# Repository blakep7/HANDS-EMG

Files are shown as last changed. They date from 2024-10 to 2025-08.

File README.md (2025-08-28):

# HANDS-EMG

**HANDS-EMG** is a real-time embedded system designed to read a user's EMG signals and classify their hand movements.

## Project Description
A battery-powered surface electromyography (sEMG) sensor system designed to classify hand movements based on the wearer's muscle activity.
The device utilizes four channels of wet electrodes placed on the user's forearm to capture sEMG signals.
These signals are processed through our procured analog front-end module operating at 2000Hz.
The digitized signals are transmitted to our microcontroller via SPI, where a machine learning algorithm classifies the hand movements based on a pre-trained model.
The system will output the movement classifications via USB, which can be visualized on a PC simulator.
Designed for efficiency, the device operates at a voltage of 3.7V provided by a rechargeable lithium polymer battery for portability.
The current ML model only classifies 3 hand movements: Wrist Flexion, Wrist Extension, and Fist Clench.

## Videos
[Project Overview (Entire Design Process)](https://www.youtube.com/watch?v=24S8prk70tI)

[Demo Video](https://www.youtube.com/watch?v=GeJwxeHSsiM)

## Team

- Blake Pearson
- Noah Marosok
- Kelly Hubbard
- Jayden Sumbillo
- Kirk Young

## About
Developed at **San Diego State University**.

**College of Engineering** -- **Department of Electrical and Computer Engineering (ECE)**

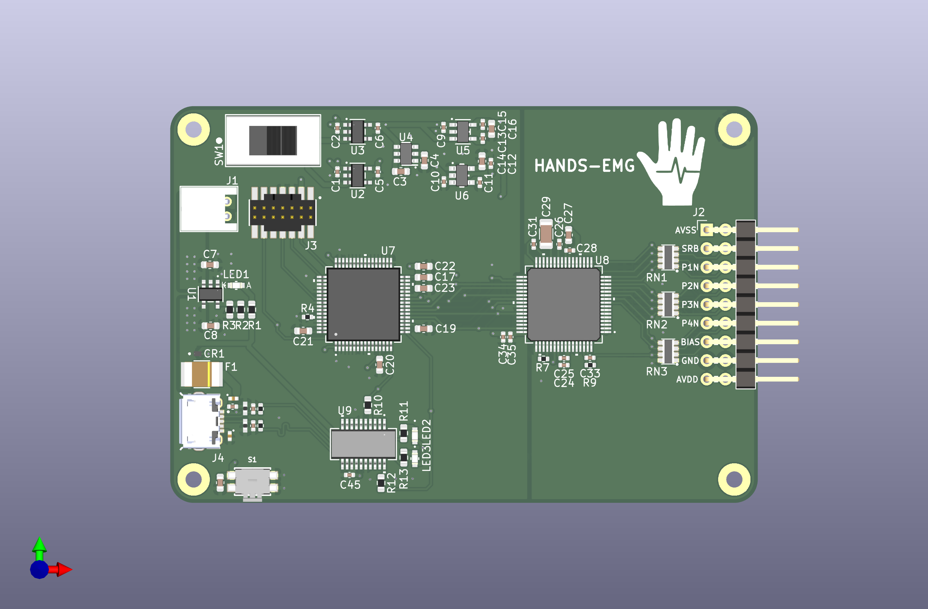
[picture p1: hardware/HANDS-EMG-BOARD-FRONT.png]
Final Board Top 3D Model


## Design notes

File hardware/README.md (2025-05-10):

# PCB Projects
Welcome to the PCB repository! This folder contains four PCB phases:

- **Phase 1**
- **Phase 2**
- **Phase 3**

Each project is fully designed in KiCad and includes schematics, PCB layouts, and 3D models.

## Phase Descriptions

### Phase 1

**Description:**  
Contains 3 PCBs, each designed with a specific purpose.

**Key Components:**
- PMIC Board: Provide power to the following two PCBs
- ADS1299 Board: Our AFE board that handles processing and digitizing EMG signals
- STM32 Board: Our uC board that handles classification and compute

**Warnings**
- Do not use this phase, it taught us alot about PCB design but is riddled with issues
- PMIC Board is less than 50% functional.
    - 3.3V line is actually 3.6V which is absolute maximum of STM32
    - -2.5V line is unstable, due to only using a charge pump without a LDO after
- ADS1299 Board is not functional
    - Unknown issue in PCB design that kills the IC.

### Phase 2

**Description:**  
The team's attempt at a fully integrated PCB design.

**Warnings**
- Do not use this phase
- Board's USB to UART is not functional, no communication possible
- SWD footprint is mirrored

### Phase 3 (Final Phase)

**Description:**
The team's final design. Focused on simplicity, cost, and small dimensions. Fully tested and working

**Key Components**
- STM32L0: Our main compute, has the ML model and classifies the signals
- ADS1299: Our AFE, handles amplifying and digitizing our EMG signals
- FT231X: USB->UART IC for simple communication between STM32 and PC

---

## 3D Model Previews

**Final PCB 3D View:**  
Final Board Top 3D Model
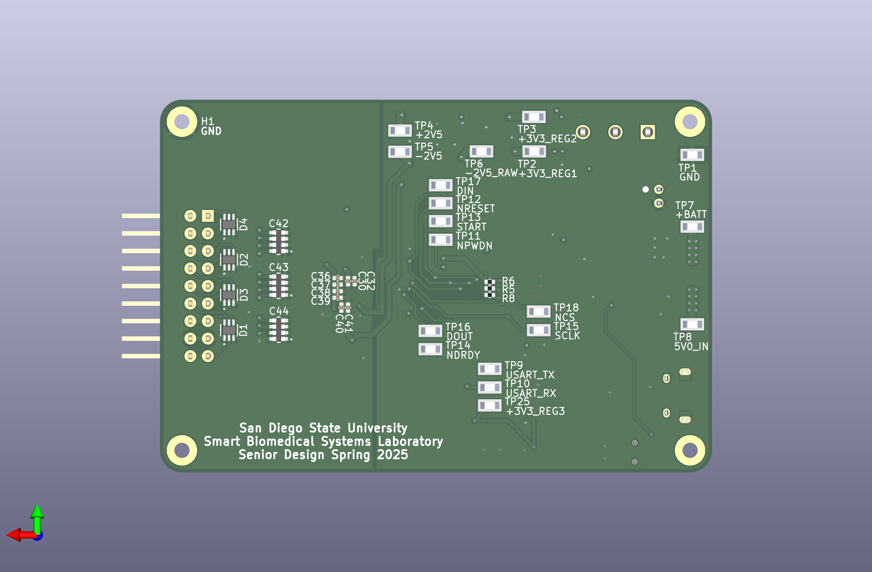
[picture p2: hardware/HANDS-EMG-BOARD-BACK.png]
Final Board Bottom 3D Model


---

## How to Open the Projects

1. Install [KiCad](https://kicad.org/) (v9).
2. Open KiCad and navigate to the respective folder (`phase3`).
3. Open the `.kicad_pro` project file inside each folder.

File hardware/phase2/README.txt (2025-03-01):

How to add components to our hands-emg-lib

1. Download the following from Ultra Librarian (https://app.ultralibrarian.com/)
	- Symbol (.kicad_sym)
	- Footprint (.kicad_mod) (Ignore the -L or -M footprints, use the normal one)
	- 3D Model (.stp or .step)
	* My typical download process
		* 3D CAD Model: Check STEP
		* KiCAD: Check KiCAD v6+
		* Symbol Pin Ordering: Designers preference, read the (i) to understand what this is.
		  Download both and compare to see which one would make a cleaner schematic.
		* Footprint Units: Metric (mm)
	
1b. If you cannot find the component on Ultra Librarian, check Component Search Engine (https://componentsearchengine.com/)
	- Don't mix and match symbols and footprints from different websites
	- If you cant find the components 3d model on ultralibrarian, its fine to download the 3d model from component search engine and attach to footprint from ultralibrarian.
	
1c. After downloading all the files it will be a zip do the following
	- Extract the zip to some folder on your PC.
	- Rename all the files to be the same name (typically part number)
	  Heres an example before and after with the ADS1299 from Ultra Librarian
			Before: 2025-03-01_06-35-12.kicad_sym
					PAG0064A.stp
					PAG64_TEX.kicad_mod
					
			After:  ADS1299-4PAGR.kicad_sym
					ADS1299-4PAGR.stp
					ADS1299-4PAGR.kicad_mod
	
2. Copy the 3d model file from the download into the hands-emg-lib.3dshapes.

3. Import the footprint
	- Open the KiCad Footprint Editor
	- Filter hands-emg-lib
	- Right click hands-emg-lib
	- Import Footprint
	- Select the footprint file from the download
	- Open the footprints properties menu
		- Check the "Value" and confirm its the proper manufacturer's part number (if you had to rename footprint file then it's likely incorrect)
		- Add a description of what it is (typically not part number, the description helps to search the part)
		- Go to the 3D model tab
		- Click the little folder icon to add 3d model
		- Select the 3d model file in the hands-emg-lib.3dshapes folder
		- Rotate/Offset model to fit the footprint (scaling is needed in very few cases)
	- Click OK to close the footprint properties menu
	- File -> Save
	- Dont change the name, filter for hands-emg-lib, click hands-emg-lib, click OK.
	
4. Import the symbol
	- Open the KiCad Symbol Editor
	- Filter hands-emg-lib
	- Right click hands-emg-lib
	- Import Symbol
	- Select the symbol file from the download
	- Open the symbol properties menu
		- Click on footprint
		- Click on the little books icon to open the "footprint chooser"
		- Filter for hands-emg-lib
		- Select the footprint imported in step 3 under hands-emg-lib (for this component)
		- Click OK
		- Add datasheet link under "Datasheet" field
		- Add description
		- Create new field
			- Click '+' symbol
			- Name this field procurement
			- Make sure to un-check the show column for this field
			- Provide purchase link for this component
				- Try to keep it all from DigiKey
				- No obsolete parts, no limited stock, must be immediately aviable, no lead time
		- Click OK to close symbol properties menu
	- File -> Save
	
5. Commit these changes to git and push so we all have easy access to the components.

6. Use your imported component. (Seach for hands-emg-lib in symbol/footprint selection menu when placing)

7. You can delete the downloaded files from your downloads folder, importing them has copied them all to our project.

Note! This library is 'project' scoped, there is no need to edit any of your kicad settings to use it. It will not be aviable in other projects.

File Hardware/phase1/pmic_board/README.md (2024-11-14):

# HANDS-EMG

## Hand Activity Neural Detection using SEMG

## Project Description
A battery-powered surface electromyography (sEMG) sensor system designed to classify hand movements based on the wearer's muscle activity.
The device utilizes four channels of wet electrodes placed on the user's forearm to capture sEMG signals.
These signals are processed through our procured analog front-end module operating at a minimum of 2000 samples per second.
The digitized signals are transmitted to our microcontroller via SPI, where a machine learning algorithm classifies the hand movements based on a pre-trained model.
Our responsibilities include configuring the analog front-end module, programming a low-power microcontroller, integrating the system on a custom PCB, and training the machine learning model for accurate classification.
The system will output the movement classifications via USB, which can be visualized on a PC simulator.
Designed for efficiency, the device operates at a voltage of 3.7V provided by a rechargeable lithium polymer battery for portability.

## Contributors

- Kelly Hubbard
- Noah Marosok
- Blake Pearson
- Jayden Sumbillo
- Kirk Young

## License 📜

This project is licensed under the [Apache License 2.0](LICENSE).

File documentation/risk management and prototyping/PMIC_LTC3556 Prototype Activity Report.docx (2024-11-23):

Prototype Activity:

PCB Design

This report outlines the prototyping activities conducted to address two significant risks identified during the risk management meeting: PCB Design Complexity (Risk 5) and System Integration (Risk 6). The primary focus was on completing 20% of the PCB design process, including schematic creation, component placement, and routing in KiCad. The team conducted extensive Design Rule Checks (DRC) to identify and resolve errors early in the design phase, ensuring the designs are ready for fabrication and debugging. While physical testing is not yet possible, this phase lays a strong foundation for addressing these risks in future iterations.

System Description

The HANDS-EMG system relies on multiple subsystems to achieve functionality:

1. Power Management: The LTC3556EUFD_PBF provides efficient battery charging and a stable 3.3V output, powering all critical components.
2. Signal Processing: The ADS1299 captures and processes surface electromyography (sEMG) signals, which are then transmitted via SPI to the control module.
3. Control Module: The STM32L496ZGT6 microcontroller processes incoming data and facilitates communication between the signal processing and the machine learning classifier.

Given the complexity of integrating these subsystems, the team adopted a modular approach. Three separate PCBs were designed for power management, signal processing, and control modules. These modular designs allow for isolated testing and debugging before integration into a single unified PCB.

### Initial Identification of Risks

The risk management meeting identified the following significant risks for the project, with this activity addressing Risks 5 and 6:

Table X: Risk Summary

No. | Risk | Probability | Impact | Mitigation
5 | PCB Design Complexity | 3 | 4 | Designed modular PCBs for debugging before integration.
6 | System Integration | 3 | 5 | Tested modules individually with debugging tools before integration.

1. PCB Design Complexity (Risk 5): Routing, signal integrity, and managing space for components like the LTC3556EUFD_PBF, ADS1299, and STM32L496ZGT6 make PCB design challenging. Errors in design could delay the project or result in fabrication failures.
2. System Integration (Risk 6): The subsystems must communicate effectively through SPI and power lines. Inconsistencies or misalignments in protocols, signals, or power delivery could jeopardize the system’s functionality

Prototype Activity

This activity focused on the initial PCB design phase, addressing 20% of the overall design effort and emphasizing schematic creation, layout design, and error identification through DRC. Key steps included:

1. Schematic Design:

Created schematics for power management, signal processing, and control modules in KiCad, using recommended components from the manufacturer datasheets.

Included decoupling capacitors, inductors, and connectors to ensure proper functionality and ease of debugging.

PCB Layout Design:

Power Management PCB: Designed for the LTC3556EUFD_PBF, focusing on stable 3.3V output and efficient battery charging with minimal ripple.

1. Design Rule Checks (DRC):

Conducted DRC in KiCad to identify and resolve routing errors, ensuring proper trace clearances, via placements, and component footprints.

Resolved all detected issues, such as overlapping traces and incorrect pad connections, to ensure compliance with manufacturing standards.

2. Debugging Preparation:

Added test points and connectors to each PCB to facilitate real-time monitoring and troubleshooting during future testing.

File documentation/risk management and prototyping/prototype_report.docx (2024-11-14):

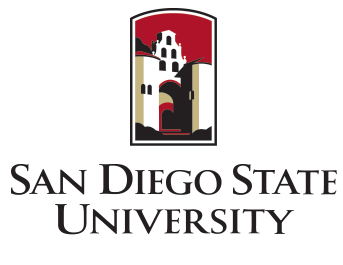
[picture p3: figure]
sdsu_logo - M @ College

College of Engineering, Department of Electrical and Computer Engineering

EE/COMPE 491W Senior Design

Prototype Report

Team HANDS-EMG

ECE Team 9 – Hand Activity Neural Detection using sEMG

EE Members:

Kelly Hubbard, Jayden Sumbillo, Kirk Young

CE Members:

Noah Marosok, Blake Pearson

Sponsor:

SDSU Department of Electrical and Computer Engineering

SDSU Smart Biomedical Systems Lab

Kelly Hubbard Electrical Engineering | Jayden Sumbillo Electrical Engineering | | Kirk Young Electrical Engineering

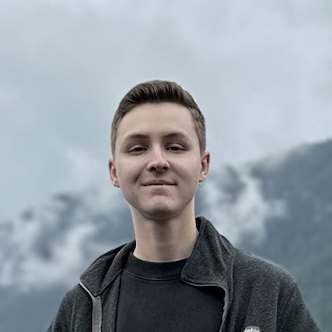
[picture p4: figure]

Noah Marosok Computer Engineering | | Blake Pearson Computer Engineering

No table of figures entries found.

# Executive Summary

Our ECE team is developing a battery-powered surface electromyography (sEMG) sensor system designed to classify hand movements based on the wearer’s muscle activity. The device utilizes four channels of wet electrodes placed on the user’s forearm to capture sEMG signals. These signals are processed through our procured analog front-end module operating at a minimum of 2000 samples per second. The digitized signals are transmitted to our microcontroller via SPI, where a machine learning algorithm classifies the hand movements based on a pre-trained model. Our responsibilities include configuring the analog front-end module, programming a low-power microcontroller, integrating the system on a custom PCB, and training the machine learning model for accurate classification. The system will output the movement classifications via USB, which can be visualized on a PC simulator. Designed for efficiency, the device operates at a voltage of 3.7V provided by a rechargeable lithium polymer battery for portability.

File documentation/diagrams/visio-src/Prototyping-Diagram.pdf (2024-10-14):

## Phase 1:

### Isolated Subsystem Prototyping

## Phase 2:

### Subsystem Integration Pairing

## Phase 3:

### Total Subsystem Integration

## Phase 4:

### Subsystem Integration on PCB

## Phase 5:

### Total System Integration on PCB

-ADS Eval kit is
configured to find
proper biasing of
amplifier to match
training data
-STM32 FSM
subroutines are
designed and
tested
-Power delivery
tested on
breadboard with DC
bench supply with
voltage swing
-Machine learning
architecture is
created and tested
with existing
dataset
-SPI comms.
Established verified
by logic analyzer

-ADS and STM32 SPI
comm. Established

-ADS and STM32
powered with
simulated
computational load
from power
delivery circuit

-Machine learning
model (.tflite)
uploaded to STM32
aiming to classify
training data
gestures via USB 2.0

-Simulator
demonstrates
proper articulation
of poses

-Breadboard power
system supplies to
both eval kits, EMG
measurements
passed to STM,
inference passed to
simulator
-Every subsystem is
now connected as
demonstrated
within the main
block diagram

-Development of
PCB for each
individual
subsystem, with
their respective I/O,
or ESD
considerations
accounted for.
Same system setup
as phase 3
-multi-layer boards
for high pin IC
packages
-heat dissipation
assemblies for
packages past
ambient
temperature
dissipation
threshold

-Total integration of
all subsystems on
one PCB
-PCB subsystems
routed with
considerations for
additional noise
and heat
-added layers

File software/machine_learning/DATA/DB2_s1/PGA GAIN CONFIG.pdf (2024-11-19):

Using PGA GAIN 12
Solid mid area, in case of muscle tense or cramp (happens often with this) gain not at highest can be okay with those high signal spikes if they happen while still capturing everything we need

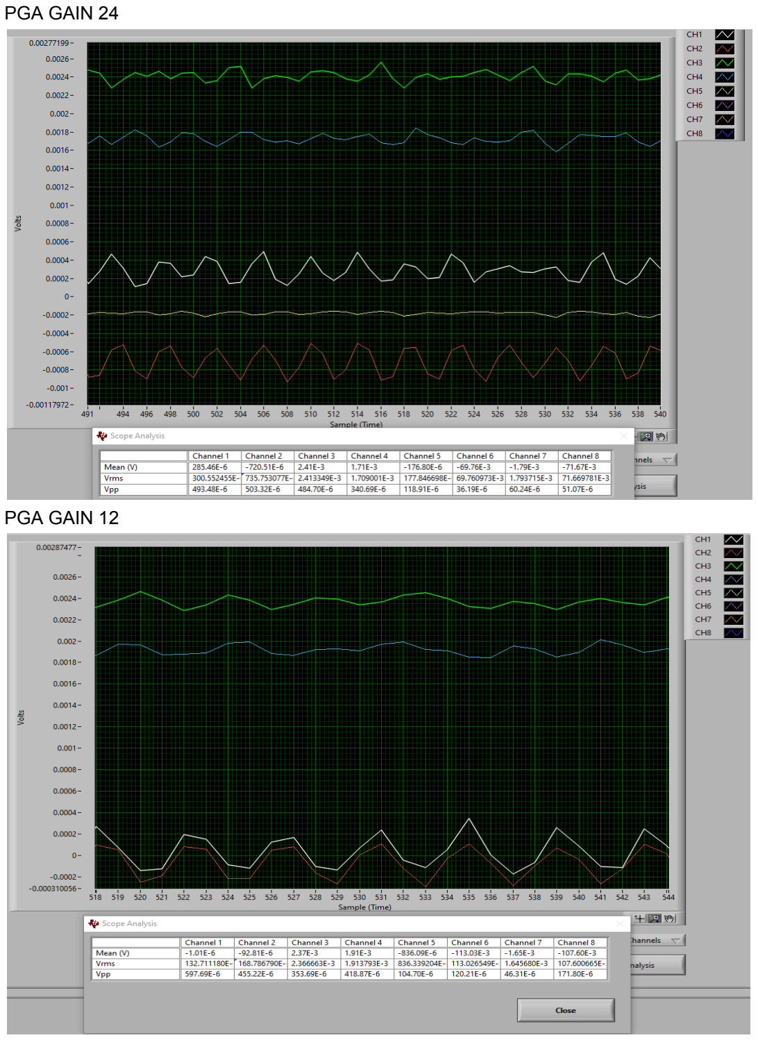
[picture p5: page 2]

PGA GAIN 24

PGA GAIN 12

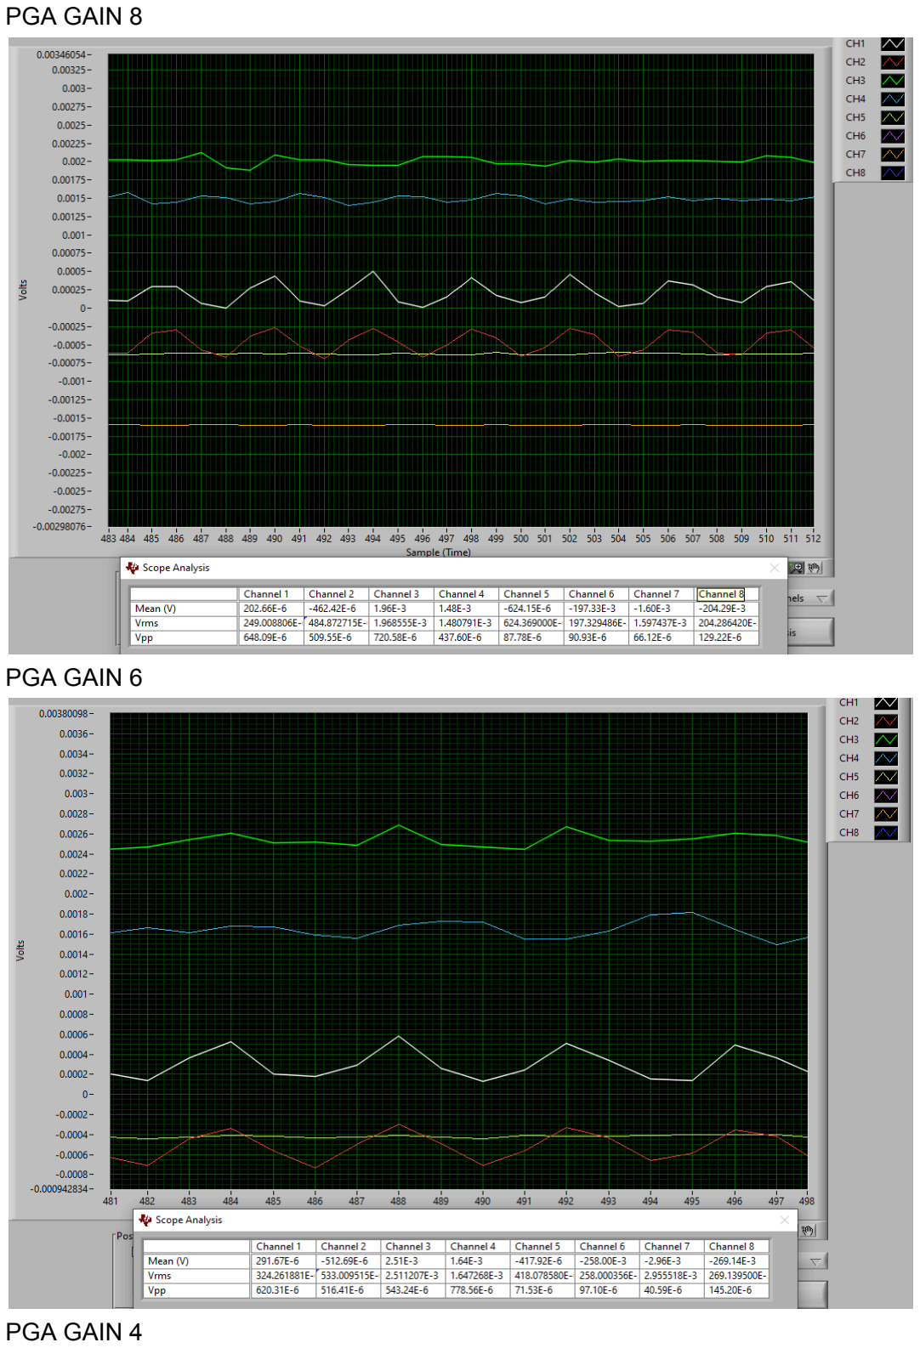
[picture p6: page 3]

PGA GAIN 8

PGA GAIN 6

PGA GAIN 4

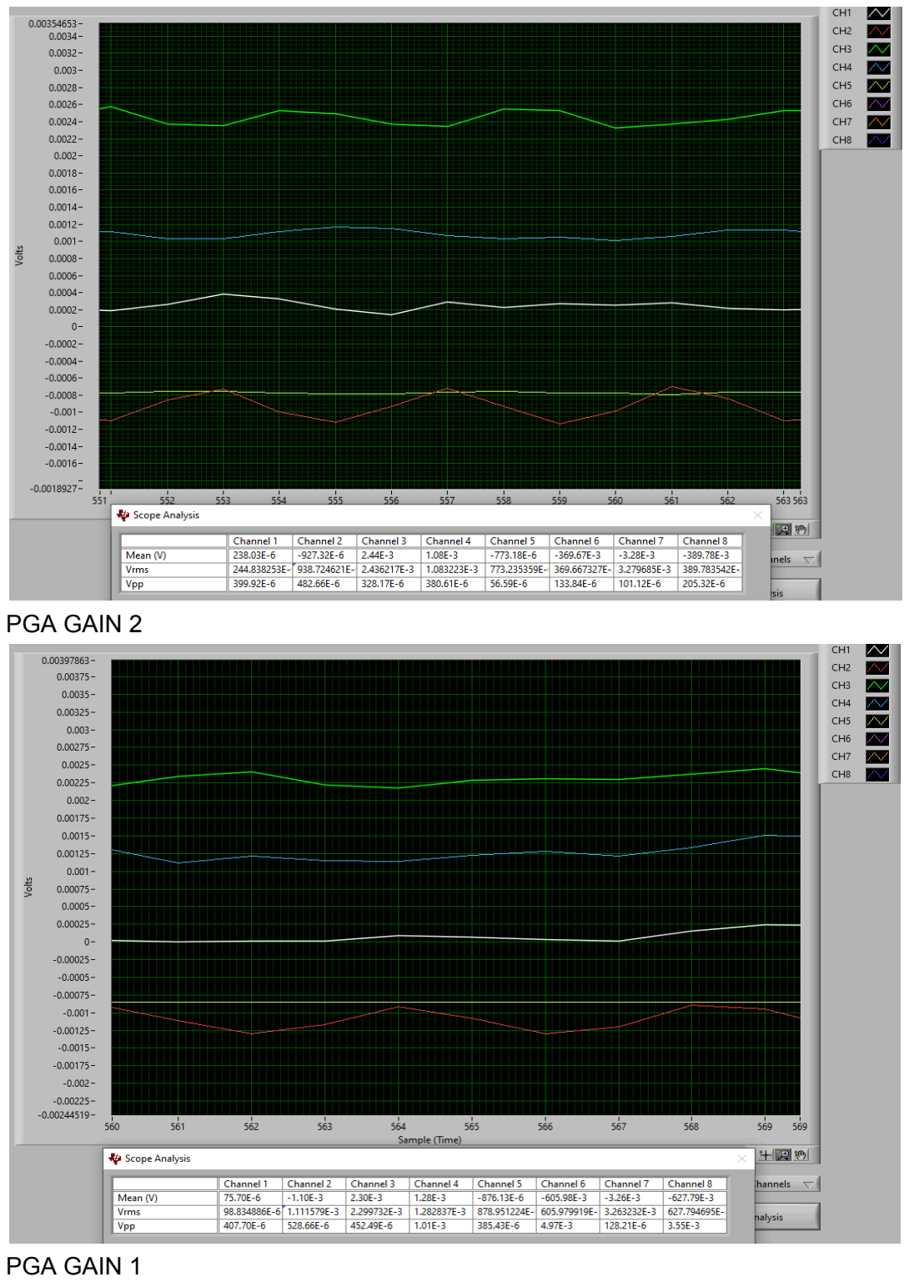
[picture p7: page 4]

PGA GAIN 2

PGA GAIN 1

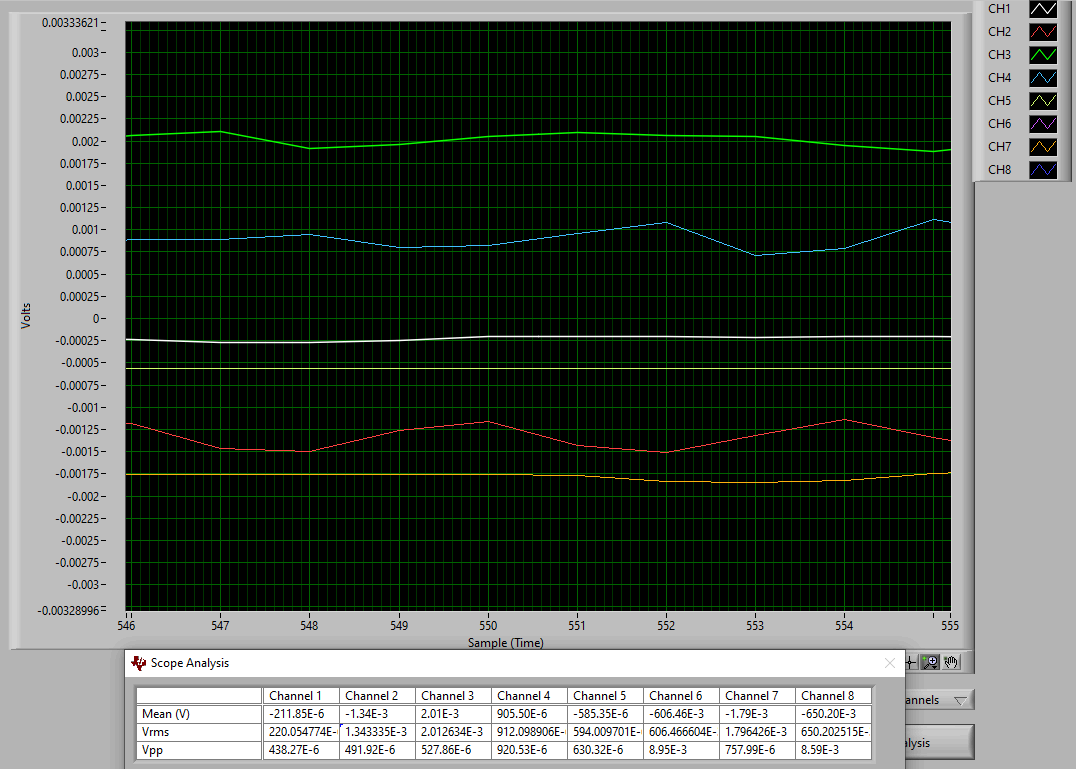
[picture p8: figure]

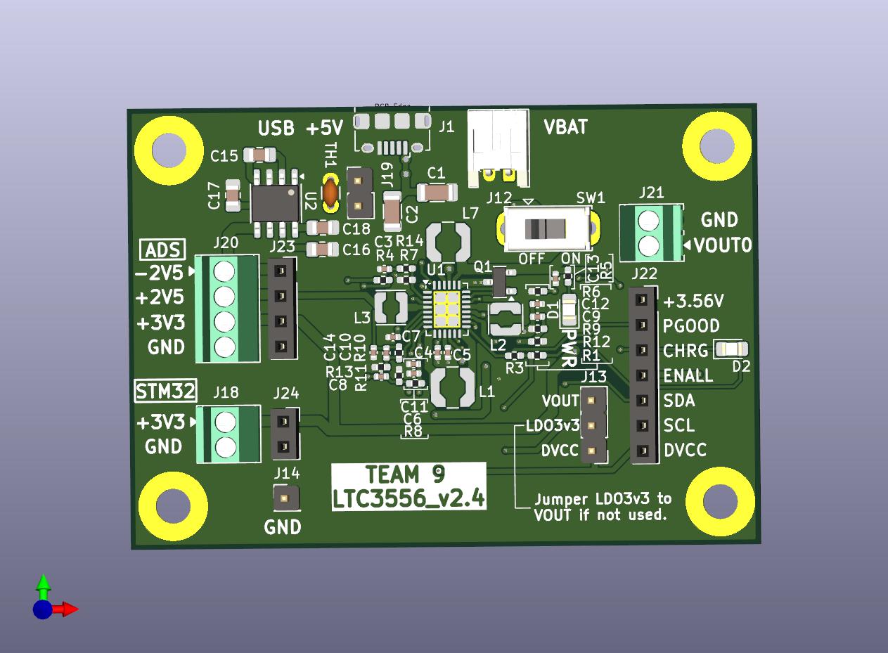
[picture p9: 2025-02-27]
hardware/phase1/pmic_board/LTC3556_v2.4.jpg

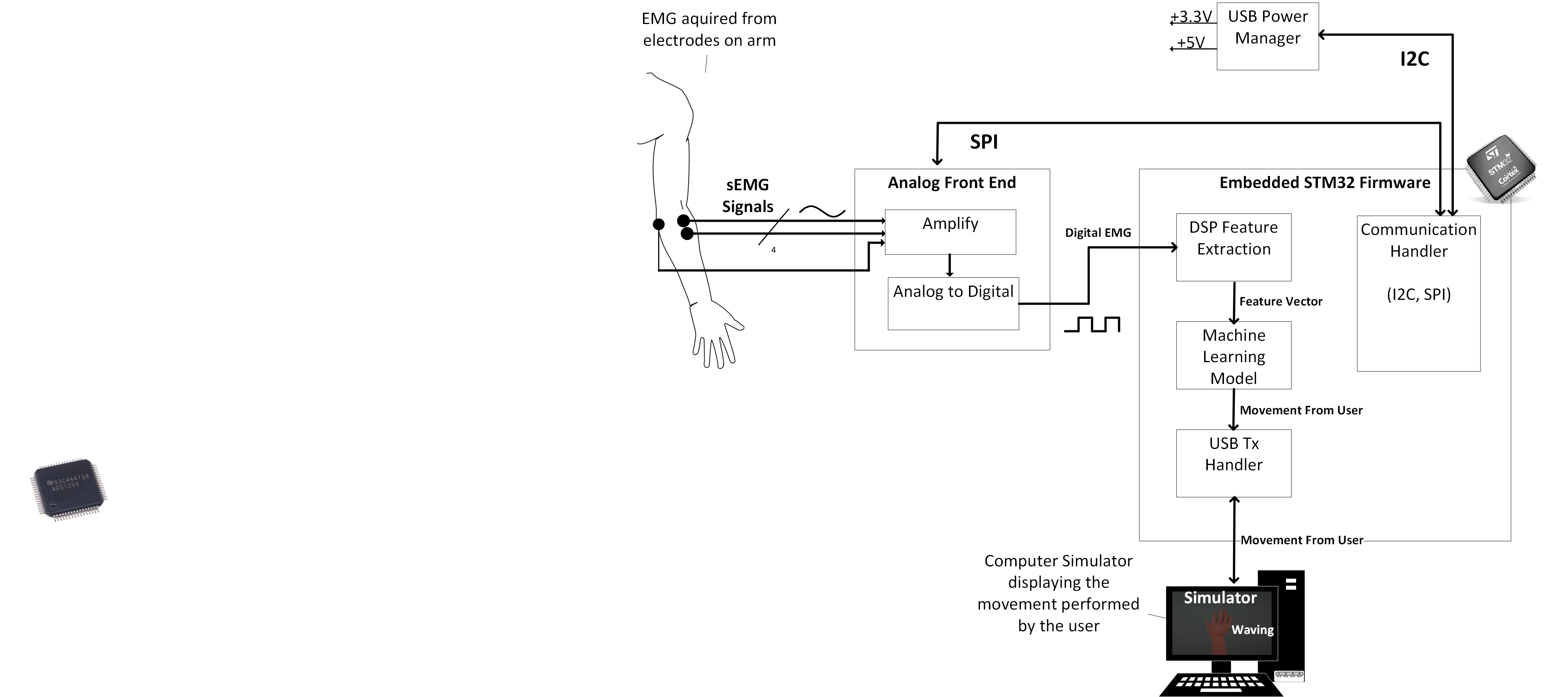
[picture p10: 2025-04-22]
documentation/system description and design/integration-rediness-report-pics/Software.png

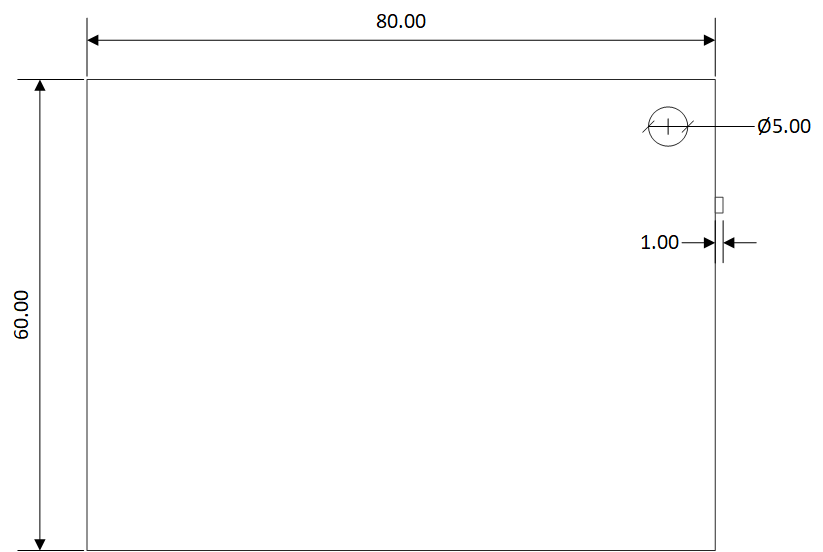
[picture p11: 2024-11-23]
documentation/diagrams/visio-src/Mechanical-Drawing-topdown.vsdx.png

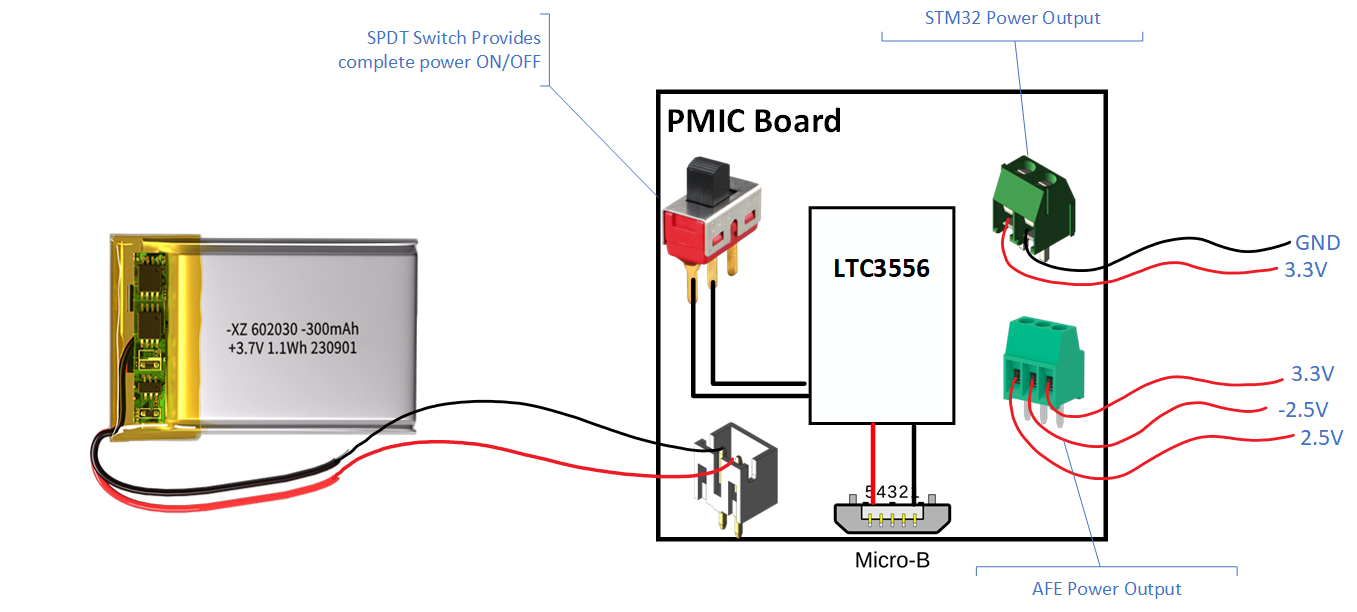
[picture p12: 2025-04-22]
documentation/system description and design/integration-rediness-report-pics/PMIC_Simple.png

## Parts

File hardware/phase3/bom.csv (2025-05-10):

Designator | Footprint | Quantity | Value | LCSC Part #
C1, C10, C12, C15, C2, C5, C6, C9 | 0402 | 8 | 2u2 |  | GRM155R61C225KE44D
C11, C48 | 0402 | 2 | 0u01 |  | CC0402KRX7R7BB103
C13, C24, C26, C30, C31, C32, C34, C36, C38, C40 | 0402 | 10 | 1u |  | CC0402KRX7R5BB105
C14, C16, C27, C3, C4 | 0603 | 5 | 10u |  | GRM188C80G106KE47D
C17, C19, C20, C21 | 0603 | 4 | 100n |  | CC0603KRX7R7BB104
C18 | 0603 | 1 | 0u1 |  | CC0603KRX7R7BB104
C22, C7, C8 | 0603 | 3 | 4u7 |  | CL10A475KP8NNNC
C23 | 0603 | 1 | 1u |  | CC0603KRX7R5BB105
C25, C28, C35, C37, C39, C41, C45 | 0402 | 7 | 0u1 |  | CC0402KRX7R7BB104
C29 | 1206 | 1 | 100u |  | CC1206MKX5R5BB107
C33 | 0402 | 1 | 1n |  | CC0402KRX7R7BB102
C42, C43, C44 | CA064C102K5RAC7800 | 3 | CA064C102K5RACTU |  | CA064C102K5RACTU
C46, C47 | 0402 | 2 | 47p |  | CC0402JRNPO9BN470
CR1 | ESDALC6V1-1M2 | 1 | ESDALC6V1-1M2 |  | ESDALC6V1-1M2
D1, D2, D3, D4 | TPD4E1B06DCKR | 4 | TPD4E1B06DCKR |  | TPD4E1B06DCKR
F1 | MF-MSMF050-2 | 1 | MF-MSMF050-2 |  | MF-MSMF050-2
FL1, FL2 | MPZ1005S300CT000 | 2 | MPZ1005S300CT000 |  | MPZ1005S300CT000
H1, H2, H3, H4 | MountingHole_2.2mm_M2_Pad | 4 | MountingHole_Pad |  | DNP
J1 | S2B-PH-K-S | 1 | S2B-PH-K-SLFSN |  | S2B-PH-K-SLFSN
J2 | PinHeader_2x09_P2.54mm_Horizontal | 1 | Conn_02x09_Odd_Even |  | PH2RA-18-UA
J3 | FTSH-107-01-L-DV-K | 1 | FTSH-107-01-L-DV-K |  | FTSH-107-01-L-DV-K
J4 | 10118194-0001LF | 1 | 10118194-0001LF |  | 10118194-0001LF
LED1, LED3 | LTST-C191KRKT | 2 | LTST-C191KRKT (RED) |  | LTST-C191KRKT (RED)
LED2 | LTST-C191KGKT | 1 | LTST-C191KGKT (GREEN) |  | LTST-C191KGKT (GREEN)
R1 | 0603 | 1 | 330R |  | RC0603JR-07330RL
R10, R11, R12, R13 | 0603 | 4 | 1K |  | RC0603FR-071KL
R14, R15 | 0402 | 2 | 22R |  | RC0402FR-0722RL
R16, R17 | CG0402MLC-05LG | 2 | CG0402MLC-05LG |  | CG0402MLC-05LG
R2 | 0603 | 1 | DNP |  | DNP
R3 | 0603 | 1 | 2K |  | RC0603FR-072KL
R4, R5, R6, R7, R8 | 0402 | 5 | 10K |  | ERJ-2RKF1002X
R9 | 0402 | 1 | 1M |  | RC0402JR-071ML
RN1, RN2, RN3 | CAY16-222J4LF | 3 | CAY16-222J4LF |  | CAY16-222J4LF
S1 | 4.36331E+11 | 1 | 4.36331E+11 |  | 4.36331E+11
SW1 | SLW-1276864-4A-D | 1 | SLW-1276864-4A-D |  | SLW-1276864-4A-D
TP1, TP10, TP11, TP12, TP13, TP14, TP15, TP16, TP17, TP18, TP2, TP25, TP3, TP4, TP5, TP6, TP7, TP8, TP9 | 5015 | 19 | 5015 |  | 5015
U1 | MCP73831T-2ACI-OT | 1 | MCP73831T-2ACI/OT |  | MCP73831T-2ACI/OT
U2, U3 | MCP1754T-3302E-OT | 2 | MCP1754T-3302E/OT |  | MCP1754T-3302E/OT
U4 | LM2664M6X-NOPB | 1 | LM2664M6X/NOPB |  | LM2664M6X/NOPB
U5 | TPS73225DBVR | 1 | TPS73225DBVR |  | TPS73225DBVR
U6 | TPS72325DBVR | 1 | TPS72325DBVR |  | TPS72325DBVR
U7 | STM32L496RGT6 | 1 | STM32L496RGT6 |  | STM32L496RGT6
U8 | ADS1299-4PAGR | 1 | ADS1299-4PAGR |  | ADS1299-4PAGR
U9 | FT231XS-R | 1 | FT231XS-R |  | FT231XS-R

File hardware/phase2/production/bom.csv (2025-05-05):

Designator | Footprint | Quantity | Value | LCSC Part #
BAT | CONN_S2B-PH-K-S_JST | 1 | S2B-PH-K-SLFSN
C1 | CAPC1608X90N | 1 | 10uF
C11, C26, C3, C34, C9 | CAPCAF50P200X125X85-8 | 5 | CKCL44X7R1H102M085AA
C12, C13, C15, C24, C28, C5 | YAG_CC0402_YAG | 6 | 0.1uF |  |  | 1x02 VERT PIN | 4
C14, C17, C18, C19, C21, C22, C27, C6, C7 | CAP_CC0402KRX7R5BB105_YAG | 9 | 1uF |  |  | 1x03 VERT PIN | 4
C16 | YAG_CC0402_YAG | 1 | 1nF |  |  | MicroB | 4
C2 | CAP_CC1206_YAG | 1 | 100uF |  |  | 1x02 VERT HDR | 4
C45, C46, C50, C51, C60, C61, C65, C66 | CAPC2012X95N | 8 | 10uF |  |  | 1x01 VERT PIN | 9
C47, C48, C49, C58, C62 | CAPC1608X90N | 5 | 1uF |  |  | 1x07 VERT HDR | 4
C57 | CAPC1608X90N | 1 | 0.1uF |  |  | TERM BLOCK 2 POS | 3
C59, C63, C64 | CAP_GRM18_MUR | 3 | 2.2uF |  |  | TERM BLOCK 4 POS | 1
C67 | CAPC1608X90N | 1 | 0.01uF |  |  | LTC3556 | 1
D2, D3, D4, D5, D6, D7 | DCK6_TEX | 6 | TPD4E1B06DCKR |  |  | 3.3uH LPS4018 | 1
DC1 | CC0402N_YAG | 1 | 0.01uF |  |  | 2.2uH LPS4018 | 1
DC2, DC3 | G-033_MUR | 2 | 47pF |  |  | SI233DS-T1 FET | 2
DD3 | SOD882_STM | 1 | D_Small |  |  | TC7660C0A INV CRG PUMP | 1
DD4 | LED_LTST-C191KRKT_LTO | 1 | RED |  |  | LED BLUE 0805 150080BS75000 | 3
DD5 | LED_LTST-C191KGKT_LTO | 1 | GREEN |  | CAPS | 10uF 1206 | 8
DF1 | FUSE_F050-2 | 1 | Fuse_Small |  |  | 0.1uF 1206 | 9
DL2 | IND_1005_TDK | 1 | L_Small |  |  | 0.1uf 0402 | 2
DR1, DR2 | RC0402N_YAG | 2 | 27 |  |  | 1uF 0402 | 11
DR3, DR4 | RC0402N_YAG | 2 | 330 |  |  | 130pF 0402 | 5
DR6, DR7 | RC0402N_YAG | 2 | 1K |  |  | 10pF 0402 | 8
J1 | AMPHENOL_68021-226HLF | 1 | Conn_02x13_Odd_Even |  |  | 10uF 0805 | 12
L1, L2, L4, L5 | INDC2012X87N | 4 | 3.3uH |  | END | 10uF 0402 | 18
PC1, PC11, PC4, PC5, PC8, PC9 | C1005X5R0J105M | 6 | 1uF |  |  | 300mA SS12D07-VG Slide Switch | 1
PC10 | C1608X5R0J225M | 1 | 2.2uF |  |  | 4.7uH LPS3015 | 1
PC12, PC21, PC23 | C1608X5R0J106M | 3 | 10uF
PC13 | GRM31CR60J107ME39L | 1 | 100uF
PC14 | LMK316BJ476ML-T | 1 | 47uF
PC15, PC20, PC22, PC24 | 04025A100KAT | 4 | 10pF
PC16, PC28, PC29 | C1005X5R1C104K | 3 | 0.1uF
PC17 | 04025A331KAT | 1 | 330pF
PC18 | 04025A330KAT | 1 | 33pF
PC19, PC6, PC7 | JMK212BJ226MG-T | 3 | 22uF
PC2 | GRM21BR61A106KE19 | 1 | 10uF
PC3 | GRM21BR61A106KE19L | 1 | 10uF
PD2 | LED-0603 | 1 | GREEN (CHRG)
PD3 | LED-0603 | 1 | RED (FAULT)
PL1 | LPS4018-332MLC | 1 | 3.3uH
PL2, PL3 | LPS4018-222MLC | 2 | 2.2uH
PL4, PL5 | IND_LPS4018-472MRC | 2 | 4.7uH
PQ1 | SI2333DS | 1 | PMOS
PR10, PR12, PR4 | CRCW04020000Z0EDC | 3 | 0
PR13, PR18, PR23, PR26 | CRCW040220R0FKED | 4 | 20
PR14 | CRCW040288K7FKED | 1 | 88.7k
PR15 | CRCW040216K9FKED | 1 | 16.9K
PR16 | CRCW04023K01FKED | 1 | 3.01K
PR17 | CRCW04022K00FKED | 1 | 2K
PR19 | CRCW040215K0FKED | 1 | 15K
PR2, PR29, PR30, PR31 | CRCW04021R00JNED | 4 | 1
PR20 | CRCW0402324KFKED | 1 | 324K
PR21 | CRCW0402121KFKED | 1 | 121K
PR22 | CRCW0402105KFKED | 1 | 105K
PR24 | CRCW0402806KFKED | 1 | 806K
PR25 | CRCW0402649KFKED | 1 | 649K
PR27 | CRCW0402232KFKED | 1 | 232K
PR28 | CRCW0402464KFKED | 1 | 464K
PR3, PR9 | CRCW0402100KFKED | 2 | 100K
PR34, PR35, PR80, PR81, PR82, PR83 | CRCW04021K00JNED | 6 | 10K
PR5, PR7 | CRCW04021K00JNED | 2 | 1K
PR6, PR8 | CRCW04022K20FKED | 2 | 2.2K
R1, R2, R3, R4, R6 | CAY16_BRN | 5 | 2.2K
R5 | RC0402N_YAG | 1 | 1M
SB1 | PTS645S_SMTR92_CNK | 1 | USER
SB2 | PTS645S_SMTR92_CNK | 1 | RESET
SC28, SC29, SC30, SC31, SC32, SC33, SC34, SC49, SC50, SC51, SC53, SC57, SC58, SC61 | CAPC1608X90 | 14 | 100nF
SC40 | YAG_CC0402_YAG | 1 | [N/A]
SC41 | YAG_CC0402_YAG | 1 | 100nF
SC42 | CAPMP3216X166 | 1 | 4.7uF
SC52, SC54 | CAPC1608X90 | 2 | 4.7uF_X54_0603
SC56, SC59 | CAPMP3216X166 | 2 | 1uF
SC60 | CAPC1608X90 | 1 | 1uF_X5R_0603
SCN14 | MOLEX_47589-1001 | 1 | USB_B_Micro
SD10 | SOT65P210X110-5N | 1 | ESDALC6V1W5
SD6 | DIODE_ESDALC6V1-1U2 | 1 | ESDALC6V1_1U2
SL3 | FB0603 | 1 | FerriteBead_Small
SLD7 | LED-0603 | 1 | Red
SLD8 | LED-0603 | 1 | Green
SR38, SR52 | RESC1607X60N | 2 | 10K
SR41, SR43 | RESC1607X60N | 2 | 330
SR42 | RESC1607X60N | 1 | 220K
SR44 | RESC1607X60N | 1 | 100
SR45 | RESC1608X55N | 1 | 620
SR48 | RESC1607X60N | 1 | 22K
SR49, SR51 | RESC1608X55 | 2 | 47K
SR54, SR55 | RESC1607X60N | 2 | 10K (DNP)
ST2 | SOT-23 | 1 | 9013
SU12 | SOT95P280X145-5N | 1 | STMPS2151STR
SU13 | SOT-23-6 | 1 | USBLC6-2SC6
SWD1 | CON14_2X7_DUK_FTSH_SAI | 1 | FTSH-107-01-L-DV-K
TP1 | KEYSTONE_5000 | 1 | RAW
TP2 | KEYSTONE_5000 | 1 | LDO3V3
TP4 | KEYSTONE_5000 | 1 | +3V3
TP5 | KEYSTONE_5001 | 1 | -5V
TP6 | KEYSTONE_5001 | 1 | +5V
TP7 | KEYSTONE_5001 | 1 | +2V5
TP8 | KEYSTONE_5001 | 1 | -2V5
U1 | QFP64P50_1200X1200X120L60X22N | 1 | ADS1299CPAG
U2 | LQFP144-20x20mm_STM | 1 | STM32L496ZGT6
U3 | QFN-38_UFE_LIT | 1 | LTC3586EUFE-3-PBF
U4 | QFN20_FT231XQ_FTD | 1 | FT231XQ-R
U6 | SOT95P280X145-5N | 1 | TPS60403DBVT
U8 | SOT95P280X145-5N | 1 | TPS72325DBVT
U9 | SOT95P280X145-5N | 1 | TPS73225DBVT
 |  | 202

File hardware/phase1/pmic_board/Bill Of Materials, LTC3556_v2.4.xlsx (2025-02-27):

Qty | Reference Designator | Description | Value | Manufacturer | Mfr Part Number | Distributor | Dist. Part Number | Cost Each (10 Pcs) | Order Qty | Line Total | Footprint | Datasheet | DNP
1 | C1 | Capacitor, 1206, 50V, X5R | 10uF | Murata Electronics | GRM319R61E106KA12D | Mouser.com | 81-GRM319R61E106KA2D (https://www.mouser.com/ProductDetail/Murata-Electronics/GRM319R61E106KA12D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) | 0.3160 |  |  | 1206 | ~
7 | C11,C12,C13,C14,C15,C16,C18 | Capacitor, 0402, 10V, X5R | 10uF | Murata Electronics | GRM155R61A106ME11D | Mouser.com | 81-GRM155R61A106ME1D (https://www.mouser.com/ProductDetail/Murata-Electronics/GRM155R61A106ME11D) | 0.0590 |  |  | 0402
1 | C2 | Capacitor, 1206, 50V, X5R | 100nF | Murata Electronics | GCM319R71H104KA37J | Mouser.com | 81-GCM319R71H104KA7J (https://www.mouser.com/ProductDetail/Murata-Electronics/GCM319R71H104KA37J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) | 0.2100 |  |  | 1206 | ~
2 | C3,C5 | Capacitor, 0402, 25V, X5R | 100nF | Murata Electronics | GRM155R61E104KA87J | Mouser.com | 81-GRM155R61E104KA7J (https://www.mouser.com/ProductDetail/Murata-Electronics/GRM155R61E104KA87J) | 0.0570 |  |  | 0402
3 | C5,C6,C7 | Capacitor, 0402, 25V, X5R | 1uF | Murata Electronics | GRM155R61E105KA12D | Mouser.com | 81-GRM155R61E105KA2D (https://www.mouser.com/ProductDetail/Murata-Electronics/GRM155R61E105KA12D) | 0.0280 |  |  | 0402 | ~
1 | C8 | Capacitor, 0402, 25V, COG (NPO) | 130pF | Murata Electronics | GRM1555C1E131JA01D | Mouser.com | 81-GRM1555C1E131JA1D (https://www.mouser.com/ProductDetail/Murata-Electronics/GRM1555C1E131JA01D?qs=MY6wChARw2zMLr3JiRnbGg%3D%3D) | 0.0580 |  |  | 0402 | ~
2 | C9,C10 | Capacitor, 0402, 25V, COG (NPO) | 10pF | Murata Electronics | GRM1555C1E100JA01D | Mouser.com | 81-GRM1555C1E100JA1D (https://www.mouser.com/ProductDetail/Murata-Electronics/GRM1555C1E100JA01D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) | 0.0260 |  |  | 0402 | ~
1 | C17 (DNI) | Capacitor, 1206, 50V, X5R | 10uF | Murata Electronics | GRM319R61E106KA12D | Mouser.com | 81-GRM319R61E106KA2D (https://www.mouser.com/ProductDetail/Murata-Electronics/GRM319R61E106KA12D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) | 0.3160 |  |  | 1206 | ~
1 | D1 | LED, Green Diffused, 0805, 20mA | Green | Kingbright | APT2012CGCK | Mouser.com | 604-APT2012CGCK (https://www.mouser.com/ProductDetail/Kingbright/APT2012CGCK?qs=VdjlWU%2FzoOEv1TxC2gMNzg%3D%3D) | 0.1770 |  |  | 0805 | ~
1 | D2 | LED, Red, Diffused, 0805, 20mA | Red | Kingbright | AP2012ID | Mouser.com | 604-AP2012ID (https://www.mouser.com/ProductDetail/Kingbright/AP2012ID?qs=LBL%2Fib7enC8wCccbrJmdIQ%3D%3D) | 0.2690 |  |  | 0805
1 | J1 | USB 2.0 Micro B | USB_B_Micro | Amphenol ICC (FCI) | 10118194-0001LF | Mouser.com | 649-10118194-0001LF (https://www.mouser.com/ProductDetail/Amphenol-FCI/10118194-0001LF?qs=Ywefl8B65e4FIdY8OWfRQA%3D%3D) | 0.4100 |  |  | USB-2.0 Micro B | ~
13 | J2,J3,J4,J5,J6,J7,J8,J9,J10,J11,J15,J16,J17 | Header, Female Socket | Conn_01x01_Pin | Pololu.com | #1111 | Pololu.com | DO NOT BUY - SENIOR DESIGN STOCK! | 0.0000 |  |  | 2.54mm Pitch Thru-Hole | ~
1 | J14 | Header, Male Pin | Conn_01x01_Pin | Pololu.com | #966 | Pololu.com | DO NOT BUY - SENIOR DESIGN STOCK! | 0.0000 |  |  | 2.54mm Pitch Thru-Hole
1 | J19 | Header, Male Pin | Conn_01x02_Pin | Pololu.com | #966 | Pololu.com | DO NOT BUY - SENIOR DESIGN STOCK! | 0.0000 |  |  | 2.54mm Pitch Thru-Hole | ~
1 | J13 | Header, Male Pin | Conn_01x03_Pin | Pololu.com | #966 | Pololu.com | DO NOT BUY - SENIOR DESIGN STOCK! | 0.0000 |  |  | 2.54mm Pitch Thru-Hole | ~
2 | J18, J21 | Terminal Block,Horizontal, 2-Pos, 2.54mm Pitch | Screw_Terminal_01x02 | Phoenix Contact | 1725656 / MPT_0,5/_2-2,54 MPT052254 | Mouser.com | 651-1725656 (https://www.mouser.com/ProductDetail/Phoenix-Contact/1725656) | 1.5500 |  |  | 2.54mm Pitch Thru-Hole | ~
1 | J20 | Terminal Block, Horizontal, 4-Pos, 2.54mm Pitch | Screw_Terminal_01x04 | Phoenix Contact | 1725672 / MPT_0,5/_4-2,54 MPT054254 | Mouser.com | 651-1725672 (https://www.mouser.com/ProductDetail/Phoenix-Contact/1725672?qs=Ul7CXFMnlWXX93F9bOV2pQ%3D%3D) | 3.1300 |  |  | 2.54mm Pitch Thru-Hole | ~
1 | J12 | Header, Male Pin | Conn_01x02_Pin | Pololu.com | #966 | Pololu.com | DO NOT BUY - SENIOR DESIGN STOCK! | 0.0000 |  |  | 2.54mm Pitch Thru-Hole | ~
1 | L1 | Inductor, Power, SMD | 2.2uH/1.5A, 70 mOhms | Coilcraft | LPS4018-222MRC | Mouser.com | 994-LPS4018-222MRC (https://www.mouser.com/ProductDetail/Coilcraft/LPS4018-222MRC?qs=MW2gS7wPCVyKR5mBRcErLw%3D%3D) | 1.2200 |  |  | 1515 (4040 metric) | https://www.mouser.com/ProductDetail/Coilcraft/LPS4018-222MRC?qs=MW2gS7wPCVyKR5mBRcErLw%3D%3D
2 | L2,L3 | Inductor, Power, SMD | 4.7uH/500mA | Coilcraft | LPS3015-472MRC | Mouser.com | 994-LPS3015-472MRC (https://www.mouser.com/ProductDetail/Coilcraft/LPS3015-472MRC?qs=QQJxVsr8EGaLi%252BiqAu49Ng%3D%3D) | 1.2200 |  |  | 1212 (3030 metric) | https://www.mouser.com/ProductDetail/Coilcraft/LPS3015-472MRC?qs=QQJxVsr8EGaLi%252BiqAu49Ng%3D%3D
1 | L7 | Inductor, Power, SMD | 3.3uH/1.7A | Coilcraft | LPS4018-332MRC | Mouser.com | 994-LPS4018-332MRC (https://www.mouser.com/ProductDetail/Coilcraft/LPS4018-332MRC?qs=QQJxVsr8EGapQGERfchnNw%3D%3D) | 1.2200 |  |  | 1515 (4040 metric) | https://www.mouser.com/ProductDetail/Coilcraft/LPS4018-332MRC?qs=QQJxVsr8EGapQGERfchnNw%3D%3D
1 | Q1 | MOSFET, P-Channel, 12V/5.3A | Si2333DS | Vishay Siliconix | SI2333DS-T1-E3 | Mouser.com | 781-SI2333DS-T1-E3 (https://www.mouser.com/ProductDetail/Vishay-Semiconductors/SI2333DS-T1-E3?qs=jcx%252B0HVgj2YzacJfkqzT8Q%3D%3D) | 1.1200 |  |  | SOT-23 | http://www.vishay.com/docs/66709/si2319cd.pdf
2 | R1,R5 | Resistor, 0402, 1/16W, Thick Film | 510 Ohm | Bourns | CR0402-JW-511GLF | Mouser.com | 652-CR0402-JW-511GLF (https://www.mouser.com/ProductDetail/Bourns/CR0402-JW-511GLF?qs=2as47fUcDMQawhag9boWRw%3D%3D) | 0.0070 |  |  | 0402 | ~
1 | R3 | Resistor, 0402, 1/16W, Thick Film | 10K | Bourns | CR0402-JW-103GLF | Mouser.com | 652-CR0402-JW-103GLF (https://www.mouser.com/ProductDetail/Bourns/CR0402-JW-103GLF?qs=%2F8Tj2%2FBce9bNso9XMxOn0g%3D%3D) | 0.0070 |  |  | 0402 | ~
1 | R4 | Resistor, 0402, 1/16W, Thick Film | 100K | Bourns | CR0402-JW-104GLF | Mouser.com | 652-CR0402JW-104GLF (https://www.mouser.com/ProductDetail/Bourns/CR0402-JW-104GLF?qs=K5ddiUFZPT6F5Sk3R93%2Fiw%3D%3D) | 0.0060 |  |  | 0402 | ~
2 | R6,R7 | Resistor, 0402, 1/16W, Thick Film | 3.01K | Bourns | CR0402-FX-3011GLF | Mouser.com | 652-CR0402FX-3011GLF (https://www.mouser.com/ProductDetail/Bourns/CR0402-FX-3011GLF?qs=SFHnMgm9Isw%252BCNSYFvREcw%3D%3D) | 0.0750 |  |  | 0402 | ~
1 | R8 | Resistor, 0402, 1/16W, Thick Film | 383K | Bourns | CR0402-FX-3833GLF | Mouser.com | 652-CR0402FX3833GLF (https://www.mouser.com/ProductDetail/Bourns/CR0402-FX-3833GLF?qs=B0uw3wJAhvsfTIWyuvAZhA%3D%3D) | 0.0700 |  |  | 0402 | ~
1 | R9 - Value Cannot Be Found | Resistor, 0402, 1/16W, Thick Film | 348K | Bourns | CR0402-FX-3483GLF | Mouser.com | 652-CR0402-FX3483GLF (https://www.mouser.com/ProductDetail/Bourns/CR0402-FX-3483GLF?qs=B0uw3wJAhvsNTkxSB%252BqdgA%3D%3D) |  |  |  | 0402 | ~
1 | R10 - Value Cannot Be Found | Resistor, 0402, 1/16W, Thick Film | 240K | KOA Speer | RN73H1ETTP2403F25 |  | RN73H1ETTP2403F25 (https://www.mouser.com/ProductDetail/KOA-Speer/RN73H1ETTP2403F25?qs=n6Vcve68kq%252BEqstINy8QrA%3D%3D) |  |  |  | 0402 | ~
3 | R11,R12,R13 | Resistor, 0402, 1/16W, Thick Film, 1% | 110K | KOA Speer | RN73H1ETTP1103F25 | Mouser.com | RN73H1ETTP1103F25 (https://www.mouser.com/ProductDetail/KOA-Speer/RN73H1ETTP1103F25?qs=9tvNVxbbcEqjgkhwIP64fg%3D%3D) | 0.1420 |  |  | 0402 | ~
1 | R14 | Resistor, 0402, 1/16W, Thick Film | 8.25 Ohm | YAGEO | RC0402FR-078R25L | Mouser.com | 603-RC0402FR-078R25L (https://www.mouser.com/ProductDetail/YAGEO/RC0402FR-078R25L?qs=CGh%2FACcVdWhff%252BdAZuB7xw%3D%3D) | 0.0100 |  |  | 0402 | ~
1 | TH1 | Thermistor | 100K | EOCOS / TDK | B57871L0104F000 | Mouser.com | 871-B57871L0104F000 (https://www.mouser.com/ProductDetail/EPCOS-TDK/B57871L0104F000?qs=ZcfC38r4PosxBjLSqaz8qg%3D%3D) | 1.9500 |  |  | Through-Hole
1 | SW1 - 100mA Max! | Switch, Slide, SPDT, Non-Shorting, 100mA | SPDT | C&K | OS102011MS2QN1C | Mouser.com | 611-OS102011MS2QN1C (https://www.mouser.com/ProductDetail/CK/OS102011MS2QN1C?qs=FgXbtR4Gg7KP4hs8ueQ7Wg%3D%3D) | 0.7900 |  |  | Button_Switch_THT:SW_Slide_SPDT_Straight_CK_OS102011MS2Q | ~
1 | U1 | IC, Battery Management | LTC3556EUFD_PBF | Analog Devices | LTC3556EUFD#PBF | Mouser.com | 584-LTC3556EUFD#PBF (https://www.mouser.com/ProductDetail/Analog-Devices/LTC3556EUFDPBF?qs=hVkxg5c3xu9qL1q9qSA6yQ%3D%3D) | 15.6100 |  |  | QFN-28
1 | U2 | IC, Charge Pump DC-to-DC Voltage Converter | TC7660COA713 | Microchip | TC7660COA713 | Mouser.com | 579-TC7660COA713 (https://www.mouser.com/ProductDetail/Microchip-Technology/TC7660COA713?qs=JmwSjbzn2OK6fTH42vvj0Q%3D%3D) | 1.0600 |  |  | SOIC-08 | http://ww1.microchip.com/downloads/en/DeviceDoc/21469a.pdf
1 | PCB | LTC3556_v2.2 |  | JLCPCB.com

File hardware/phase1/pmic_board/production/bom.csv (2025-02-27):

Designator | Footprint | Quantity | Value | LCSC Part #
C1 | 1206 | 1 | 10uF
C10, C9 | 0402 | 2 | 10pF
C11, C12, C13, C14 | 0402 | 4 | 10uF
C15, C16, C18 | 0805 | 3 | 10uF
C2 | 1206 | 1 | 100nF
C3, C4 | 0402 | 2 | 100nF
C5, C6, C7 | 0402 | 3 | 1uF
C8 | 0402 | 1 | 130pF
D1, D2 | 0805 | 2 | LED
J1 | USB_Micro-B_Amphenol_10118194-0001LF_Horizontal | 1 | USB_B_Micro | C10418
J12 | JST_PH_S2B-PH-K_1x02_P2.00mm_Horizontal | 1 | Conn_01x02_Pin | C173752
J13 | PinHeader_1x03_P2.54mm_Vertical | 1 | Conn_01x03_Pin | C49257
J14 | PinHeader_1x01_P2.54mm_Vertical | 1 | Conn_01x01_Pin | C492400
J18, J21 | TerminalBlock_Phoenix_MPT-0,5-2-2.54_1x02_P2.54mm_Horizontal | 2 | Screw_Terminal_01x02 | C474920
J19 | PinHeader_1x02_P2.54mm_Vertical | 1 | Conn_01x02_Pin | C225477
J20 | TerminalBlock_Phoenix_MPT-0,5-4-2.54_1x04_P2.54mm_Horizontal | 1 | Screw_Terminal_01x04 | C474922
J22 | PinSocket_1x07_P2.54mm_Vertical | 1 | Conn_01x07 | C2832270
J23 | PinSocket_1x04_P2.54mm_Vertical | 1 | Conn_01x04 | C2685089
J24 | PinSocket_1x02_P2.54mm_Vertical | 1 | Conn_01x02 | C49661
L1 | L_Coilcraft_LPS4018 | 1 | 2.2uH/1.6A
L2, L3 | L_Coilcraft_LPS3010 | 2 | 4.7uH/500mA
L7 | L_Coilcraft_LPS4018 | 1 | 3.3uH/1.7A
Q1 | SOT-23 | 1 | SI2333DS
R1 | 0402 | 1 | 510
R10 | 0402 | 1 | 240K
R11, R12, R13 | 0402 | 3 | 110K
R14 | 0402 | 1 | 8.25 Ohm
R3 | 0402 | 1 | 10K
R4 | 0402 | 1 | 100K
R5 | 0402 | 1 | 510 Ohm
R6, R7 | 0402 | 2 | 3.01K
R8 | 0402 | 1 | 383K
R9 | 0603 | 1 | 350K
SW1 | SW_Slide_SPDT_Straight_CK_OS102011MS2Q | 1 | SW_SPDT | C480342
U1 | QFN-28-1EP_4x5mm_P0.5mm_EP2.65x3.65mm_ThermalVias | 1 | LTC3556EUFD_PBF | C685032
U2 | SOIC-8_3.9x4.9mm_P1.27mm | 1 | TC7660B | C512761

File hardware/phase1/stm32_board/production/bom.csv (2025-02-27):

Designator | Footprint | Quantity | Value | LCSC Part #
B1, B2 | SW_TS04-66-43-BK-260-SMT | 2 | TS02-66-60-BK-160-LCR-D
C19, C27 | CAPC1608X90 | 2 | 1uF
C20, C26, C28, C29, C30, C31, C32, C33, C34, C41, C49, C50, C51, C53, C57, C58, C61 | CAPC1608X90 | 17 | 100nF
C40 | CAPC1608X90 | 1 | [N/A]
C42 | CAPMP3216X166 | 1 | 4.7uF
C52, C54 | CAPC1608X90 | 2 | 4.7uF_X54_0603
C56, C59 | CAPMP3216X166 | 2 | 1uF
C60 | CAPC1608X90 | 1 | 1uF_X5R_0603
CN11, CN12 | PinSocket_2x36_P2.54mm_Vertical | 2 | Conn_02x36_Odd_Even
CN14 | MOLEX_47589-1001 | 1 | USB_B_Micro
CN5 | PinSocket_2x05_P2.54mm_Vertical | 1 | Conn_ARM_JTAG_SWD_10
D2 | DIOM4336X265N | 1 | SMLVT3V3
D6 | DIODE_ESDALC6V1-1U2 | 1 | ESDALC6V1-1U2
J1 | PHOENIX_1725656 | 1 | Screw_Terminal_01x02
L3 | FB0603 | 1 | BEAD
LD1, LD6, LD8 | LED-0603 | 3 | Green
LD2 | LED-0603 | 1 | Blue
LD3, LD7 | LED-0603 | 2 | Red
R28, R29 | RESC1607X60N | 2 | 1K
R30 | R0603 | 1 | 680
R31 | RESC1608X60N | 1 | 510
R36 | RESC1608X60N | 1 | 200K
R37, R38, R52, R54 | RESC1607X60N | 4 | 10K
R41, R43 | RESC1607X60N | 2 | 330
R42 | RESC1607X60N | 1 | 220K
R44 | RESC1607X60N | 1 | 100
R45 | RC0603N_YAG | 1 | 620
R48 | RESC1607X60N | 1 | 22K
R49, R51 | RESC1608X55 | 2 | 47K
SB124, SB132, SB135, SB142, SB143, SB172, SB197 | RESC1607X60N | 7 | Closed
T2 | SOT-23 | 1 | 9013
U11 | LQFP144-20x20mm_STM | 1 | STM32L496ZGTx
U12 | SOT95P280X145-5N | 1 | STMPS2151STR
U13 | SOT95P280X145-6N | 1 | USBLC6-2SC6
U6 | SON95P300X300X100-7N | 1 | LD39050PU33R
U8 | SOT23-5_STM | 1 | TSV631AILT
U9 | SOT65P210X110-5N | 1 | ESDALC6V1W5

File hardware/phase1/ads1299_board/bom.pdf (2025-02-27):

### bom

Designator | Footprint | Quantity | Value | LCSC Part #
AIN1 | 132134_AMP | 1 | AIN1
C1, C11, C17, C2, C23, C24, C3, C4, C5, C6, C7, C76, C77, C8, C97, C99 | CAPC1608X90N | 16 | 1uF
C10 | CAPC2012X95N | 1 | 10uF
C12, C13, C14, C15, C16, C18, C19, C94, C95 | CAPC1608X90N | 9 | 0.1uF
C20, C98 | CAPC1608X90N | 2 | 0.01uF
C72, C73, C75, C80, C81, C82, C83, C84, C85, C86, C87, C88, C89, C90, C91, C92, C93 | CAPC1608X90N | 17 | 4.7nF
C9 | CAPC3225X280N | 1 | 100uF
FB1 | BEADC1608X95N | 1 | FCM_1608KF-601T03
IC1 | QFP50P1200X1200X120-64N | 1 | ADS1299-4PAGR
J2, J9 | PHOENIX_1725656 | 2 | 1725656
J3 | SAMTEC_TSM-110-01-T-DV-P-TR | 1 | TSM-110-01-T-DV-P-TR
J5, JP25 | SAMTEC_TSW-103-07-T-D | 2 | TSW-103-07-T-D
J6 | SAMTEC_SSW-118-21-F-D | 1 | 36PIN_IDC
JP1, JP18, JP21, JP22, JP23, JP6, JP60, JP7, JP8 | SAMTEC_TSW-103-07-T-S | 9 | TSW-103-07-T-S
JP19, JP5 | SAMTEC_TSW-102-07-T-S | 2 | TSW-102-07-T-S
OSC1 | XTAL_FXO-HC735-8 | 1 | HC735-2.048MHZ
R10, R11, R12, R80, R81, R82, R83, R84, R85, R86, R87, R88, R89, R90, R91, R92, R93, R94, R95 | RESC1608X60N | 19 | 4.99K
R13, R14, R15, R71, R72, R73 | RESC1005X40 | 6 | 0
R23, R24 | 603 | 2 | 2.0M
R25, R3 | RESC1607X60N | 2 | 0
R6, R67, R7, R75 | RESC1607X60N | 4 | 10K
R8 | RESC1608X55N | 1 | 392K
TP2 | KEYSTONE_5001 | 1 | 5001
TP3 | KEYSTONE_5000 | 1 | 5000
TPAVDD1 | KEYSTONE_5000 | 1 | AVDD
TPAVSS1 | KEYSTONE_5000 | 1 | AVSS
TPDVDD1 | KEYSTONE_5000 | 1 | DVDD
U10 | SOP8P65_300X640X120L60X24N | 1 | 24AA256-I/ST
U11 | SOIC127P599X175-8N | 1 | OPA376AID
U4 | SOIC127P599X175-8N | 1 | OPA376

1

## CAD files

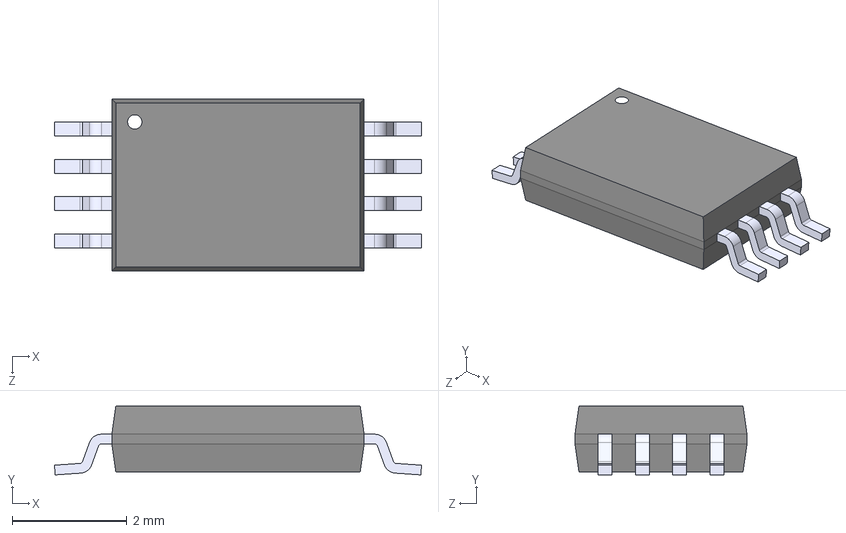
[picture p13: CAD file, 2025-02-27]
hardware/phase1/ads1299_board/ADS1299 Footprints/24AA256-I_ST 2/24AA256-I_ST.step
6.40 x 1.20 x 3.00 mm

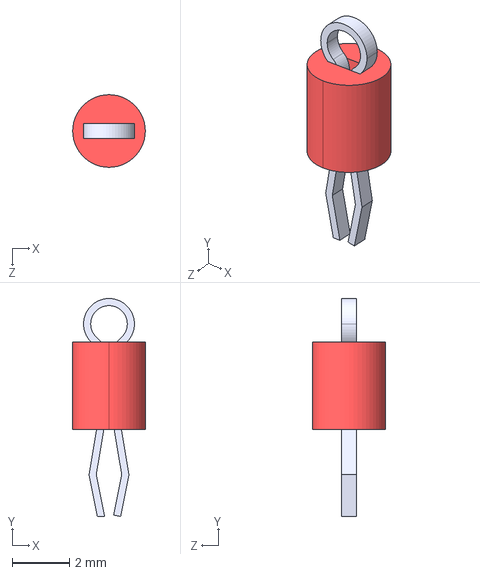
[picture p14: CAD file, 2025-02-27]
hardware/phase1/ads1299_board/ADS1299 Footprints/5000/5000.step
2.54 x 7.62 x 2.54 mm

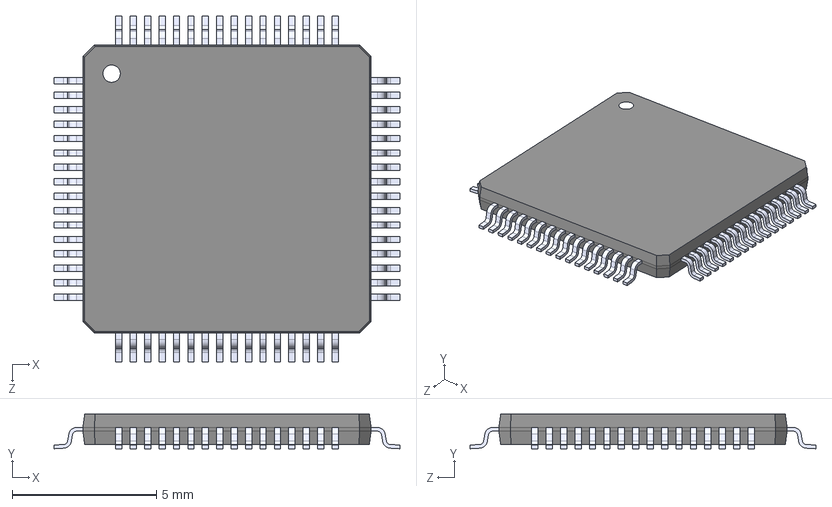
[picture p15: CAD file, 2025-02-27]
hardware/phase1/ads1299_board/ADS1299 Footprints/ADS1299CPAG/ADS1299CPAG.step
12.0 x 1.20 x 12.0 mm

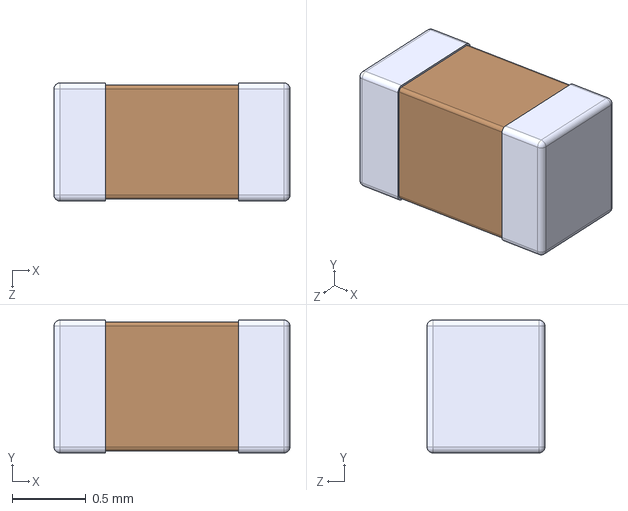
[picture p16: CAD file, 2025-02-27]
hardware/phase1/ads1299_board/ADS1299 Footprints/GRM188R61E105KA12D/GRM188R61E105KA12D.step
1.60 x 0.9 x 0.8 mm

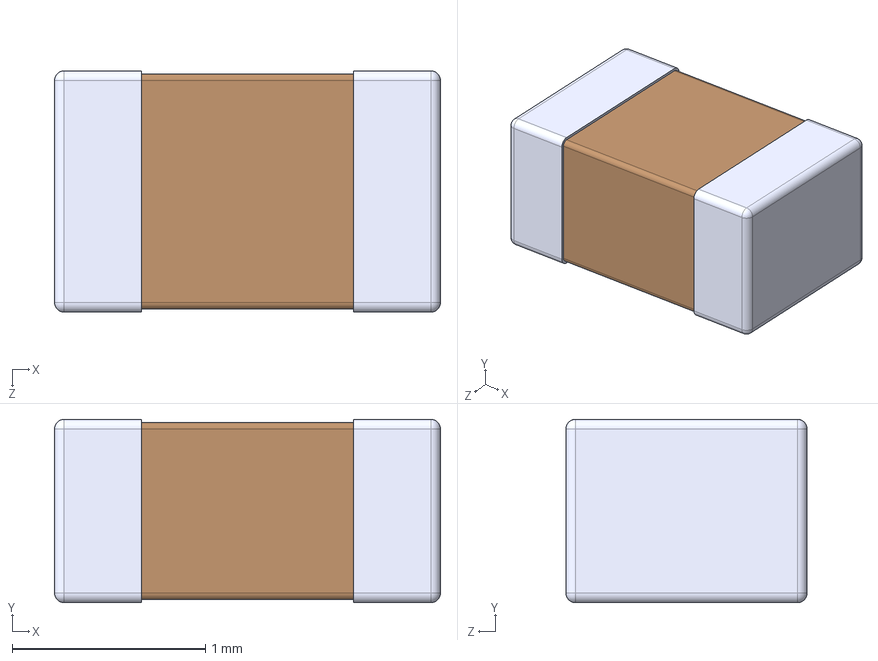
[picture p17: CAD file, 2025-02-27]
hardware/phase1/ads1299_board/ADS1299 Footprints/GRM219R61A106KE44D/GRM219R61A106KE44D.step
2.00 x 0.95 x 1.25 mm

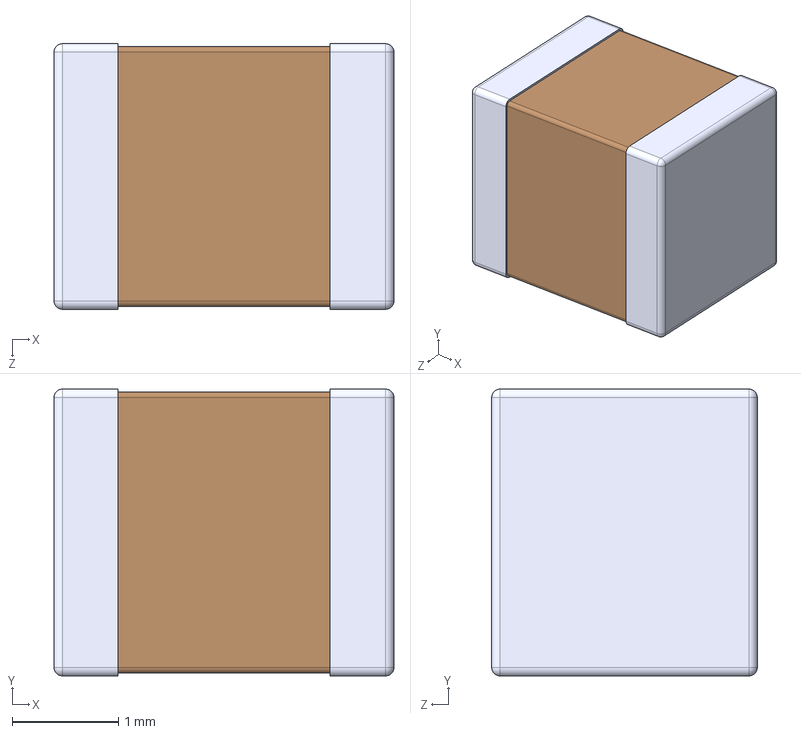
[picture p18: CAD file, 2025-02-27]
hardware/phase1/ads1299_board/ADS1299 Footprints/LMK325BJ107MM_T/LMK325BJ107MM-T.step
3.20 x 2.70 x 2.50 mm

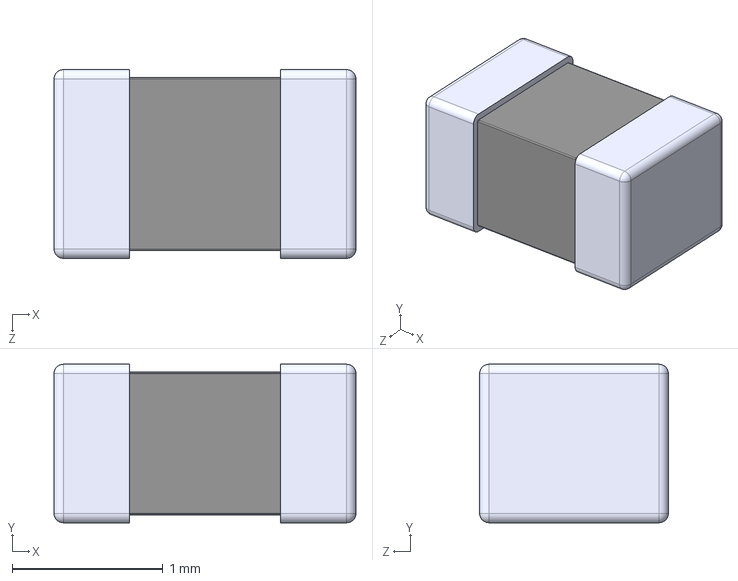
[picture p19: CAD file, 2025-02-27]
hardware/phase1/ads1299_board/ADS1299 Footprints/MLZ2012A3R3W/MLZ2012A3R3W.step
2.00 x 1.05 x 1.25 mm

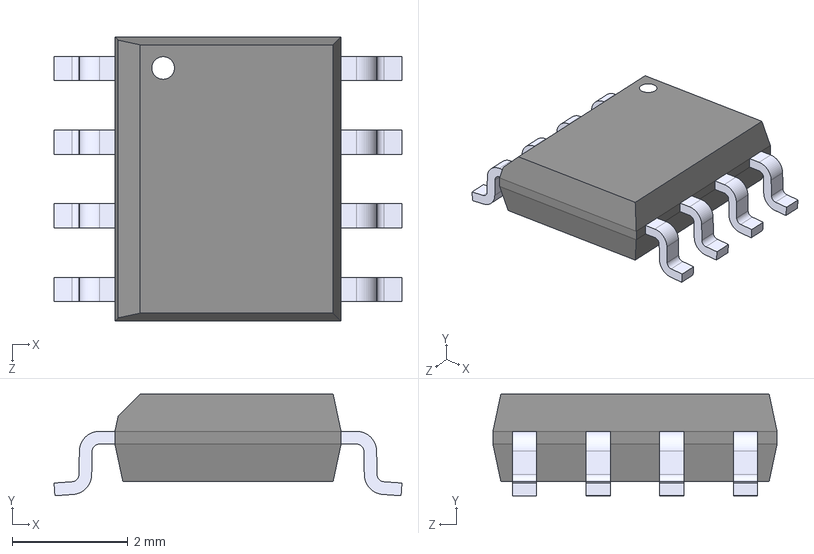
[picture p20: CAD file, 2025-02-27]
hardware/phase1/ads1299_board/ADS1299 Footprints/OPA376AID/OPA376AID.step
6.00 x 1.75 x 4.90 mm

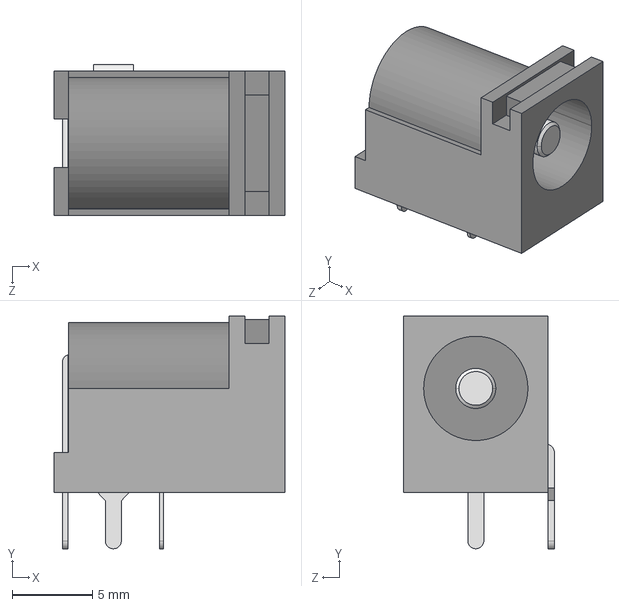
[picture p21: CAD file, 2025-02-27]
hardware/phase1/ads1299_board/ADS1299 Footprints/PJ_102B/PJ-102B.step
14.4 x 14.5 x 9.40 mm

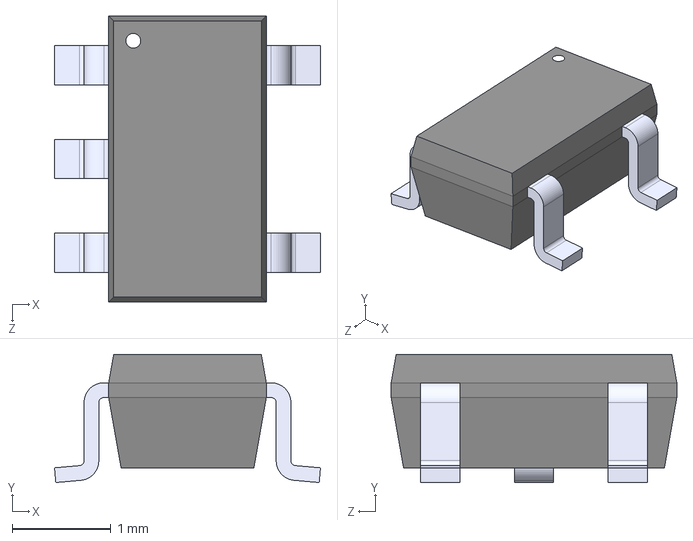
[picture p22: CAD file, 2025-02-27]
hardware/phase1/ads1299_board/ADS1299 Footprints/placeholder_TS5205CX525_RFG/TS5205CX525_RFG.step
2.70 x 1.30 x 2.90 mm

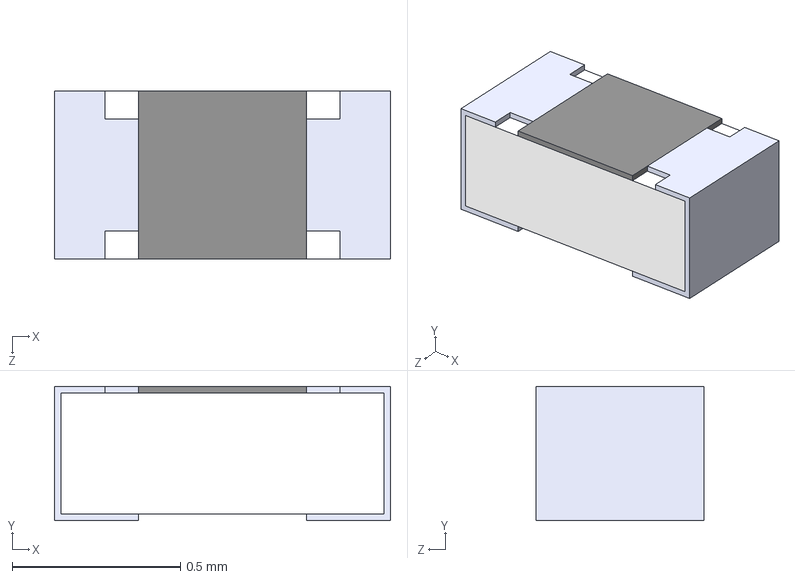
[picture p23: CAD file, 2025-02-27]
hardware/phase1/ads1299_board/ADS1299 Footprints/RC0402JR-070RL/RC0402JR-070RL.step
1 x 0.4 x 0.5 mm

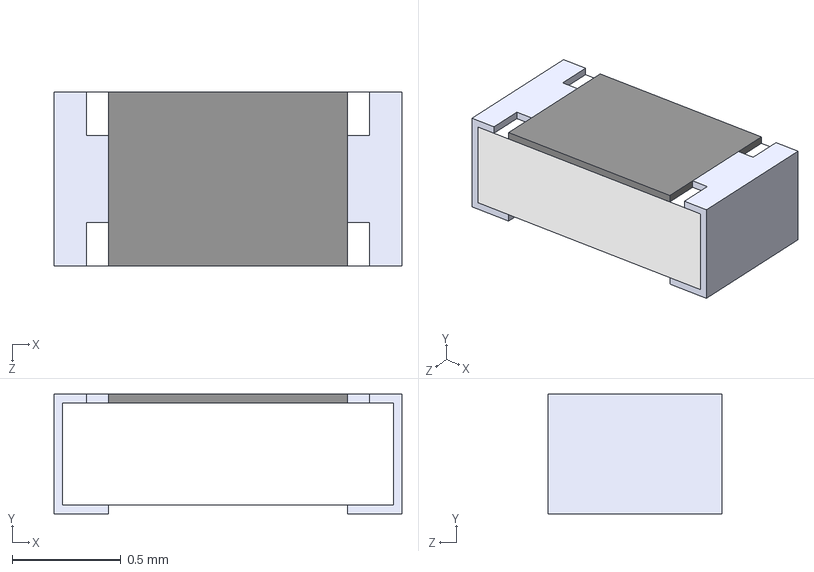
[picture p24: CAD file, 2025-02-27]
hardware/phase1/ads1299_board/ADS1299 Footprints/RC0603FR-0710KL/RC0603FR-0710KL.step
1.60 x 0.55 x 0.8 mm

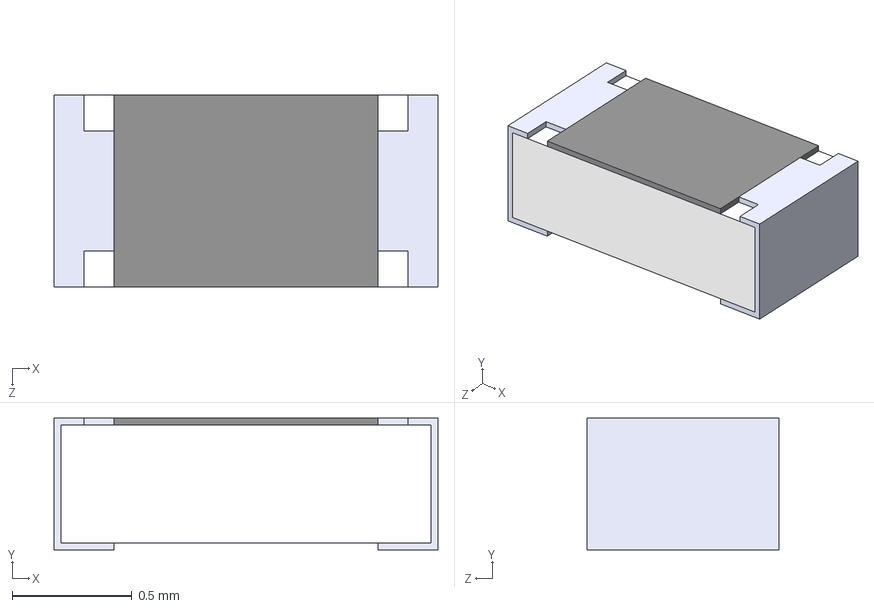
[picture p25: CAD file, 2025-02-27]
hardware/phase1/ads1299_board/ADS1299 Footprints/RC0603FR-07392KL/RC0603FR-07392KL.step
1.60 x 0.55 x 0.8 mm

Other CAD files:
hardware/phase1/ads1299_board/ADS1299 Footprints/5001/5001.step
hardware/phase1/ads1299_board/ADS1299 Footprints/132134/132134/3D/132134.stp
hardware/phase1/ads1299_board/ADS1299 Footprints/132134/132134/Allegro/132134.psm
hardware/phase1/ads1299_board/ADS1299 Footprints/132134/132134/DEHDL/132134/chips/chips.prt
hardware/phase1/ads1299_board/ADS1299 Footprints/RC0603FR-074K99L/RC0603FR-074K99L.step
hardware/phase1/ads1299_board/ADS1299 Footprints/REG104GA_5/REG104GA-5.step
hardware/phase1/ads1299_board/ADS1299 Footprints/SSW-105-22-F-D-VS-K/SSW-105-22-F-D-VS-K.step
hardware/phase1/ads1299_board/ADS1299 Footprints/SSW-118-21-F-D/SSW-118-21-F-D.step
hardware/phase1/ads1299_board/ADS1299 Footprints/TPS60403DBVT/TPS60403DBVT.step
hardware/phase1/ads1299_board/ADS1299 Footprints/TPS70302PWP/TPS70302PWP.step
hardware/phase1/ads1299_board/ADS1299 Footprints/TPS72325DBVT/TPS72325DBVT.step
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

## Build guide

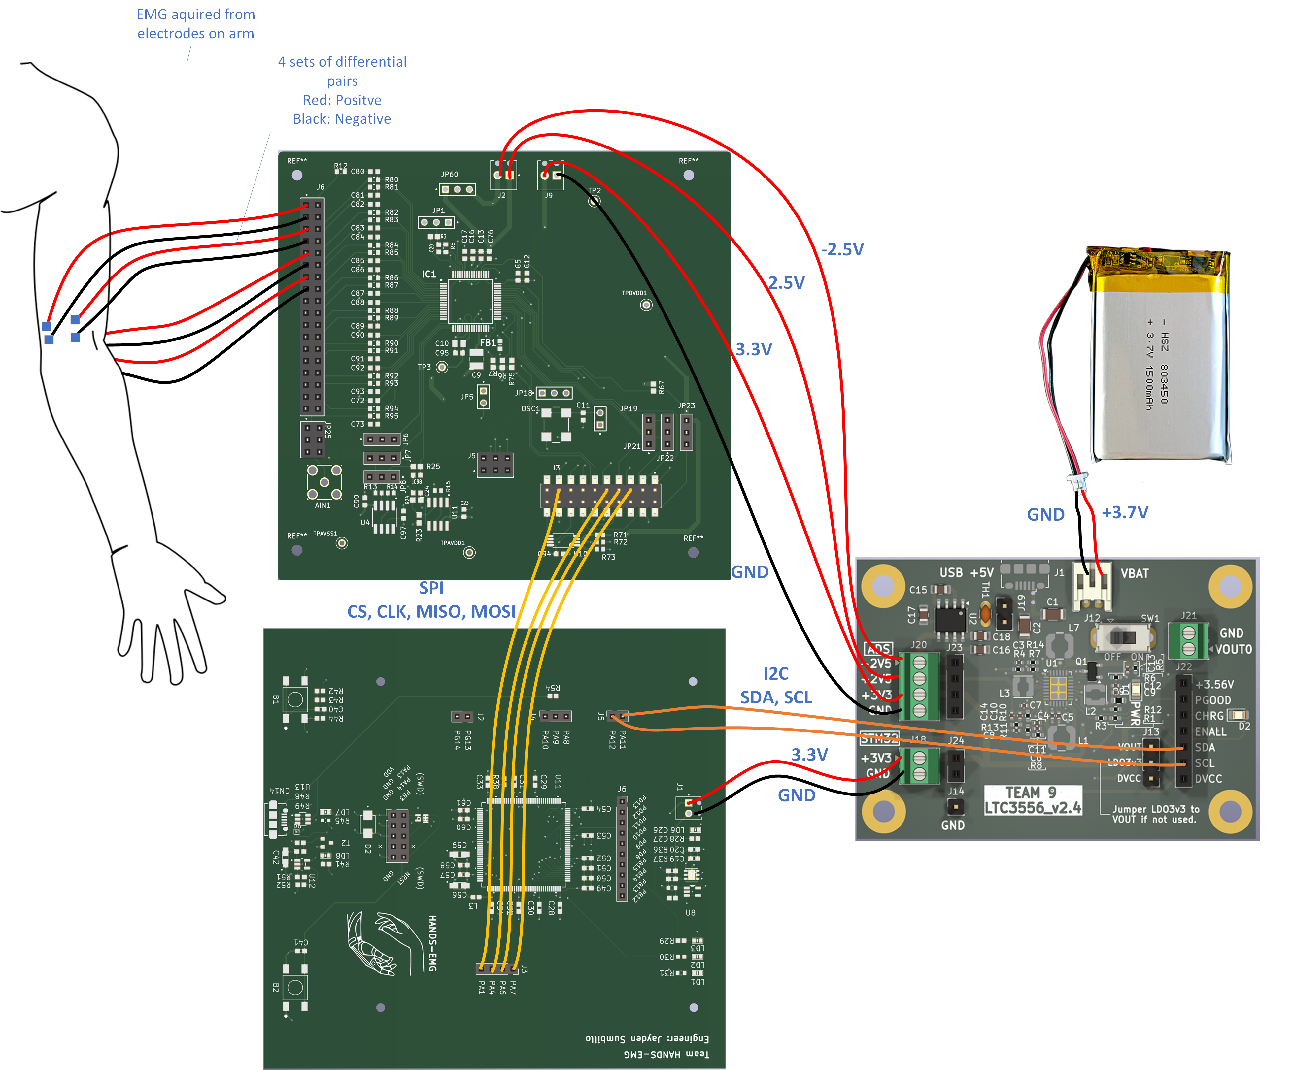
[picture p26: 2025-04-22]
documentation/system description and design/integration-rediness-report-pics/Wiring Diagram.png

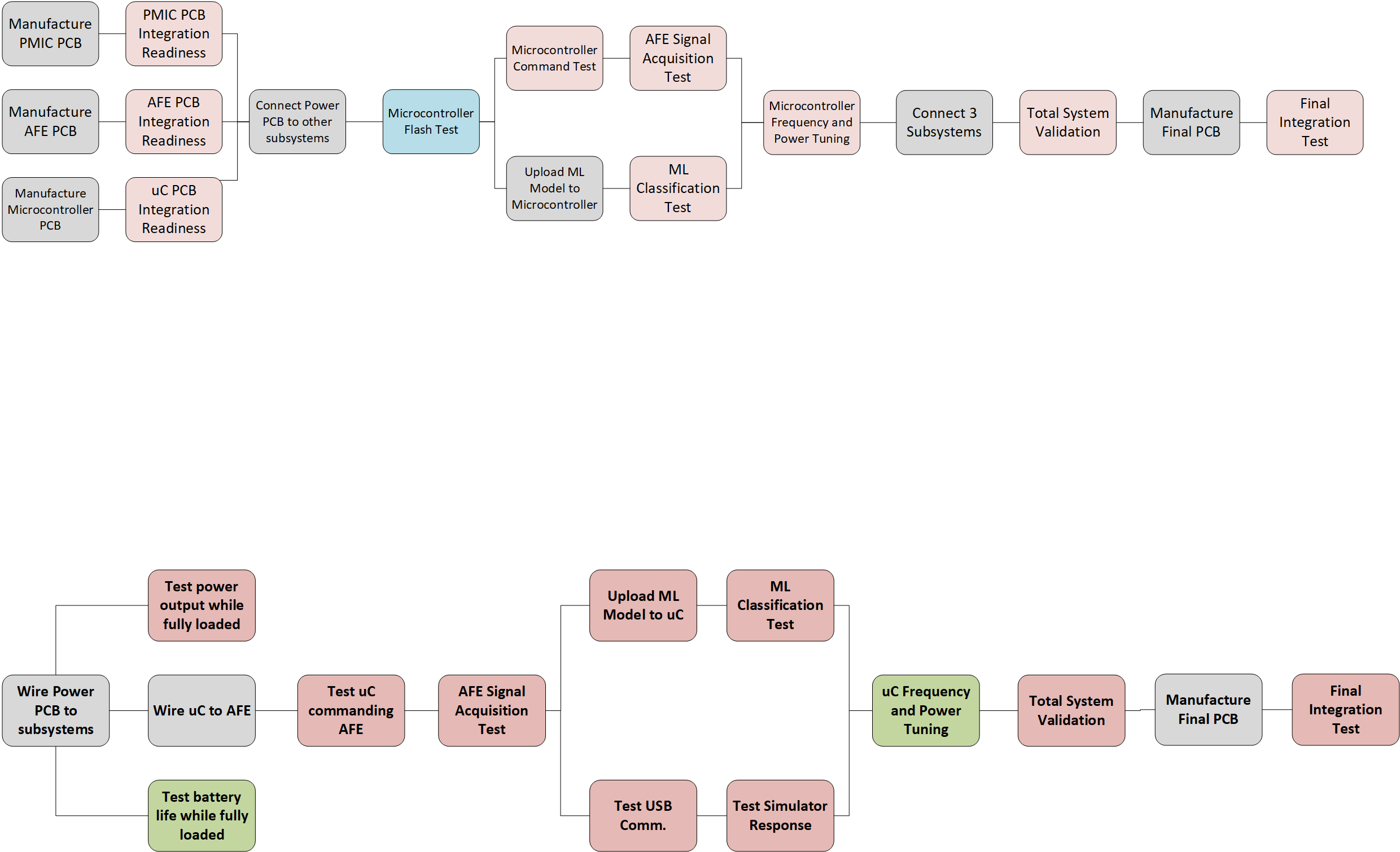
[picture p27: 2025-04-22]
documentation/system description and design/integration-rediness-report-pics/Integration-Steps-v2.png

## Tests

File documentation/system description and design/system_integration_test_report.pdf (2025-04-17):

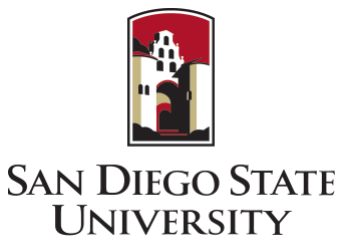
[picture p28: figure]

College of Engineering, Department of Electrical and Computer Engineering EE/COMPE 492 Senior Design

## System Integration Test Report

### Team HANDS-EMG

ECE Team 9 – Hand Activity Neural Detection using sEMG EE Members:
Kelly Hubbard, Jayden Sumbillo, Kirk Young CE Members:
Noah Marosok, Blake Pearson

Sponsor:
SDSU Department of Electrical and Computer Engineering SDSU Smart Biomedical Systems Lab

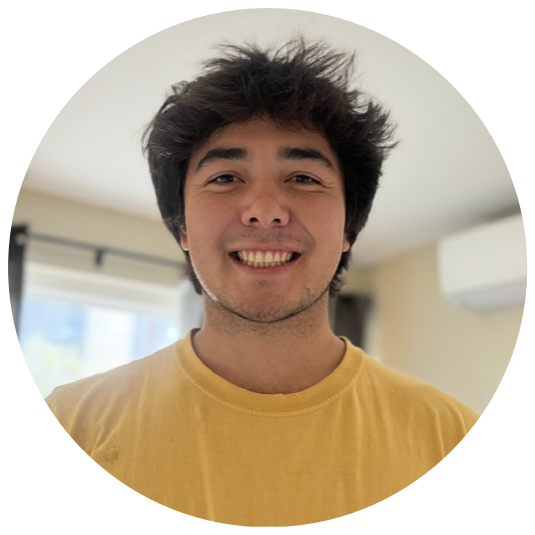
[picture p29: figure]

Kelly Hubbard
Electrical Engineering

Jayden Sumbillo
Electrical Engineering

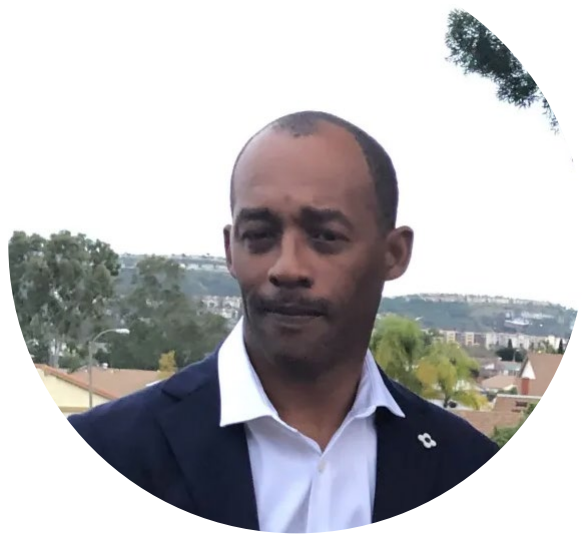
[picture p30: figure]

Kirk Young
Electrical Engineering

Noah Marosok
Computer Engineering

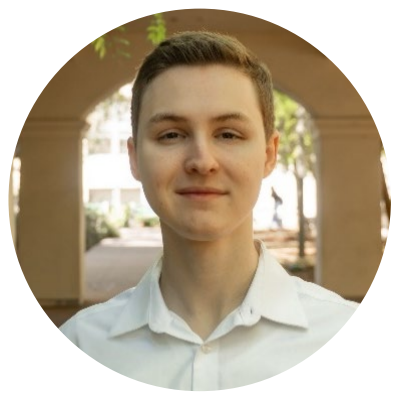
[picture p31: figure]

Blake Pearson
Computer Engineering

Dr. Hakan Töreyin
PI & Advisor

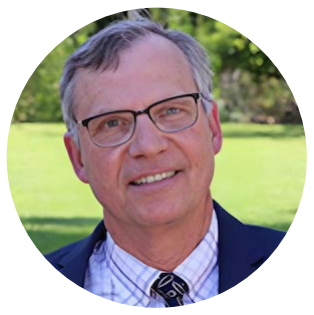
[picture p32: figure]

Prof. Barry Dorr
Advisor

Executive Summary | 4
Updated System Description | 5
Triage Tests | 8
Microcontroller SWD Flashing | 8
Power Supply Rail | 9
Machine Learning Model | 9
User Interface | 9
Test Plan | 10
Description of Tests and Results | 12
User Interface | 12
Machine Learning Classification | 15
Power System Wiring | 17
AFE Signal Output | 19
Root Causes of Failures | 21
Failure in AFE Signal Acquisition | 21
Failure in Power System Wiring | 21
Failure in Machine Learning Model | 21
Design, Specifications, or Project Changes | 23
Updated Schedule | 24
Table of Contents
FIGURE 1: MACHINE LEARNING PROCESS | 5
FIGURE 2: PHYSICAL SKETCH OF DEVICE | 6
FIGURE 3: USE CASE DIAGRAM | 7
FIGURE 4: SYSTEM BLOCK DIAGRAM | 7
FIGURE 5: MICROCONTROLLER SWD FLASH TRIAGE SETUP | 8
FIGURE 6: SYSTEM TEST PLAN | 10
FIGURE 7: FINAL SYSTEM TEST PROCEDURE | 11
FIGURE 8: UI BLOCK DIAGRAM FOCUSED | 12
FIGURE 9: SEMG GRAPHS ON UI | 13
FIGURE 10: ML CLASSIFICATION OUTPUT ON UI | 14
FIGURE 11: TRAINING UI DESIGN | 14
FIGURE 12: MACHINE LEARNING BLOCK DIAGRAM FOCUSED | 15

FIGURE 13: TEAM MEMBERS SEMG DATA | 16
FIGURE 14: SEMG DUAL PLOT BEST PERFORMING | 16
FIGURE 15: POWER SYSTEM WIRING BLOCK DIAGRAM FOCUSED | 17
FIGURE 16: PMIC OUTPUT WHEN LOADED | 18
FIGURE 17: PMIC 2.5V LINES WHEN LOADED | 18
FIGURE 18: PMIC 3.3V LINE WHEN UNLOADED | 19
FIGURE 19: AFE BLOCK DIAGRAM FOCUSED | 19
FIGURE 20: AFE UNEXPECTED CURRENT DRAW | 20
FIGURE 21: UPDATED TEAM SCHEDULE | 24
Table of Figures
TABLE 1: DESIGN, SPECIFICATION, OR PROJECT CHANGES TABLE | 23
Table of Tables

## Executive Summary

The HANDS-EMG device is a wearable, battery-powered surface electromyography (sEMG) system designed to classify hand movements in real time using embedded machine learning. This report outlines the results of the system integration testing, highlights critical outcomes, and documents key changes made to hardware, firmware, and system design in response to test findings.
Integration testing was conducted to verify subsystem interoperability and evaluate overall system performance under realistic operating conditions. Testing covered signal acquisition via the ADS1299 analog front-end (AFE), embedded classification via the STM32 microcontroller, and power delivery through the onboard power management integrated circuit (PMIC).
The AFE signal acquisition test failed. Investigation revealed oversight in the PCB layout routing that led to excessive current on sensitive input pins, ultimately damaging the ADS1299 chip. This resulted in a revision to the final PCB layout, specifically within the AFE section.
The power system tests passed, but analysis revealed the PMIC was operating near our microcontroller’s absolute maximum ratings. As a result, a more suitable PMIC, the LTC3586, with similar pinout and functionality was substituted to ensure stable operation with greater margin. This change required minimal redesign but improved long-term reliability.
Initial firmware used a machine learning model trained on the public NinaPro dataset. However, integration testing showed significant accuracy degradation across different users. In response, the team transitioned to a personalized model trained using STMicroelectronics' NanoEdge AI Studio. This pivot required major firmware updates to support a new activation-based classification scheme. Furthermore, it necessitated user-specific data collection to train the embedded inference engine.
All changes including PCB re-layout, IC replacement, firmware restructuring, and the shift to onboard ML training—are reflected in the updated system description included in this report.

## Updated System Description

The HANDS-EMG device is a battery-powered surface electromyography sensor system designed to classify hand movements using machine learning, by interpreting the muscle activity signals captured from the user’s forearm. By utilizing sEMG technology, it provides a non-invasive method to monitor and analyze the muscle signals in real time. This functionality is useful for applications in prosthetics and rehabilitation where accurate and efficient movement recognition is essential. The device is portable, and battery powered, making it a practical and reliable tool for improving accessibility.
The machine learning model is trained and implemented through the process seen below in Figure 1. Training begins with raw EMG data from our device, which is processed by the Matlab training controller to attach the classification to the data. The data and its associated classification are input into STMicroelectronics NanoEdge AI to build and evaluate the model. Once trained, the model is exported to a knowledge header file for deployment on the STM32 microcontroller. The microcontroller receives raw data from the analog front-end, processes it to determine if a sEMG activation event occurred, and uses the pretrained inference engine to classify movements and output the results in real time.

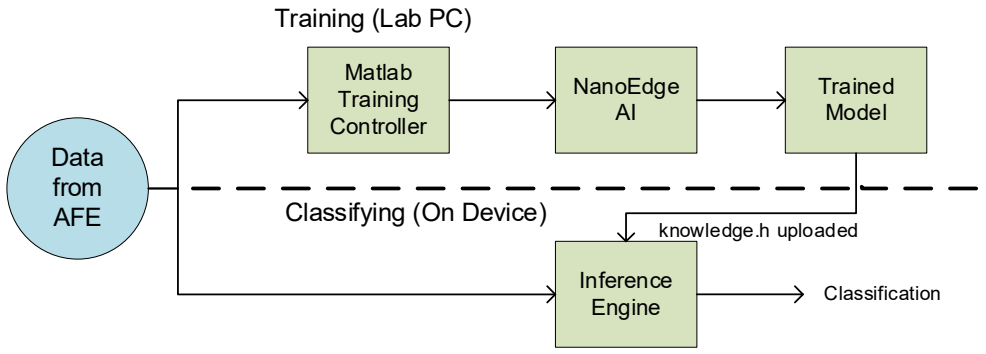
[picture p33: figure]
Data from AFE; Matlab Training Controller; NanoEdge AI; Trained Model; Inference Engine; Training (Lab PC); Classifying (On Device); knowledge.h uploaded; Classification

Figure 1: Machine Learning Process Figure 1 demonstrates the machine learning process that is conducted to attain a working model on our microcontroller. The process starts at the left and works right. Notice that the training portion only occurs if the Matlab training controller is activated.
The device utilizes four channels of wet electrodes placed on the user’s forearm to capture the sEMG signals. The device is designed to be arm mounted and will not exceed the dimensions of 3.25 x 3.75 x 0.75in and will not exceed a mass of 40g. A physical sketch including dimensions can be seen below in Figure 2.

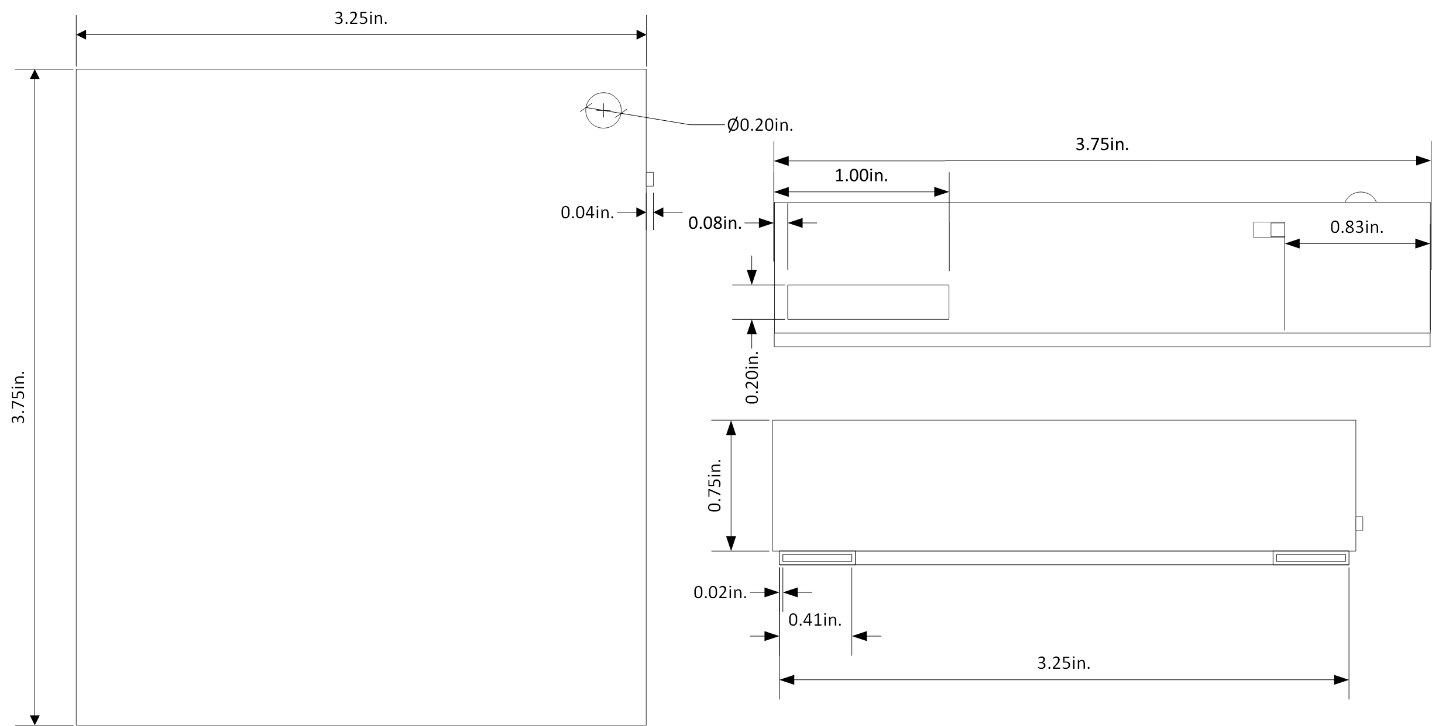
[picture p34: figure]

Figure 2: Physical Sketch of Device Figure 2 shows the physical sketch of our device. This sketch is our device’s enclosure that it is contained within.
Our system is comprised of three main subsystems. These subsystems are the ADS1299 analog front-end module (AFE), STM32 microcontroller, and the power management integrated circuit (PMIC). The AFE is a critical component, procured specifically for its ability to handle the complexity of sEMG signal acquisition. It amplifies and digitizes the weak bioelectric signals (typically in the range of 10uV to 10mV). The STM32 microcontroller serves as the central processor, performing feature extraction and classification using the machine learning model. The PMIC ensures stable power delivery to all components, enabling the device to operate with a 3.7V lithium-ion battery for ~38 hours. These details and the interactions between the subsystems are illustrated below in the block diagram in Figure 4.
The analog signals captured by the four channels of wet electrodes are processed through our procured analog front-end module which operates at a sample rate of 2KHz. Within the microcontroller, a pre-trained machine learning model classifies these hand movements with an accuracy of no less than 90%.
To begin using the device, the user will prepare their forearm, ensuring the area is clean and dry. Eight electrodes are placed radially around the proximal forearm, spaced approximately 2 cm apart, and positioned 2-3 cm distal from the elbow crease. A reference electrode is placed on the elbow. Once the electrodes are in place, the user runs the simulator software on a PC, connects the device to the PC via USB Micro B, and powers on the device. As the user moves their hand, the device processes the sEMG signals and transmits the classified movements to the PC, where a visual simulation displays the corresponding hand movements in real time. These steps can be seen below in Figure 3.

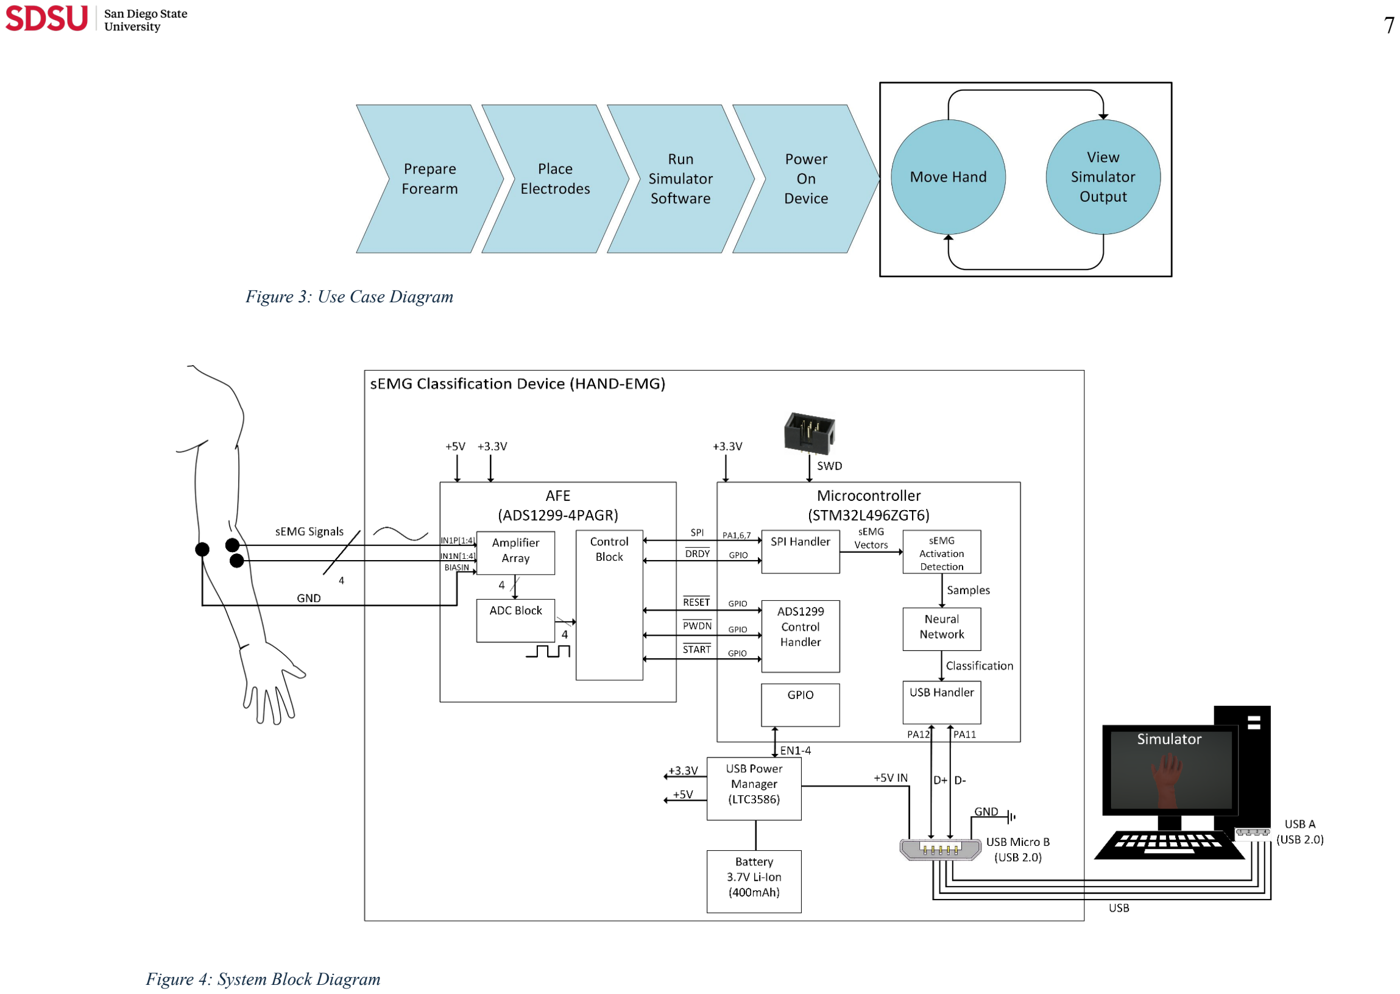
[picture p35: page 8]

Figure 3: Use Case Diagram

Figure 4: System Block Diagram

## Triage Tests

Before formal integration testing began, a series of triage tests were conducted to quickly evaluate whether each subsystem was in a usable state. These preliminary tests focused on identifying any major failures, configuration errors, or firmware issues that would prevent meaningful test execution.

### Microcontroller SWD Flashing

As shown in Figure 5, the microcontroller is connected to the ST-Link Utility external debugger through the following pins: PA13 (SWDIO), PA14 (SWCLK), PB3 (SWO), and NRST (NRST). Prior to testing, the first task was to wipe the STM32’s on-chip flash memory to ensure any previous firmware is removed. This was accomplished simply by utilizing the debugger’s built-in “Erase” function. The device’s memory was verified to be successfully cleared by assessing the console output through the STM32CubeIDE program.
To test the MCU’s basic functionality using the external debugger, a simple “LED blink” code was uploaded to the board, with the purpose of flashing the on-board status indicator LED at various rates. Once verified, the next test involved the actual SWD debug interface. The interface was tested and verified by stepping through the firmware.

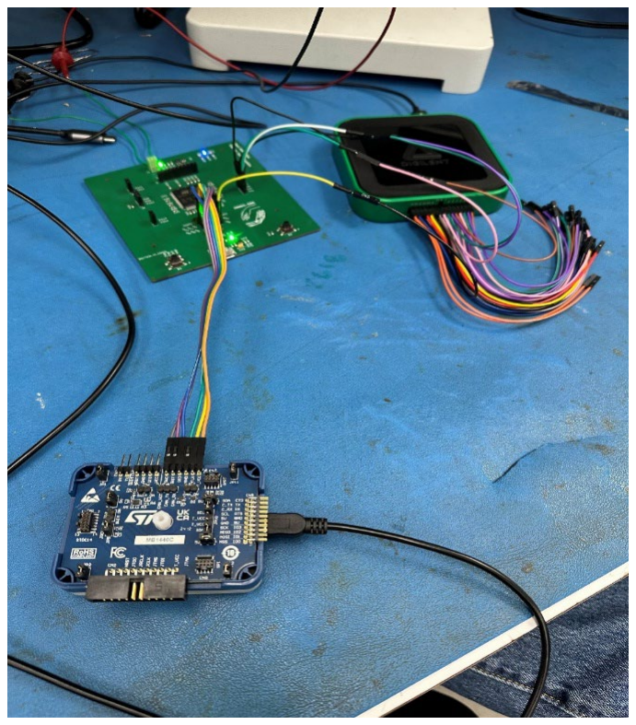
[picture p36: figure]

Figure 5: Microcontroller SWD Flash Triage Setup Figure 5 shows the test setup for the simple triage test of flashing the microcontroller with the firmware via SWD.

### Power Supply Rail

The power system triage tests were performed independently of any other subsystems to ensure that the power rails delivered appropriate voltages before connecting sensitive components. This safeguarded against component damage and unnecessary complications during full integration testing.
To perform this triage, the team applied power to the power management board using a 3.7V LiPo battery. With the battery applied, the team measured and confirmed that each voltage rail was reading at the correct level (3.3V, 2.5V, -2.5V). Power subsystem passed triage. All voltage rails were stable and within specification when unloaded. Battery operation and charging were also confirmed to function correctly.

### Machine Learning Model

Triage testing for the machine learning classification system was performed to ensure that the microcontroller could successfully receive and run a machine learning model, and that the firmware was able to load the inference engine without crashing. This was critical before testing our model, as we knew the microcontroller’s capabilities.
To perform this triage, the team uploaded a pre-validated test/demo model to the STM32 using the SWD interface. The device was run and checked for a successful boot, ensuring no resets or hangs occurred. The model was called for initial verification, and the system was monitored for stability and correct demo output. The ML subsystem passed the triage. The test model was successfully uploaded and initialized. The device remained operational, confirming readiness for live classification with our custom model.

### User Interface

The purpose of this triage test was to confirm that the simulator UI could receive and plotting serial data, and that the classification display system functioned as intended. This helped ensure that later tests using live EMG input and ML outputs would be accurately visualized.
To perform this triage, a simple python script to send simulated data over the COM port in the expected format was created. When running the simulator UI and the python test script the team observed the graphing output of the UI and confirmed the waveforms were plotted correctly. Thus, the UI passed its triage testing as the graphs updated in real time and classification labels were displayed as expected when simulated data was sent.

## Test Plan

The diagram below in Figure 6 shows the testing plan that is being followed. The plan begins with simple functional tests and then leads to more complex tests. The test plan concludes with the final system test and the procedures for the final system test can be seen in Figure 7 below.

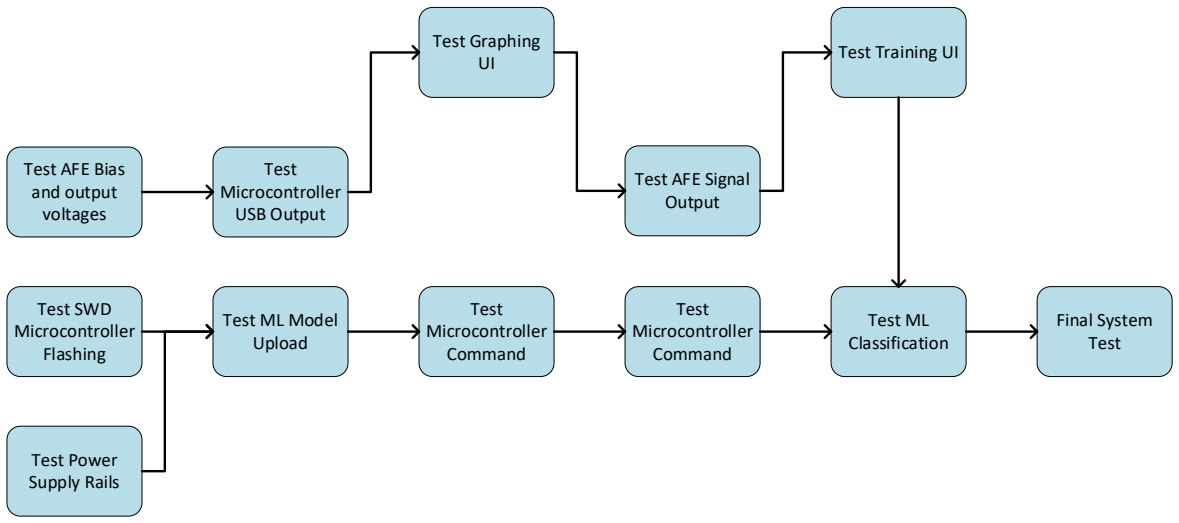
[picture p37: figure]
Test AFE Bias and output voltages; Test SWD Microcontroller Flashing; Test Power Supply Rails; Test Microcontroller USB Output; Test ML Model Upload; Test AFE Signal Output; Test Microcontroller Command; Test Graphing; Test Training UI; Test ML Classification; Final System Test

Figure 6: System Test Plan
Figure 6 shows the testing plan that is followed for our integration of our device. It begins with simple functional tests and leads to more complex tests.

Gesture Recognition Test; Prepare forearm and place electrodes; Fist Clench Test; Clench hand into fist and relax 5x times.; Wrist Flexion Test; Perform flexion and relax 5x times.; Wrist Extension Test; Perform extension and relax 5x times.; Turn device and simulator on; Test Setup; Success Criteria: Simulator correctly displays 80% of gestures accurately classified

Figure 7: Final System Test Procedure
Figure 7 shows the testing procedure to conduct the final system test that serves as the definition of complete for our device.

## Description of Tests and Results

The following is a description of all the major tests that were performed during system integration.

### User Interface

The simulator and user interface (UI) portion of the system was tested to verify its ability to correctly display sEMG data received over a serial COM connection (via Micro-B USB) and properly associate user movements with the output of the embedded machine learning model. This test also proves that the training UI can properly set up the data to be processed by the ML trainer. This subsystem corresponds to the user-facing/simulator portion of the block diagram, see Figure 8.


Figure 8: UI Block Diagram Focused Figure 8 shows the block diagram zoomed into the UI portion of the device.

User Interface Test Procedure
1. Connect the HANDS-EMG device to a PC using a USB Micro B cable.
2. Launch the simulator and verify that the main user interface appears.
3. Enter Normal Mode and check that real-time EMG plots are generated from the COM port data stream.
4. Move the hand through different positions and verify that classification labels are displayed and updated at least once per second.

5. Switch to Training Mode and follow the movement prompts. Ensure that the training UI collects and saves incoming data with the correct movement label.
6. Review the output files and confirm the correct format and label tagging.
User Interface Test Results
All UI tests passed. The EMG signals were plotted in real-time with a smooth update rate. Movement classification labels updated reliably and reflected microcontroller output. The training interface is properly labeled data buffers per movement. Raw training files were verified manually. Since these are large CSV files, they are not visualized in this report. These results can be seen below in Figure 9, Figure 10, and Figure 11.
User Interface Test Figures


Figure 9: sEMG Graphs on UI Figure 9 demonstrates that test 3 was successfully completed. It shows the graphs of the EMG waveforms collected by the AFE eval kit, transmitted to the custom uC board, and then transmitted to the PC via USB.


Figure 10: ML Classification output on UI Figure 10 shows the possible outputs for the ML live classification UI. Its important to note that these were gathered from real ML classifications from the new working machine learning model after retraining.


Figure 11: Training UI Design Figure 11 shows the training UI design. When the start button is pressed on the training UI, it begins to collect data from the microcontroller. The user will perform the movement that is displayed and the data that is acquired during the movement is recorded to a CSV file related to the movement (e.g. wrist_extension.csv).

### Machine Learning Classification

This test evaluates the performance of the Ninapro trained ML model with custom validation data as received by the AFE via the SPI connection. This is to verify that the Microcontroller will be able to accurately predict the gesture of a given waveform when deployed. The subsystem corresponds to the machine learning and feature extraction portion which can be seen below circled in red in Figure 12.


Figure 12: Machine Learning Block Diagram Focused Figure 12 shows the block diagram zoomed into the ML portion of the device.
ML Classification Test Procedure
1. Analyze the final model for classification accuracy of data transmitted from AFE.
2. Record 3 repetitions of the five gestures selected using the AFE and transmit the waveforms to the STM32.
3. Package and clean the data in accordance with the Ninapro training data.
4. Run an inference test on all windows of data to verify that the accuracy is within an acceptable margin from training data.
ML Classification Test Results
After successfully porting the AFE, Figure 13 shows the test as it was performed. When this data was packaged utilizing the custom window function that has been used throughout this project and run through a testing of the ML model on the PC, the model produced a 54.01% accuracy. For comparison, subject 9 which had a 94.08% accuracy is plotted next to Noah’s sEMG data below in Figure 14.


ML Classification Test Figures

Figure 13: Team Members sEMG Data

Figure 13 shows the entire recording of Noah’s sEMG data prior to windowing and feature extraction.

Figure 14: sEMG Dual Plot Best Performing

Figure 14 shows a dual plot of each gesture for the best performing Ninapro subject and Noah’s sEMG data. Subject 9 from the Ninapro database provided a 94.08% accuracy utilizing leave-one-out-cross-validation while Noah produced a 54.1% accuracy after testing. Note the visible periodic interference in the purple waveform of Noah’s sEMG data that was identified as 60Hz noise.

### Power System Wiring

This test ensures that the power management system reliably provides the required voltage rails to the microcontroller and analog front end. This subsystem is represented in the power system portion of the block diagram, seen below in Figure 15.


Figure 15: Power System Wiring Block Diagram Focused Figure 15 shows the block diagram zoomed in on the section that is being tested in this test.
Power System Wiring Test Procedure
1. Power the board with no load connected and verify output rails using a multimeter.
2. Connect the AFE board and verify that it receives the proper voltage and the PMIC remains operational.
3. Connect the STM32 board and verify that it powers on successfully.
4. Measure all major voltage rails (3.3V, +2.5V, -2.5V) with all devices connected.
Power System Wiring Test Results
Tests 1 and 3 passed. The STM32 microcontroller operated correctly when powered by the PMIC. Test 2 failed, the AFE failed to power on due to a PCB layout issue. This issue led to a change in the AFE routing and is discussed further in the failure section. Test 4 also failed, the PMIC 3.3V rail spiked to 3.6V when connected to the STM32. While technically this is allowable due to the absolute maximum rating of the STM32 being 3.6V, the team decided to change the PMIC to avoid future issues. This change is reflected in the system description. These results can be seen below in Figure 16, Figure 17, and Figure 18

Power System Wiring Test Figures


Figure 16: PMIC Output when Loaded Figure 16 shows the PMIC outputting 3.6V when it is under load from the microcontroller. Demonstrating the 3.6V spike that caused concern on the team leading to a system description change.


Figure 17: PMIC 2.5V lines when Loaded Figure 17 shows the 2.5V rails working correctly when loaded.


Figure 18: PMIC 3.3V Line when Unloaded Figure 18 shows 3.3V rail working correctly when the device has no load.

### AFE Signal Output

This test evaluates the operation of the ADS1299 analog front end by verifying current draw, reference voltages, SPI communication, and sEMG signal output. This functionality is shown in the AFE section of the block diagram, seen below in Figure 19.


Figure 19: AFE Block Diagram Focused Figure 19 shows the block diagram zoomed in on the subsystem that is being tested in this section.

AFE Signal Output Test Procedure
1. Power the AFE using external power supplies and measure current on the analog and digital lines.
2. Probe the AFE’s reference and bias test points using a multimeter.
3. Connect the AFE to the STM32 via SPI and attempt to initialize communication.
4. If successful, stream AFE data to the simulator and observe real-time plots.
AFE Signal Output Test Results
All tests failed. The digital power consumption was ~107mA, far above the 0.1mA absolute maximum. Bias voltage was 0.9V (expected 4.5V). Reference voltage was correct at -2.5V. Communication failed and the AFE was unresponsive and did not transmit data. These results can be seen below in Figure 20.
AFE Signal Output Test Figures


Figure 20: AFE Unexpected Current Draw Figure 20 shows the unexpected current draw from the AFE device. 107mA is 106.9mA over the expected current limit. This figure demonstrates that test 1 fails and causes all subsequent tests to fail.

## Root Causes of Failures

### Failure in AFE Signal Acquisition

When designing the ADS1299 board, an EEPROM section was proactively included in the design with the idea that we would have it there if we found we needed it while testing the board's functionality. This EEPROM had resistors that connected the digital power to ground, however 0 ohm resistors were used instead of those with small values for testing purposes, leading to a short. This short caused a large current draw from the digital power supply to the ADS1299 chip, which we found damaged it. It was determined the chip was damaged after observing that the correct voltage would only be received after a large amount of current to initially power the chip was sent. After trying to connect to the microcontroller to see if anything would be sent, only bits of information could be sent and not at the correct time. This failure was mitigated with a simpler and more concise design. We removed a portion that we found were not going to be needed, including the external clock, EEPROM chip, ensuring we only had the filtering portions for the input power and signals. This was also backed up by similar designs that followed the same specifications with working models for the final design.
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

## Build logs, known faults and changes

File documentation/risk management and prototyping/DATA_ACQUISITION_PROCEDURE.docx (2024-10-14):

Training Data comes from the NinaPro database with the DB2 dataset. Channel content has been modified slightly to accommodate the difference in electrodes from the database, to our project.

Procedure for preparing patient for sEMG collection:

1. Clean Area thoroughly with either soap and water, or a cotton ball or pad soaked in rubbing alcohol (70% isopropyl is acceptable). Allow the area to thoroughly dry
2. Place the first electrode at the medial, proximal forearm, 2-3cm distal from the elbow crease. Along the same plane as the biceps brachii as shown in the picture below:

FIXME=========================

3. Place the second electrode at the same location, but 2cm (center to center) away from the first electrode placement
4. Repeat steps 2-3 three more times, but place the electrode pairs evenly spaced around the proximal forearm, 2-3cm distal from the elbow crease
5. Place a singular electrode pad on the elbow, connect this to the REF pin of the ADS1299
6. Place all other snap leads on the electrodes. The electrode on the inner forearm corresponds to the “Channel 1 differential pair”, and following a lateral rotation around the proximal forearm leads to the order of channels in the standard numerical sense. Note that the training data utilizes 8 channels, and the following mapping must be followed from training data to actual forearm placement:
  a. Channel 4 (training data) → Channel 1
  b. Channel 6 (training data) → Channel 2
  c. Channel 8 (training data) → Channel 3
  d. Channel 2 (training data) → Channel 4

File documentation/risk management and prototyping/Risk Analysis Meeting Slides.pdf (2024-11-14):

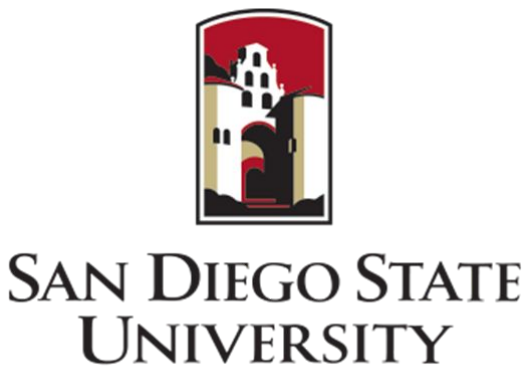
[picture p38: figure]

# Risk Management and Prototyping Plan Team 9 - HANDS-EMG

# Hand Activity Neural Detection using sEMG

# Electrical and Computer Engineering Senior Design (EE491W)

# System Description

Our ECE team is developing a battery-powered surface electromyography (sEMG) sensor system designed to classify hand movements based on the wearer’s muscle activity. The device utilizes four channels of wet electrodes placed on the user’s forearm to capture sEMG signals. These signals are processed through our procured analog front-end module operating at a minimum of 2000 samples per second. The digitized signals are transmitted to our microcontroller via SPI, where a machine learning algorithm classifies the hand movements based on a pre-trained model. Our responsibilities include configuring the analog front-end module, programming a low-power microcontroller, integrating the system on a custom PCB, and training the machine learning model for accurate classification. The system will output the movement classifications via USB, which can be visualized on a PC simulator. Designed for efficiency, the device operates at a voltage of 3.7V provided by a rechargeable lithium polymer battery for portability.

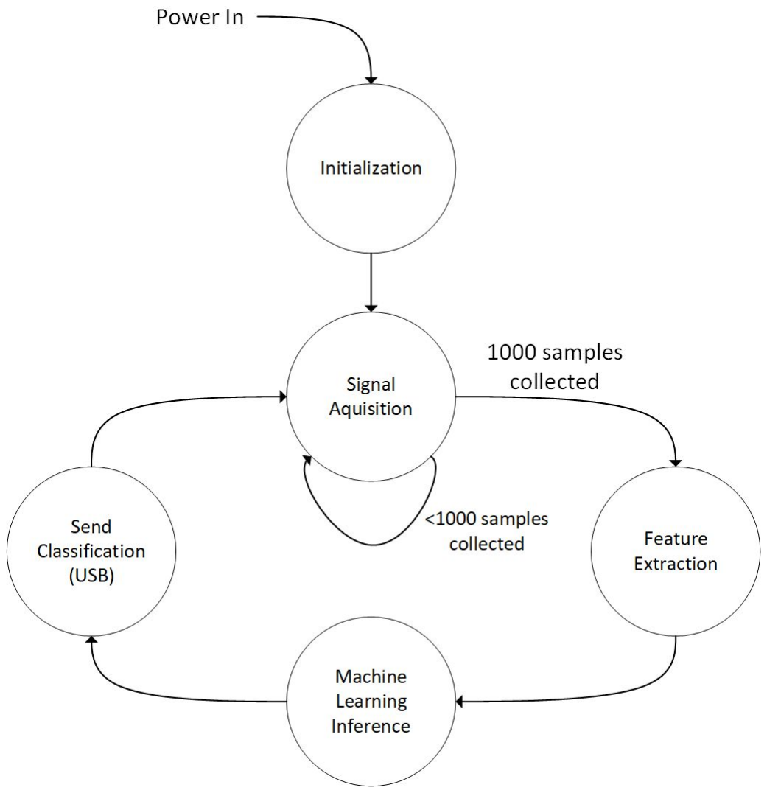
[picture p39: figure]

## Finite State Diagram

The finite state diagram figure shows the main processes that our device performs when powered on.

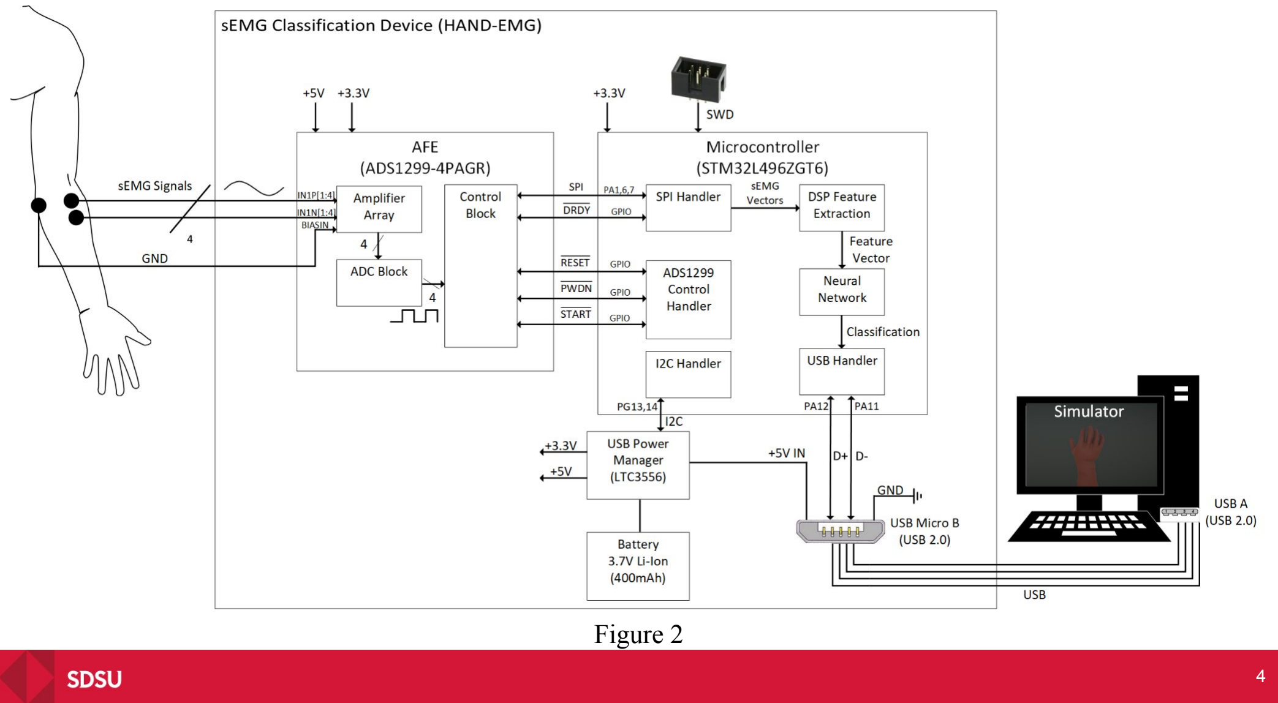
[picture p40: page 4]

Figure 2

## Software Layout

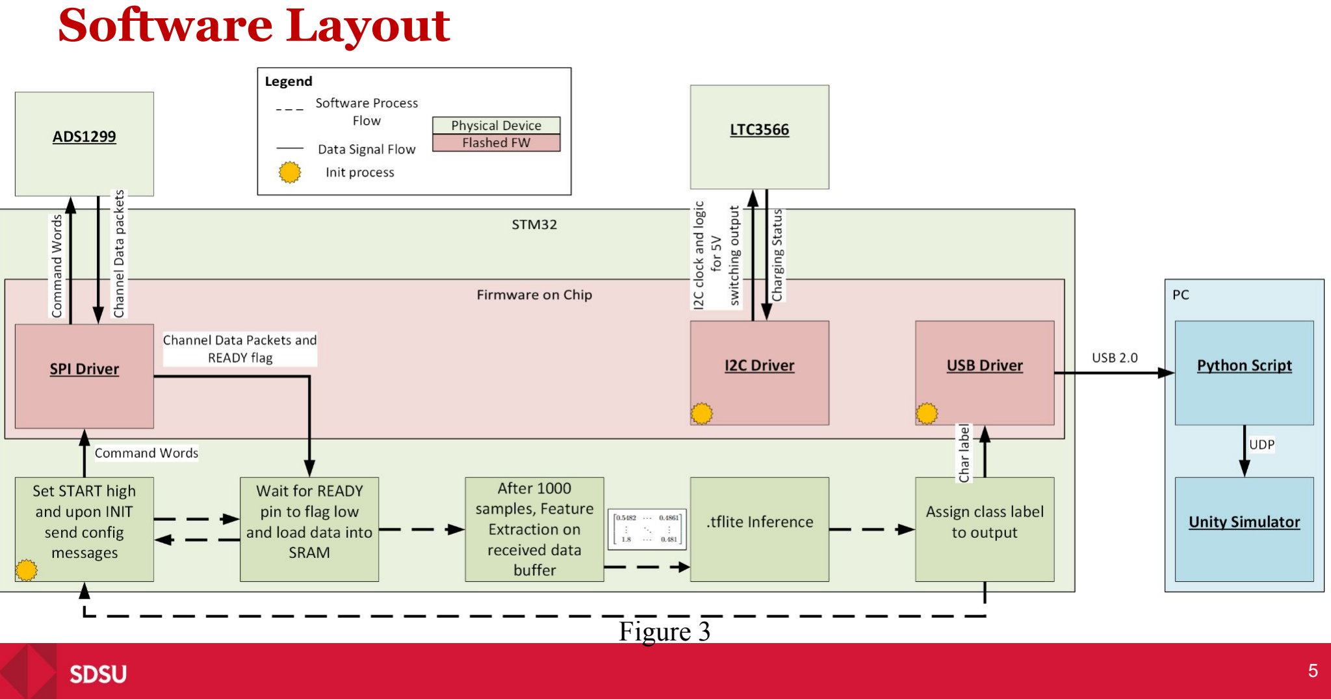
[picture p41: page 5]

Figure 3

# Project Risks

## Risks that affected project definition

| Risk | Description | Project Change
1 | Use of dry electrodes | Dry electrodes presented impractical complexity due to the added impedance and noise. In our analysis there was also a lack of data for dry electrode based classification. | Project was changed to use wet electrodes. These remove the complexity faced with dry electrodes and have a ubiquitous amount of public datasets for classification models.
2 | Time to design custom power management system | Designing a custom battery charger and regulation circuit was impractical due to the extensive time required. | Project was changed to procure a USB power management IC.
3 | Research and design for a custom analog front-end module | Designing an analog front-end that would amplify, filter, and sample our emg signals was impractical due to the engineering complexity. | Project was changed to procure an analog front-end module designed for biomedical purposes that handle the listed activities.

## Summary of low/non-risk items

| Risk | Reason
1 | Power Management | Providing power to our ICs via a 3.7V rechargeable li-ion battery is well documented for both the STM32 and ADS1299 including implementation examples in their respective datasheets. USB power manager (LTC3556) has been selected as our solution.
2 | Communication Protocols | The SPI, I2C, and USB communication protocols are well defined and documented. Communication is handled by the STM32’s hardware modules for simplicity. Team member has experience with SPI and I2C.
3 | Enclosure | A plastic enclosure will be procured from DigiKey and holes will be drilled for external interfaces.
4 | Public Data Availability | Team has identified public database “Ninapro” with 10 datasets including over 180 data acquisitions. Team has identified other public datasets as backup.
5 | Deploying Machine Learning on STM32 | Deploying a TFLite Micro model to STM32 is well documented with open source projects and internal STMicroelectronic documentation available. The documentation includes over 5 examples, a walkthrough, and troubleshooting information.

| Risk | Probability | Impact | Mitigation
1 | ML Classification Accuracy | 3 | 5 | Testing will take place with public data and AFE acquired data.
2 | ML Model Size | 2 | 3 | ML model will be adjusted incrementally beginning in phase 1.
3 | DSP Algorithms | 2 | 4 | Close communication with project mentor. Algorithms are already being prototyped in C.
4 | AFE Configuration | 2 | 5 | Signal acquisition testing begins early in phase 1 with all materials ordered. Allowing team 4 weeks of prototyping.
5 | PCB Design Complexity | 3 | 4 | Three separate PCBs will be designed for each module. Then integrated into a single board after debugging.
6 | System Integration | 3 | 5 | Modules will be tested individually with debugging tools to ensure proper technical characteristics before integration.

5

4

3 | | | | 5 | 1,6
2 | | | 2 | 3 | 4

1

| 1 | 2 | 3 | 4 | 5

Impact

Probability

## Risk Cube

Figure 4

## Risk Table

Risk | Description | Probability | Impact

1

ML
Classification
Accuracy

An accurate
machine learning
model is necessary
to make consistent
classifications of
movements.
Standard accuracy
of between 70%
and 90% is
necessary.

Datasets with over 180
acquisitions specifically
for this application were
identified. Analysis of
similar models coupled
with a considerable
amount of data show this
accuracy is possible. The
probability is estimated as 3.

A system with a low
accuracy model will
often provide
incorrect
classifications. A
completely
inaccurate model will
not provide any
classifications. The
impact is estimated
to be a 5.

## Risk Table

Risk | Description | Probability | Impact

2

ML Model
Size

Machine learning
models can be
computationally
expensive and
large in size.
Deploying this on
a microcontroller
with limited
memory is a risk
factor.

The STM32L4 we selected
has 1MB of flash. Analysis of literature and existing projects show EMG
classification modules
operating on 1MB devices.
The STM32U5 with 4MB
has been identified as an
alternate option with the
same pinout. The
probability is a 2.

Model complexity is
an important factor to
its size. If model size
presents itself to be
an issue, then a new
model will be trained
with less gestures to
classify. The impact
is a 3.

## Risk Table

Risk | Description | Probability | Impact

3

DSP
Algorithms

The digital output of
the ADS1299 needs
to be processed
prior to feature
extraction to ensure
that captured data
matches training
data, if the features
extracted are not
within an acceptable
range, the
inferences will be
inaccurate

The features being used are non-intensive, and upon
analysis, the datasets being used are in an easy to modify format. STM also runs
subroutines to dedicate
majority processing power to feature extraction.
Additionally, the literature backs up our specified
features as an industry
standard. Probability is a 2.

If the signals are not
properly conditioned,
or the MCU is unable
to perform feature
extraction as on our
PC, the machine
learning model
performance will
suffer, thus the impact
is a 4.

## Risk Table

Risk | Description | Probability | Impact

4

AFE
Configuration

The ADS1299
module has many
configuration options
including amplifier
gain and sampling
frequency. The
proper combination
of these options is
necessary to receive
a clean sEMG signal
for classification.

Existing research for
the use of the
ADS1299 for EMG
has been identified.
The ADS1299 was
selected at the advice
of our project advisor
who has used it
previously for similar
applications. For this
reason the
probability is a 2.

Our project relies
heavily on proper
signal acquisition.
Without proper
signals, the
microcontroller will
fail to classify the
movement. The
impact is a 5.

## Risk Table

Risk | Description | Probability | Impact

5

PCB Design
Complexity

Currently, the
proposed system
utilizes three ICs
with a combined
chip area of
564mm²
, and a
total number of
236 pins. This
increases the
complexity needed
for the PCB layout
substantially

Each devices data sheets
provide examples of
schematic setups for
implementing on a custom
PCB. Breaking up the PCB
design by component, we
can more easily finalize.
Our eval boards will give
us hands on knowledge of
the boards and necessary
pinouts. Probability is 3

If design of PCBs is
not done properly,
there could be
problems with noise
or signal degradation,
which would affect
the data
received/outputted
giving inaccurate
results. Impact is 4.

## Risk Table

Risk | Description | Probability | Impact

6

System
Integration

Our proposed system
has 3 major
components. Power
management, analog
front-end, and the
microcontroller
which all have
different control and
communication
protocols.

While creating each
PCB, there will be
thorough testing and
debugging for each
system to ensure they
work individually
before full
integration. Also, the
communication
modules will have a
working prototype
Probability is 3

Since we are on
putting all three
systems on one PCB,
if the subsystems are
unable to
communicate
properly, or the
physical layout was
done incorrectly, then
the total system
would fail. Impact is
5

# Prototyping Plan

## Prototyping Roadmap

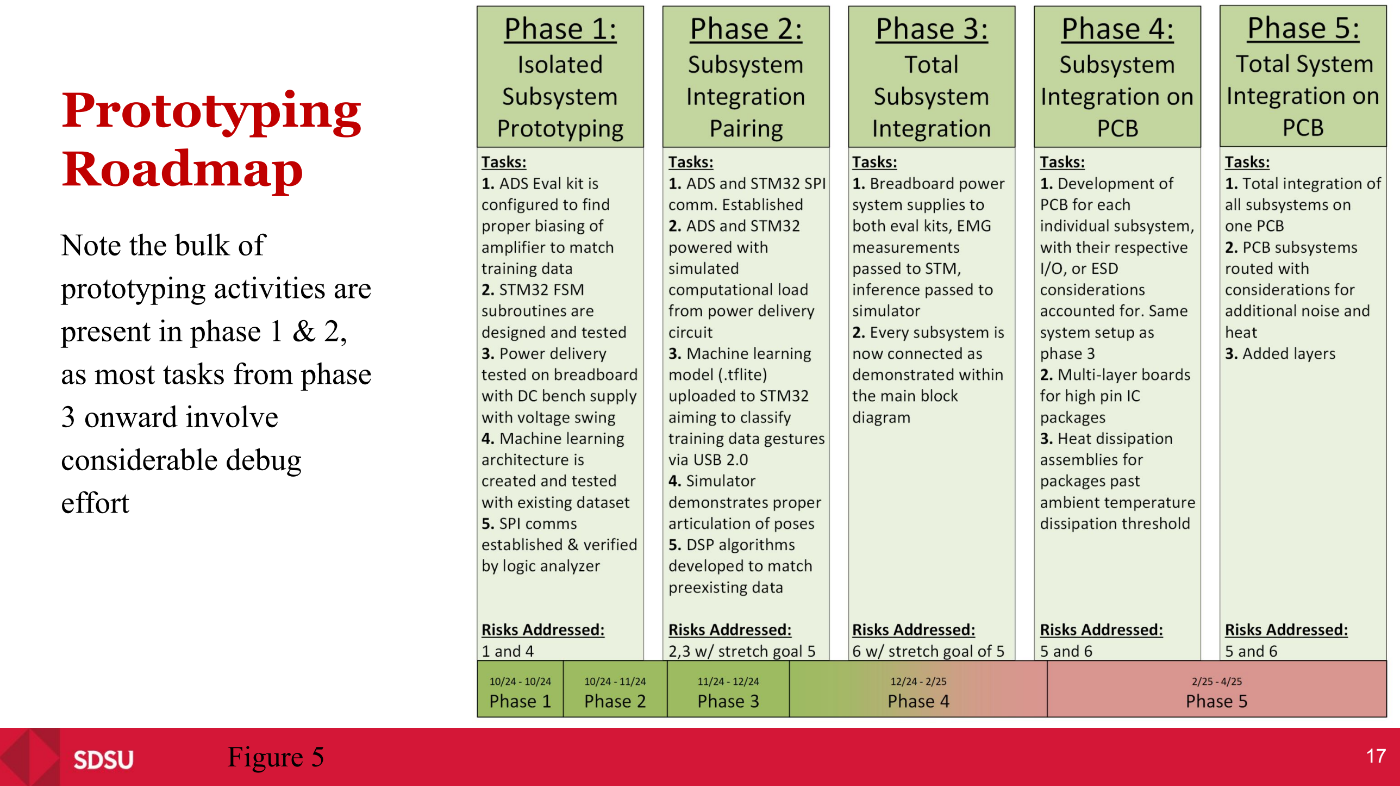
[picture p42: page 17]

Note the bulk of
prototyping activities are present in phase 1 & 2,
as most tasks from phase
3 onward involve
considerable debug
effort
Figure 5 | 17

## Phase 1 Description

Our prototype activities in phase 1 will target Risk #1 (ML Classification Accuracy) as well as Risk #4 (AFE Configuration). These risks were targets for initial prototyping in phase 1 because of their high impact on the project. The prototyping activity will consist of coding our subroutines on the STM to ensure proper functioning, building and training our ML model to ensure viable accuracy, finding the correct biasing of the PGA, configuring our PMIC to properly output the desired voltages, and verifying the SPI communication follows standard protocols. The devices and tools needed to complete this phase have already been procured. The activity will involve programming the MCU and the ADS using their prebuilt GUI, identifying proper protocols in both sets of SPI interfaces, and finally measuring test points along the QFN-28 to DIP-28 connector.

## Phase 1 Activity Steps

1. ADS Configuration
a. Place electrodes on arm as described in “Electrode Placement Protocol” and connect them to the eval board
b. Connect the eval kit to the PC, and open the TI ADS1299EEGFE Software
c. Adjust the gain of the channel preamplifiers to match the frequency content and amplitude of the acquired signals to that of the training data
2. STM32 Subroutine
a. Connect the STM32 board to the PC
b. Open the CubeIDE software to program the STM32
c. Design and debug subroutines to follow the functionality of our block diagram
3. LTC3556 Verification
a. Solder the QFN-28 LTC3556 onto the DIP-28 converter (designed item) with header pins
b. Plug into breadboard
c. Locate the pin labels on the converter, and align them to match the input voltage
4. Machine Learning Model Construction
a. Use preexisting TensorFlow Lite libraries to construct a ML model that the STM is capable of utilizing
b. In Matlab, format the data as it will be done on the MCU, including the windowing size, method, and actual features extracted from each window
c. Separate data into a 70/20/10 split for training, validation, and testing data
d. Train the model, adjusting hyperparameters as needed
5. SPI Communication Establishment
a. Utilizing the firmware packages on the STM32, send some example messages via SPI to a logic analyzer
i. Tune the device if unexpected messages are occurring (likely timing errors within the code)
b. While capturing data, pulse the START pin high and visualize the output of the SPI lines along the logic analyzer

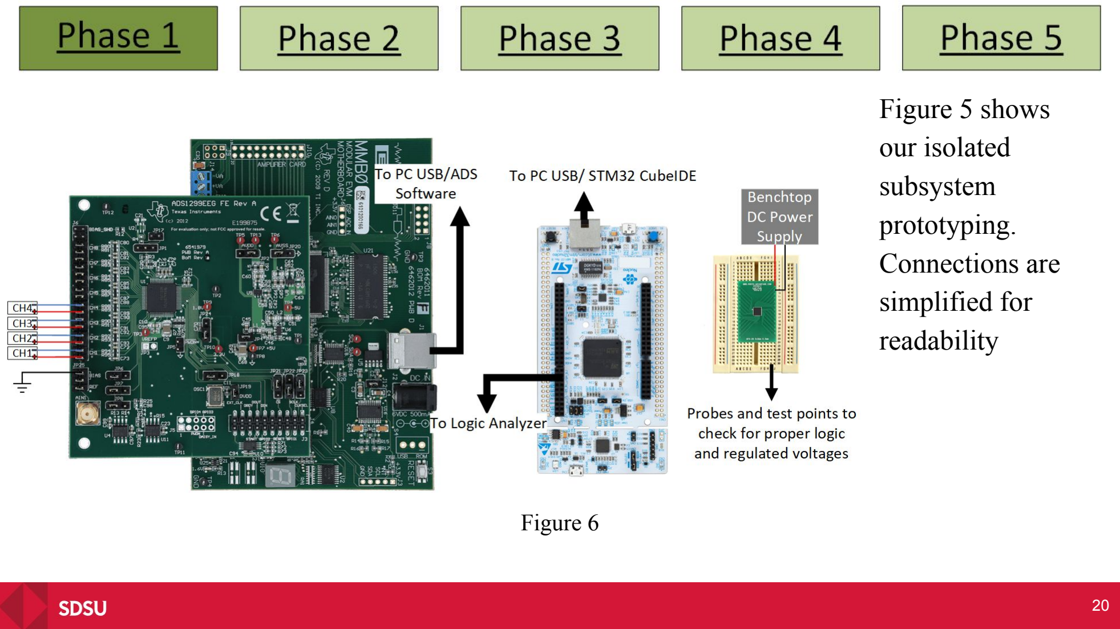
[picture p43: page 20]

Figure 5 shows
our isolated
subsystem
prototyping.
Connections are
simplified for
readability

Figure 6

## Phase 2 Description

Our prototype activity in phase 2 will target Risk #2 (ML Model Size), and Risk #3 (DSP Algorithms) with a stretch goal of Risk #5 (PCB Design Complexity). These risks were targets for early prototyping in phase 2 because of their high impact on the project. The prototyping activity will consist of writing the necessary code to establish communication between the ADS and STM32, powering both devices with our power delivery circuit with a simulated computational load, uploading the trained machine learning model to the STM32, and developing the necessary DSP algorithms to produce features. The devices necessary to conduct this prototyping phase have already been procured. The activity itself will involve capturing the communication between the STM32 and ADS using the logic analyzer to visualize the waveforms on matlab, and feeding the training data to the uC via USB and viewing the classification that is outputted.

## Phase 2 Activity Steps

1. Power Management Verification
a. Connect power management circuit to USB Micro B power delivery.
b. Connect +3.3V output to STM32 Vin.
c. Connect +5V output to ADS1299 Vin.
d. Verify both boards constant power and are able to connect to PC for programming.
2. ADS1299 and STM32 Communication
a. Write SPI communication code for STM32
b. Connect ADS1299 SPI lines to STM32 SPI lines.
c. Use ADALM2000/AD3 to verify SPI communication occurring.
d. Use ADALM2000/AD3 script to capture SPI packets and visualize sEMG signal sent.
3. PC Simulator Verification
a. Open the open source Unity simulator on PC.
b. Create python script that will send fixed test poses to simulator via UDP socket.
c. Verify simulator displays the poses in the sent test sequence.

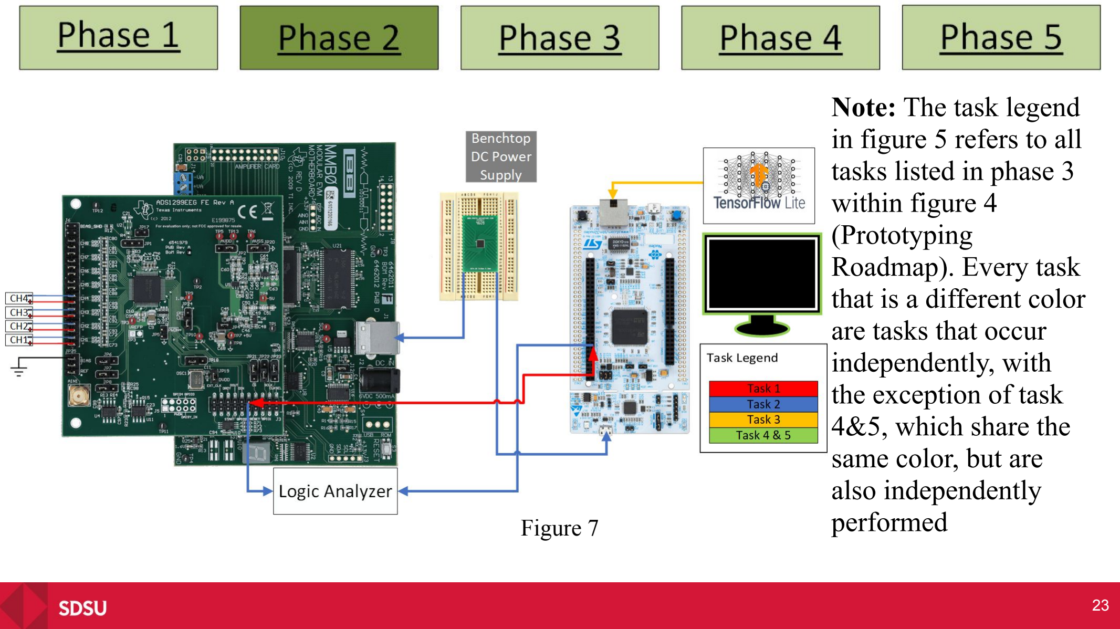
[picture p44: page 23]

Note: The task legend
in figure 5 refers to all
tasks listed in phase 3
within figure 4
(Prototyping
Roadmap). Every task
that is a different color
are tasks that occur
independently, with
the exception of task
4&5, which share the
same color, but are
also independently
performed
Figure 7

## Phase 3 Description

Phase 3 addresses Risk #6 (System Integration) with a stretch goal of Risk #5 (PCB Design Complexity). This phase showcases the integration of an EMG measurement subsystem using evaluations kits, highlighting the capture and transmission of muscle signals for analysis. The setup with an EMG sensor attached to the target muscle, measuring electrical signals generated by contractions and sending them to the (AFE), which amplifies and filters the signals.

The ADS1299 ADC then converts these amplified signals into digital data. This data is processed by the STM32L496ZG6ZGT6 microcontroller, programmed to initialize the ADC and set a sampling rate of 2000 samples per second (SPS). The microcontroller continuously reads the data and transmits it via I2C or SPI to a computer running simulation software.

The simulation software visualizes real time EMG waveforms, offering immediate feedback on muscle activity and analytical tools for filtering and peak directions.

## Phase 3 Activity Steps

1. Total Subsystem Integration
a. Place all subsystems and eval kits on the same ESD safe workspace
b. Connect and remove necessary jumpers on the ADS1299EEGFE as per the documentation instructions
c. Wire the SPI Lines according to the pinout specified in the block diagram (figure 2)
d. Plug the micro USB into the USR_DTA port of the STM32 eval kit
e. Wire the I2C from the LTC3556 to the STM32 according to the pinout specified in the block diagram (figure 2)
f. Locate the AVdd pin on the ADS eval board, and connect the 5V output of the PMIC to that pin
g. Locate the DVdd pin on the ADS eval board, and the PWR_IN pin on the STM32 eval kit, and connect that to the “Always on” 3.3V line of the PMIC
h. Finally connect the battery, and wait for the system to initialize
i. After init period, the data should be displaying on a PuTTy window, which verifies functionality of the device

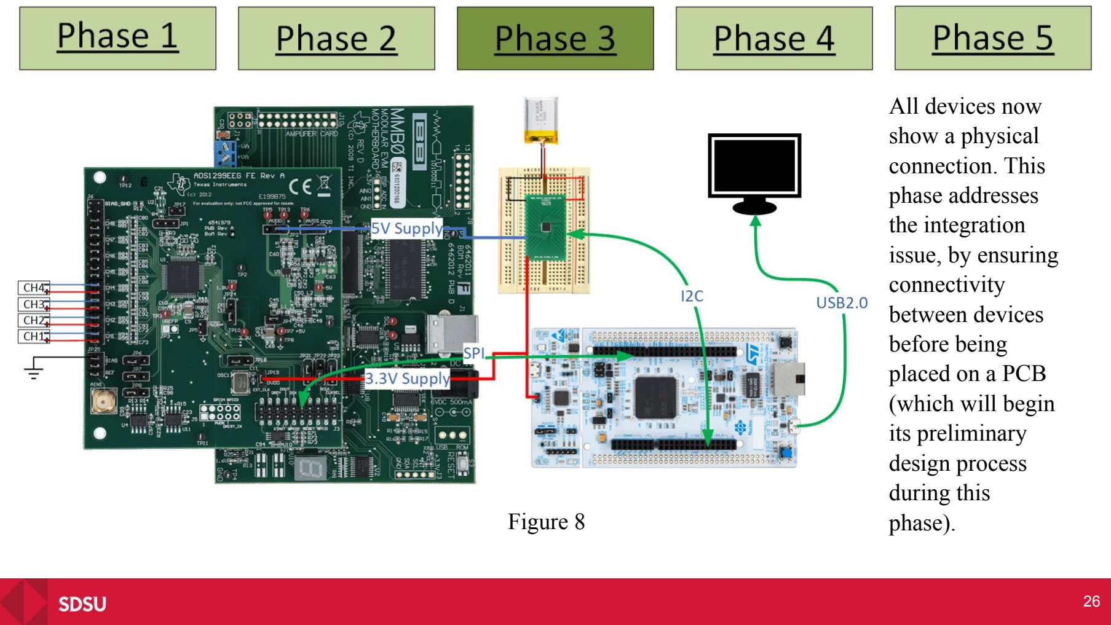
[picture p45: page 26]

All devices now
show a physical
connection. This
phase addresses
the integration
issue, by ensuring
connectivity
between devices
before being
placed on a PCB
(which will begin
its preliminary
design process
during this
phase).

Figure 8

## Phase 4 Description

Our Prototype activity in phase 4 is targeting Risk #5 (PCB Design and complexity) as well as Risk #6 (System Integration). These had posed a significant impact on the project so addressing them was made to be an important part of the prototyping process. This prototyping process will be the application of the eval testing into KiCad with the necessary pinouts found in phase 3 onto individual PCBs for each subsystem. The power delivery circuit will power both the ADS and the STM32, input signals will be processed and sent to the microcontroller, and the microcontroller will be able to receive those ADS signals to process and classify as movements for the simulator, as well as monitor the charging circuit for the power circuit. ESD considerations also accounted for (via Decoupling coupling and proper ground planes), as well as heat dissipation methods where necessary (via capacitors near power pins and trace designs that can handle higher currents AKA wider traces where needed).

## Phase 4 Activity Steps

1. Modeling PCBs
a. Based on phase 3 testing, use KiCad to create each PCB subsystem with the correct pinouts
b. Test each circuit in the PCB simulation and verify all pinouts are correct and can communicate with the other subsystems where necessary before printing
2. Power Management Circuit
a. Connect battery to USB Micro B
b. Connect +5V output to ADS1299 Vin
c. Connect +3.3V output to ADS1299 Vin and STM32 Vin
3. ADS1299
a. Verify connecting points of electrodes and ensure the board has proper grounding for the analog and digital inputs voltage inputs
b. Connect via SPI to the STM32
4. STM32
a. Ensure connection from ADS, power circuit, and connect Via USB micro to simulator
b. Run through commands to receive signals from ADS and process them with correct classification onto the simulator

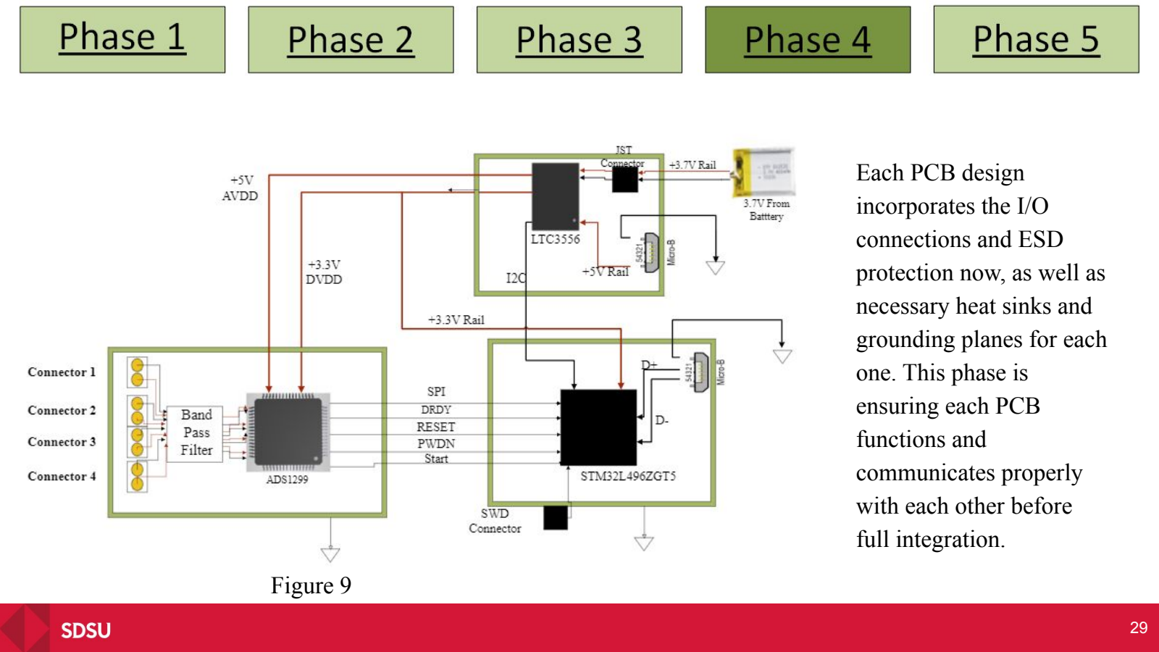
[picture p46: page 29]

Each PCB design
incorporates the I/O
connections and ESD
protection now, as well as necessary heat sinks and
grounding planes for each
one. This phase is
ensuring each PCB
functions and
communicates properly
with each other before
full integration.

Figure 9

## Phase 5 Description

Our prototype activity in phase 5 will target Risk #5 (PCB Design Complexity), and Risk #6 (System Integration). The phase 5 activity involves taking the three separate subsystems and integrating them into a single PCB. As previously mentioned in phase 4, the subsystems consist of power management, ADC, and the microcontroller. Each subsystem must be precisely routed in order to minimize the amount of noise interference and heat dissipation. Throughout the design and layout process we must ensure that the analog and digital components stay separate, use short signal paths, and opt for a multilayer PCB to isolate power and signal planes. This activity is crucial in order to preserve the signal integrity of our analog inputs.

## Phase 5 Activity Steps

- Integrate power management, ADC, and microcontroller subsystems into a single PCB
- Route signal paths as short as possible to minimize noise interference
- Place decoupling capacitors near each subsystem’s power pins to filter noise
- Implement thermal management by placing heat sinks near heat-sensitive components
- Use a multilayer PCB to isolate power, ground, and signal planes to reduce cross-talk

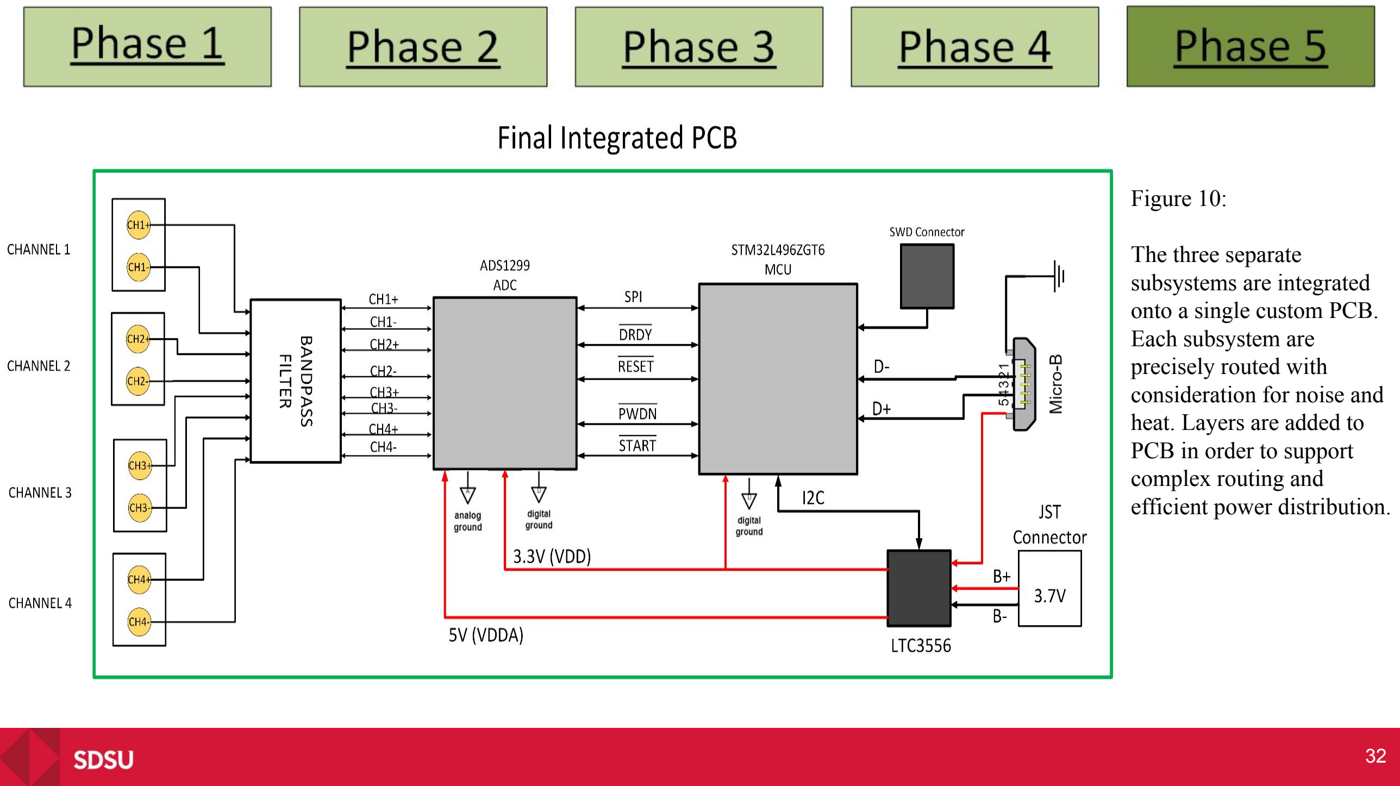
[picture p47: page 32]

Figure 10:

The three separate
subsystems are integrated
onto a single custom PCB.
Each subsystem are
precisely routed with
consideration for noise and heat. Layers are added to
PCB in order to support
complex routing and
efficient power distribution.

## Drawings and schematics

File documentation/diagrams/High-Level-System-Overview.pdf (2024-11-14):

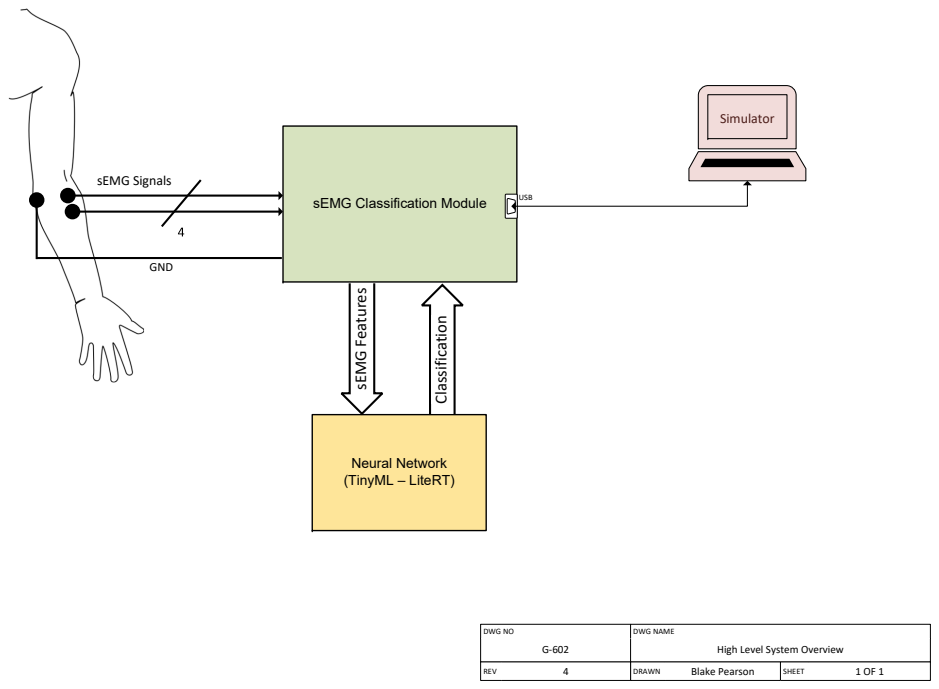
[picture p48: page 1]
Neural Network (TinyML – LiteRT); sEMG Features; Classification; Simulator; USB; sEMG Signals; GND

sEMG Classification Module

DWG NO | DWG NAME

G-602 | High Level System Overview

REV | 4 | DRAWN | Blake Pearson | SHEET | 1 OF 1

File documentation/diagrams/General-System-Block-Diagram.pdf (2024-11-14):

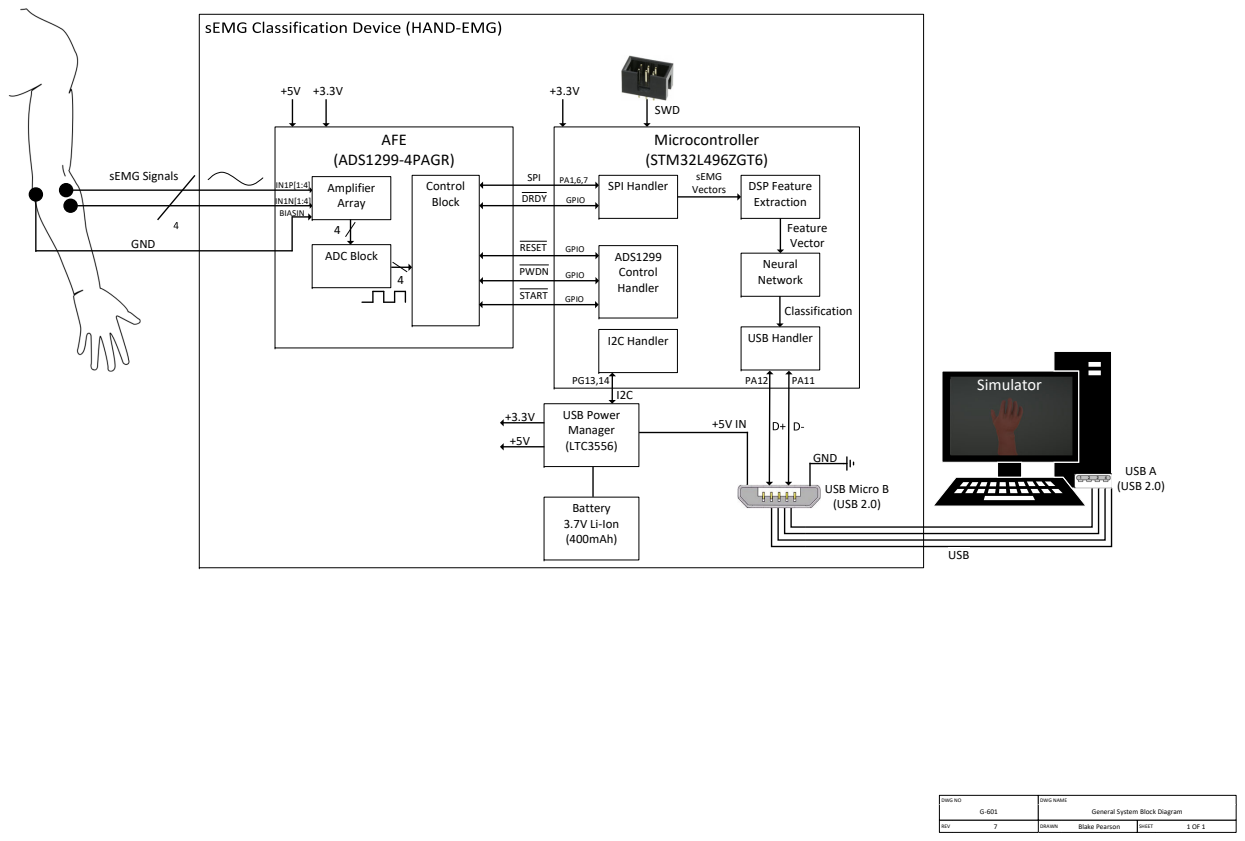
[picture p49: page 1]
REV; DRAWN; Blake Pearson; SHEET; DWG NO; DWG NAME; AFE (ADS1299-4PAGR); Microcontroller (STM32L496ZGT6); sEMG Signals; GND; IN1N[1:4] BIASIN; SWD; USB Power Manager (LTC3556); Battery 3.7V Li-Ion (400mAh); Amplifier Array; ADC Block; SPI; Control; SPI Handler; Block; DRDY; GPIO; DSP Feature Extraction; Neural Network; USB Handler; ADS1299 Control Handler; RESET; PWDN; START; sEMG Vectors; Feature Vector; Classification; USB Micro B (USB 2.0); Simulator; USB; USB A (USB 2.0); I2C Handler

General System Block Diagram

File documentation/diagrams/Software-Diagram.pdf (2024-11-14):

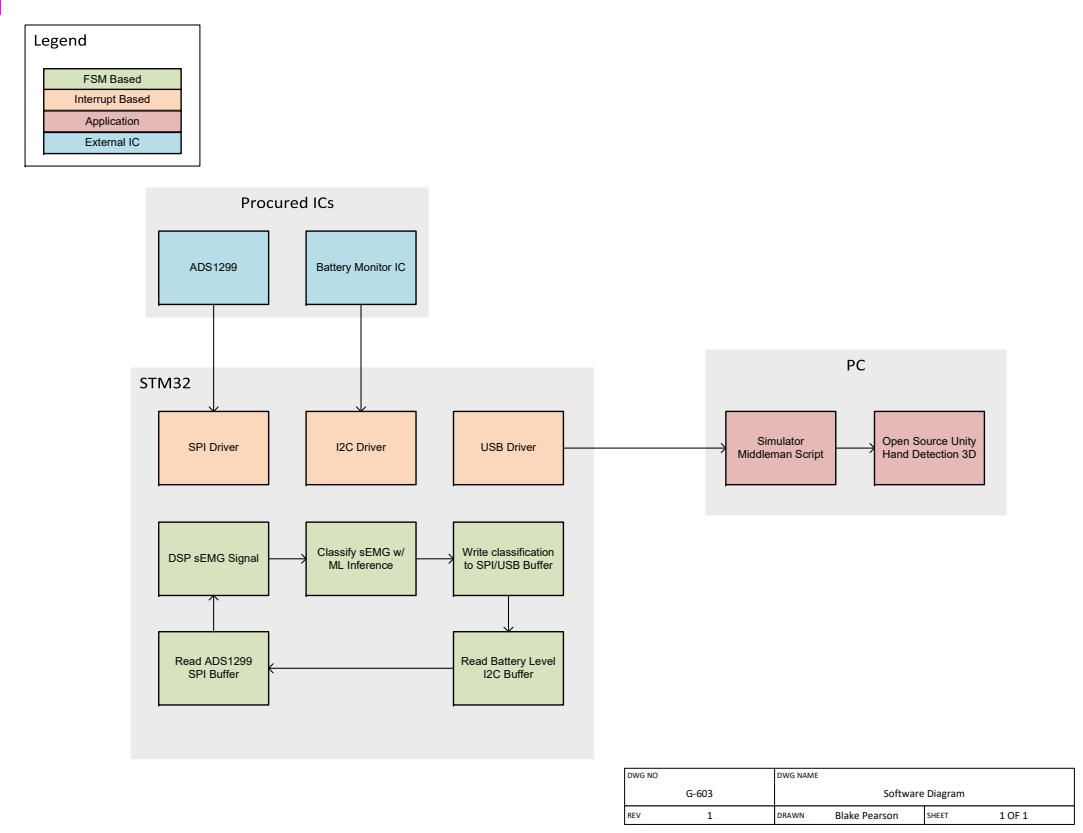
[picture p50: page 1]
FSM Based; Interrupt Based; REV; DRAWN; Blake Pearson; SHEET; DWG NO; DWG NAME; Software Diagram; SPI Driver; I2C Driver; USB Driver; Read ADS1299 SPI Buffer; DSP sEMG Signal; Classify sEMG w/ ML Inference; Write classification to SPI/USB Buffer; Simulator Middleman Script; Application; External IC; ADS1299; Battery Monitor IC

Open Source Unity
Hand Detection 3D

Read Battery Level
I2C Buffer

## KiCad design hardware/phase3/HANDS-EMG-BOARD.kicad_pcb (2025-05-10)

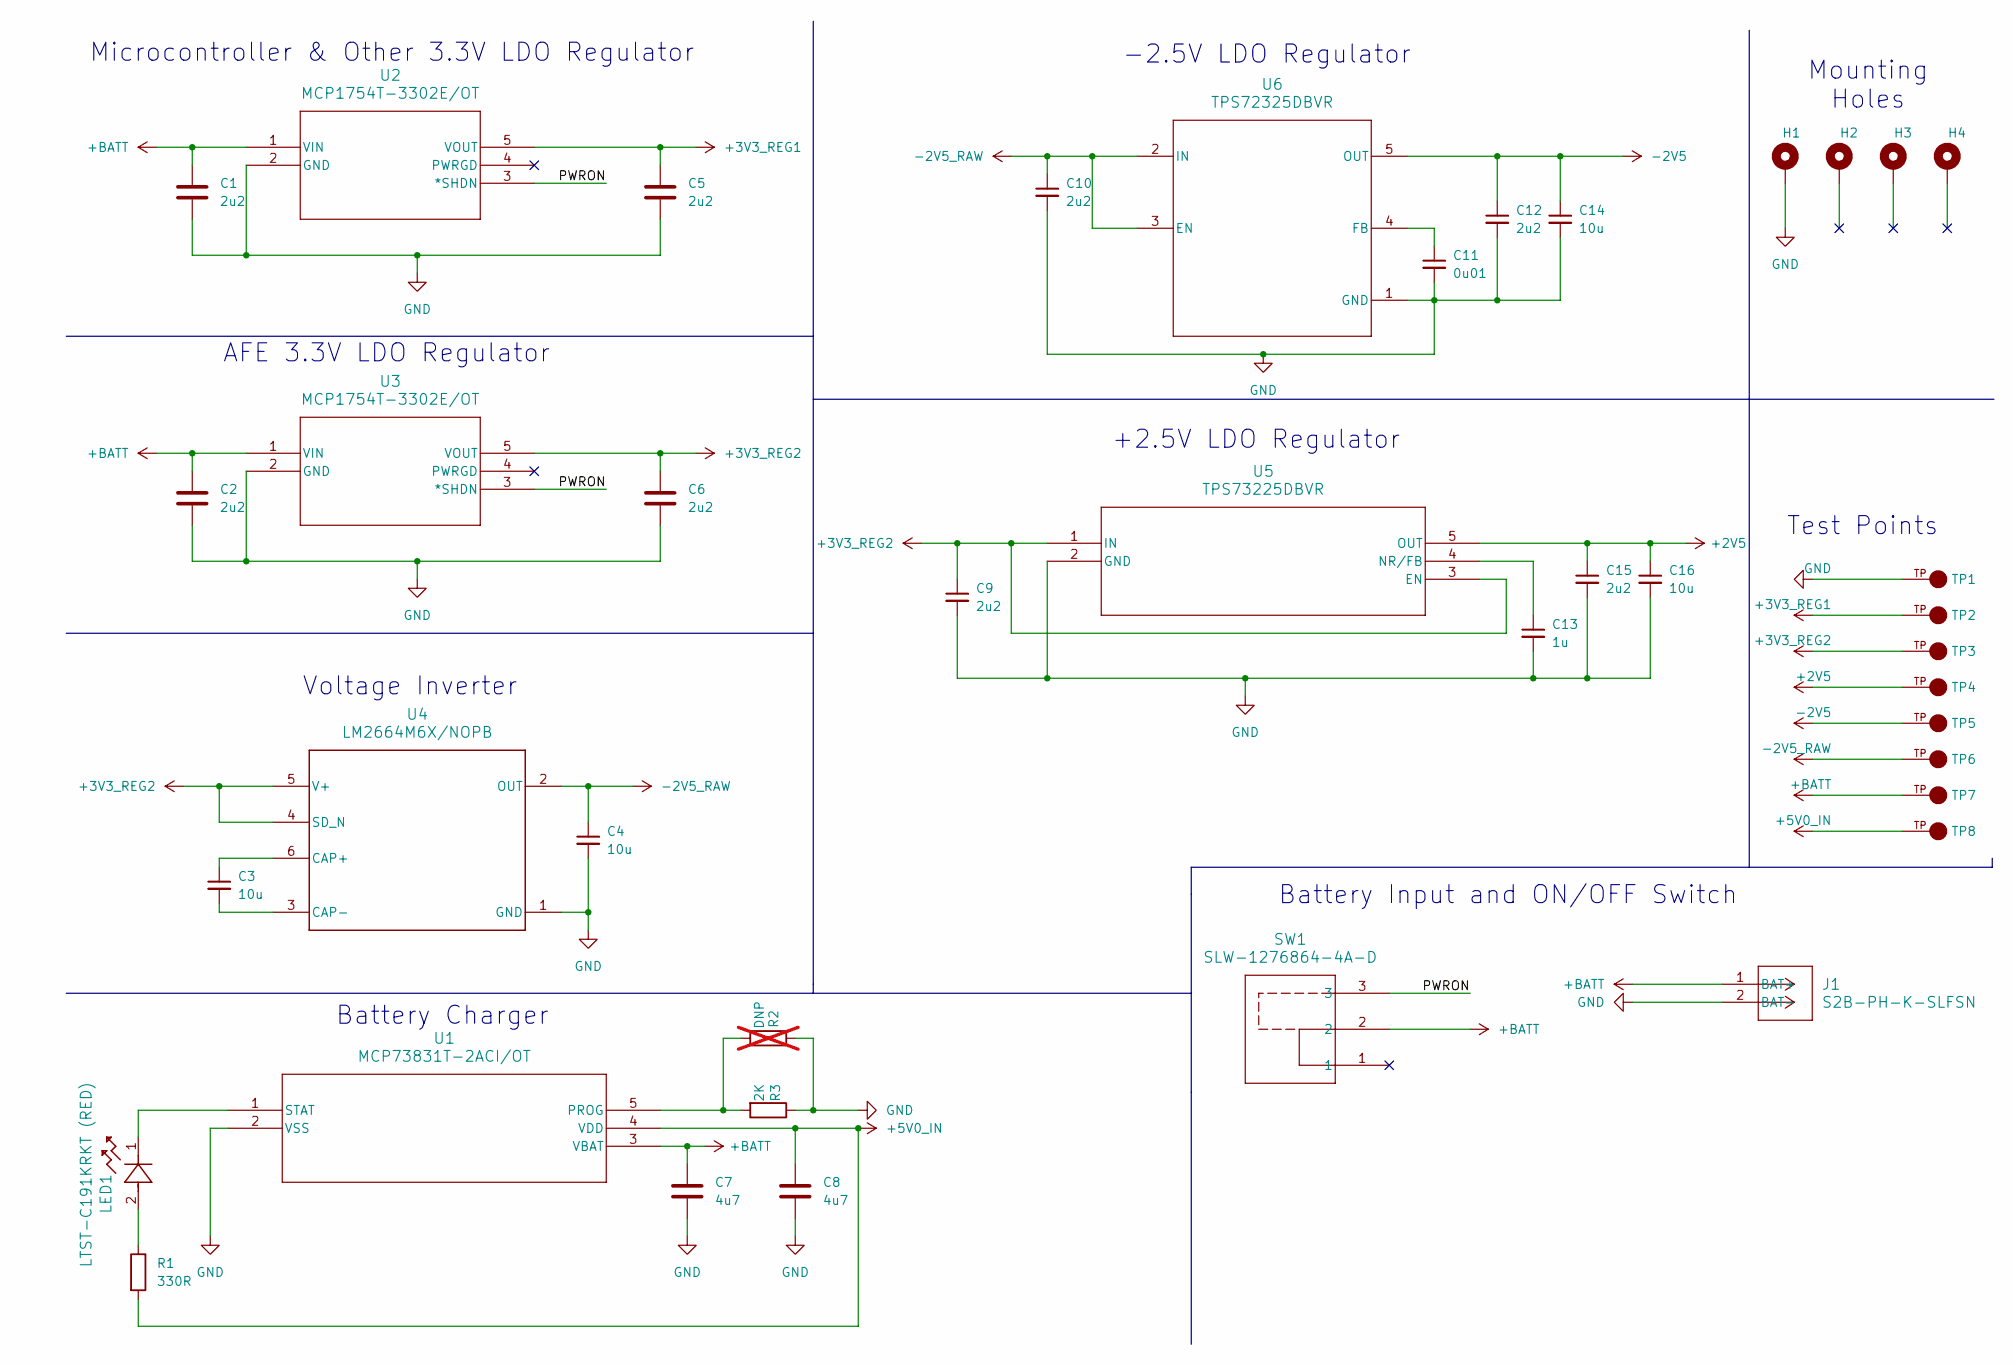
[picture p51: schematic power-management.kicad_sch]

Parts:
C1, C2, C5, C6, C9, C10, C12, C15: 2u2; C_0402_1005Metric
C3, C4, C14, C16: 10u; C_0603_1608Metric
C7, C8: 4u7; C_0603_1608Metric
C11: 0u01; C_0402_1005Metric
C13: 1u; C_0402_1005Metric
H1, H2, H3, H4: MountingHole_Pad; MountingHole_2.2mm_M2_Pad
J1: S2B-PH-K-SLFSN; S2B-PH-K-S
LED1: LTST-C191KRKT (RED); LTST-C191KRKT
R1: 330R; R_0603_1608Metric
R2: DNP; R_0603_1608Metric; not fitted
R3: 2K; R_0603_1608Metric
SW1: SLW-1276864-4A-D
TP1, TP2, TP3, TP4, TP5, TP6, TP7, TP8: 5015; PARTREV F
U1: MCP73831T-2ACI/OT; MCP73831T-2ACI-OT
U2, U3: MCP1754T-3302E/OT; MCP1754T-3302E-OT
U4: LM2664M6X/NOPB; LM2664M6X-NOPB
U5: TPS73225DBVR
U6: TPS72325DBVR

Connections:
+2V5: C15.1, C16.1, TP4.TP, U5.5 (OUT); also elsewhere on the board
+3V3_REG1: C5.1, TP2.TP, U2.5 (VOUT); also elsewhere on the board
+3V3_REG2: C6.1, C9.1, TP3.TP, U3.5 (VOUT), U4.4 (SD_N), U4.5 (V+), U5.1 (IN), U5.3 (EN); also elsewhere on the board
+5V0_IN: C8.1, R1.2, TP8.TP, U1.4 (VDD); also elsewhere on the board
+BATT: C1.1, C2.1, C7.1, J1.1 (BAT+), SW1.2, TP7.TP, U1.3 (VBAT), U2.1 (VIN), U3.1 (VIN)
-2V5: C12.1, C14.1, TP5.TP, U6.5 (OUT); also elsewhere on the board
-2V5_RAW: C4.1, C10.1, TP6.TP, U4.2 (OUT), U6.2 (IN), U6.3 (EN)
/Power-Management/PWRON: SW1.3, U2.3 (*SHDN), U3.3 (*SHDN)
GND: C1.2, C2.2, C4.2, C5.2, C6.2, C7.2, C8.2, C9.2, C10.2, C11.2, C12.2, C13.2, C14.2, C15.2, C16.2, H1.1, J1.2 (BAT-), R2.1, R3.1, TP1.TP, U1.2 (VSS), U2.2 (GND), U3.2 (GND), U4.1 (GND), U5.2 (GND), U6.1 (GND); also elsewhere on the board
unnamed: LED1.2, R1.1
unnamed: R2.2, R3.2, U1.5 (PROG)
unnamed: LED1.1, U1.1 (STAT)
unnamed: C3.1, U4.6 (CAP+)
unnamed: C3.2, U4.3 (CAP-)
unnamed: C13.1, U5.4 (NR/FB)
unnamed: C11.1, U6.4 (FB)

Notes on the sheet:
Battery Charger
+2.5V LDO Regulator
AFE 3.3V LDO Regulator
Test Points
Mounting Holes
-2.5V LDO Regulator
Voltage Inverter
Microcontroller & Other 3.3V LDO Regulator
Battery Input and ON/OFF Switch

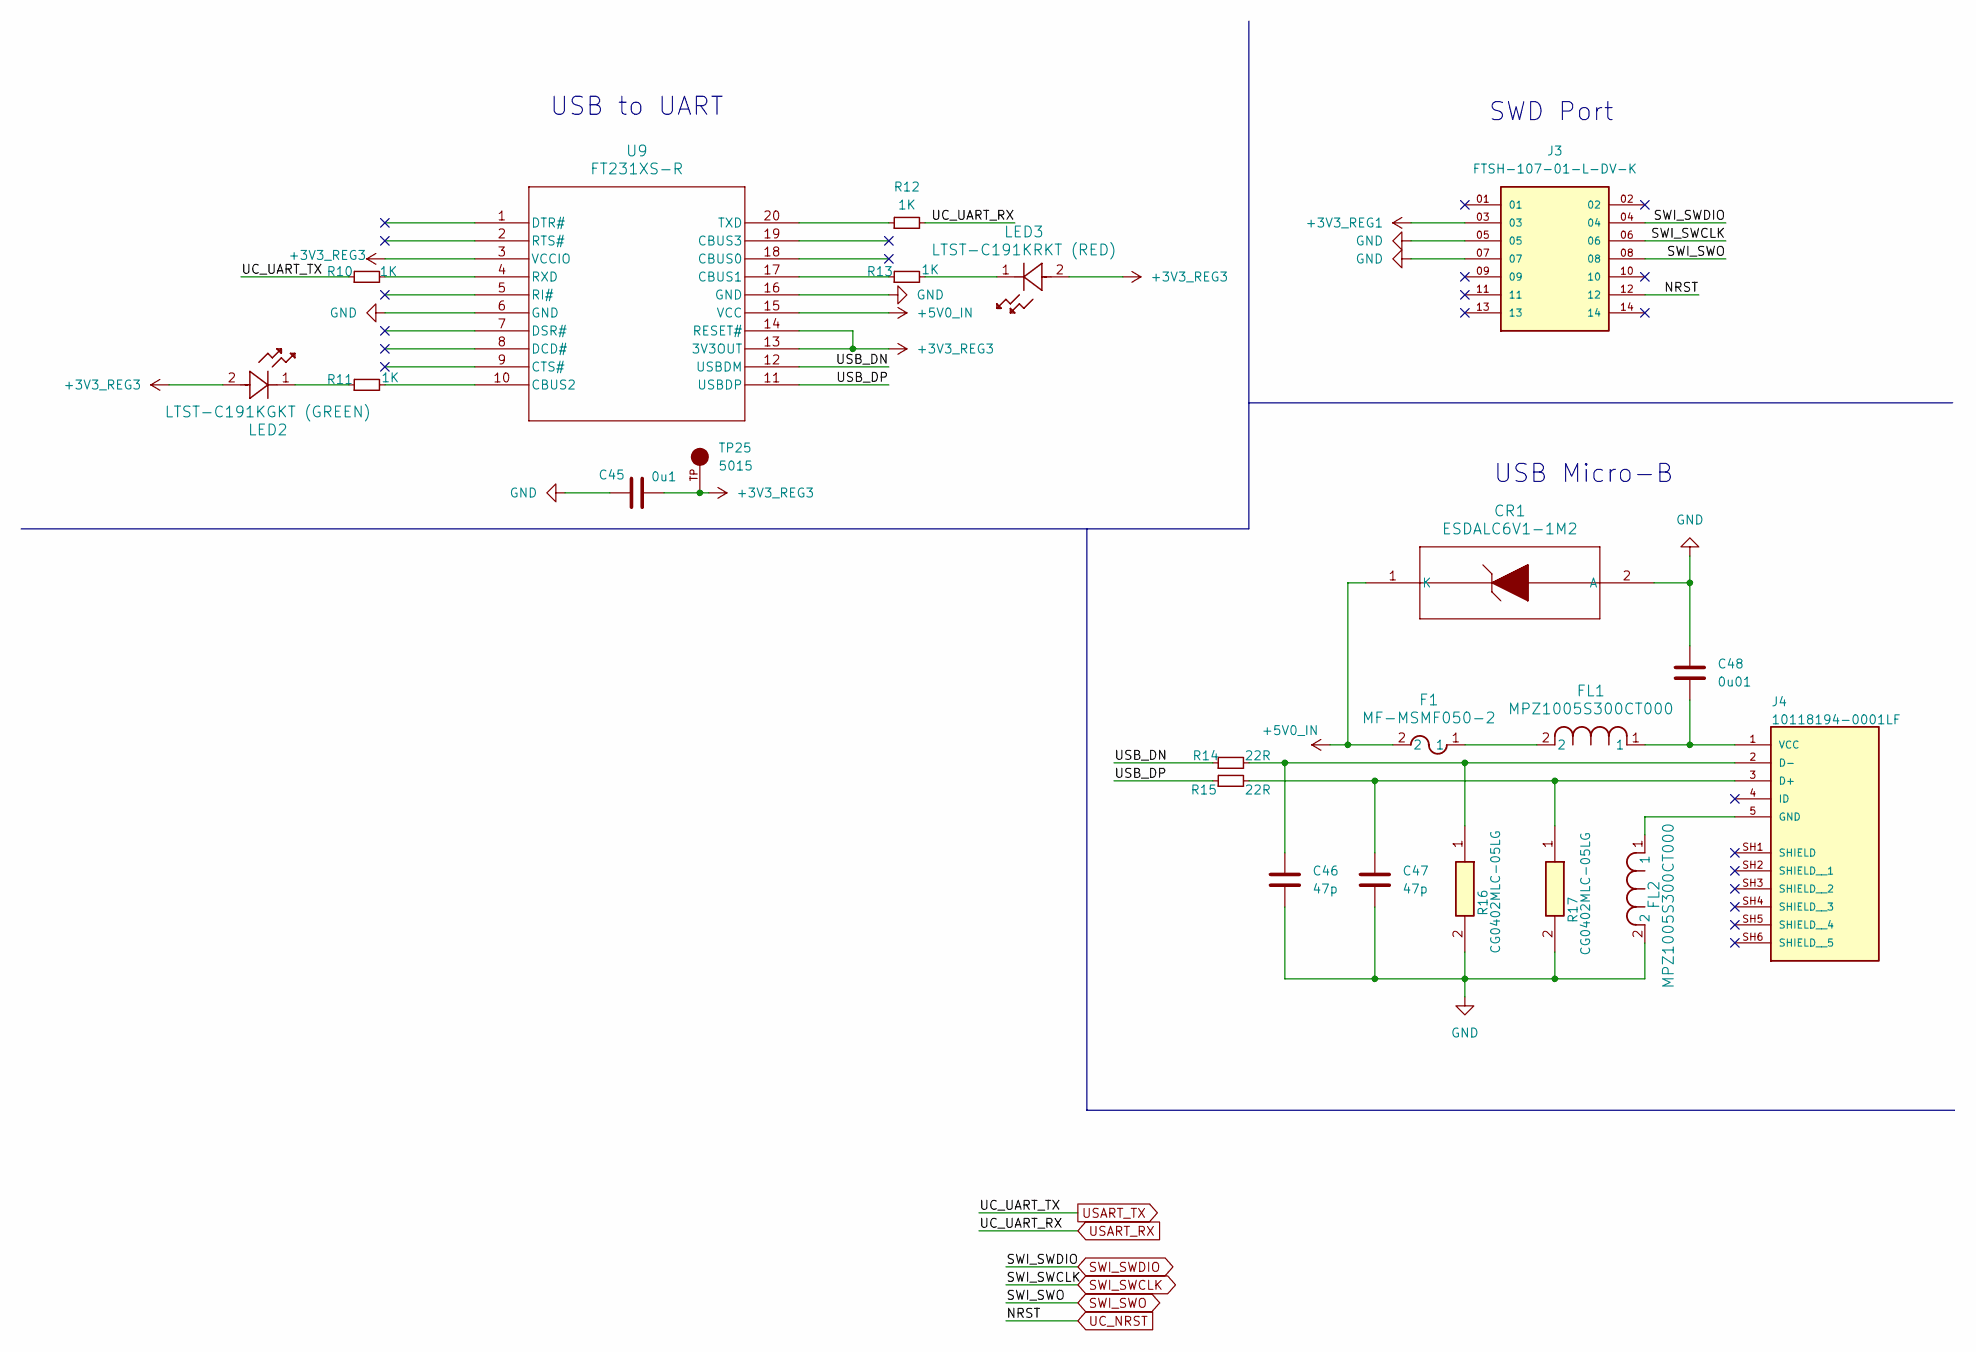
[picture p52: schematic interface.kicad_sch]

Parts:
C45: 0u1; C_0402_1005Metric
C46, C47: 47p; C_0402_1005Metric
C48: 0u01; C_0402_1005Metric
CR1: ESDALC6V1-1M2
F1: MF-MSMF050-2
FL1, FL2: MPZ1005S300CT000
J3: FTSH-107-01-L-DV-K; PARTREV R
J4: 10118194-0001LF; PARTREV D
LED2: LTST-C191KGKT (GREEN); LTST-C191KGKT
LED3: LTST-C191KRKT (RED); LTST-C191KRKT
R10, R11, R12, R13: 1K; R_0603_1608Metric
R14, R15: 22R; R_0402_1005Metric
R16, R17: CG0402MLC-05LG
TP25: 5015; PARTREV F
U9: FT231XS-R

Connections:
+3V3_REG1: J3.03; also elsewhere on the board
+3V3_REG3: C45.2, LED2.2, LED3.2, TP25.TP, U9.3 (VCCIO), U9.13 (3V3OUT), U9.14 (RESET#)
+5V0_IN: CR1.1 (K), F1.2, U9.15 (VCC); also elsewhere on the board
/Interface/USB_DN: R14.1, U9.12 (USBDM)
/Interface/USB_DP: R15.1, U9.11 (USBDP)
GND: C45.1, C46.2, C47.2, C48.1, CR1.2 (A), FL2.2, J3.05, J3.07, R16.2, R17.2, U9.6 (GND), U9.16 (GND); also elsewhere on the board
unnamed: F1.1, FL1.2
unnamed: C47.1, J4.3 (D+), R15.2, R17.1
unnamed: C46.1, J4.2 (D-), R14.2, R16.1
unnamed: FL2.1, J4.5 (GND)
unnamed: C48.2, FL1.1, J4.1 (VCC)
unnamed: LED2.1, R11.1
unnamed: LED3.1, R13.2
unnamed: R13.1, U9.17 (CBUS1)
unnamed: R11.2, U9.10 (CBUS2)
unnamed: R10.2, U9.4 (RXD)
unnamed: R12.1, U9.20 (TXD)
SWI_SWCLK: J3.06; also elsewhere on the board
SWI_SWDIO: J3.04; also elsewhere on the board
SWI_SWO: J3.08; also elsewhere on the board
UC_NRST: J3.12; also elsewhere on the board
USART_RX: R12.2; also elsewhere on the board
USART_TX: R10.1; also elsewhere on the board

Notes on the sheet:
USB Micro-B
USB to UART
SWD Port

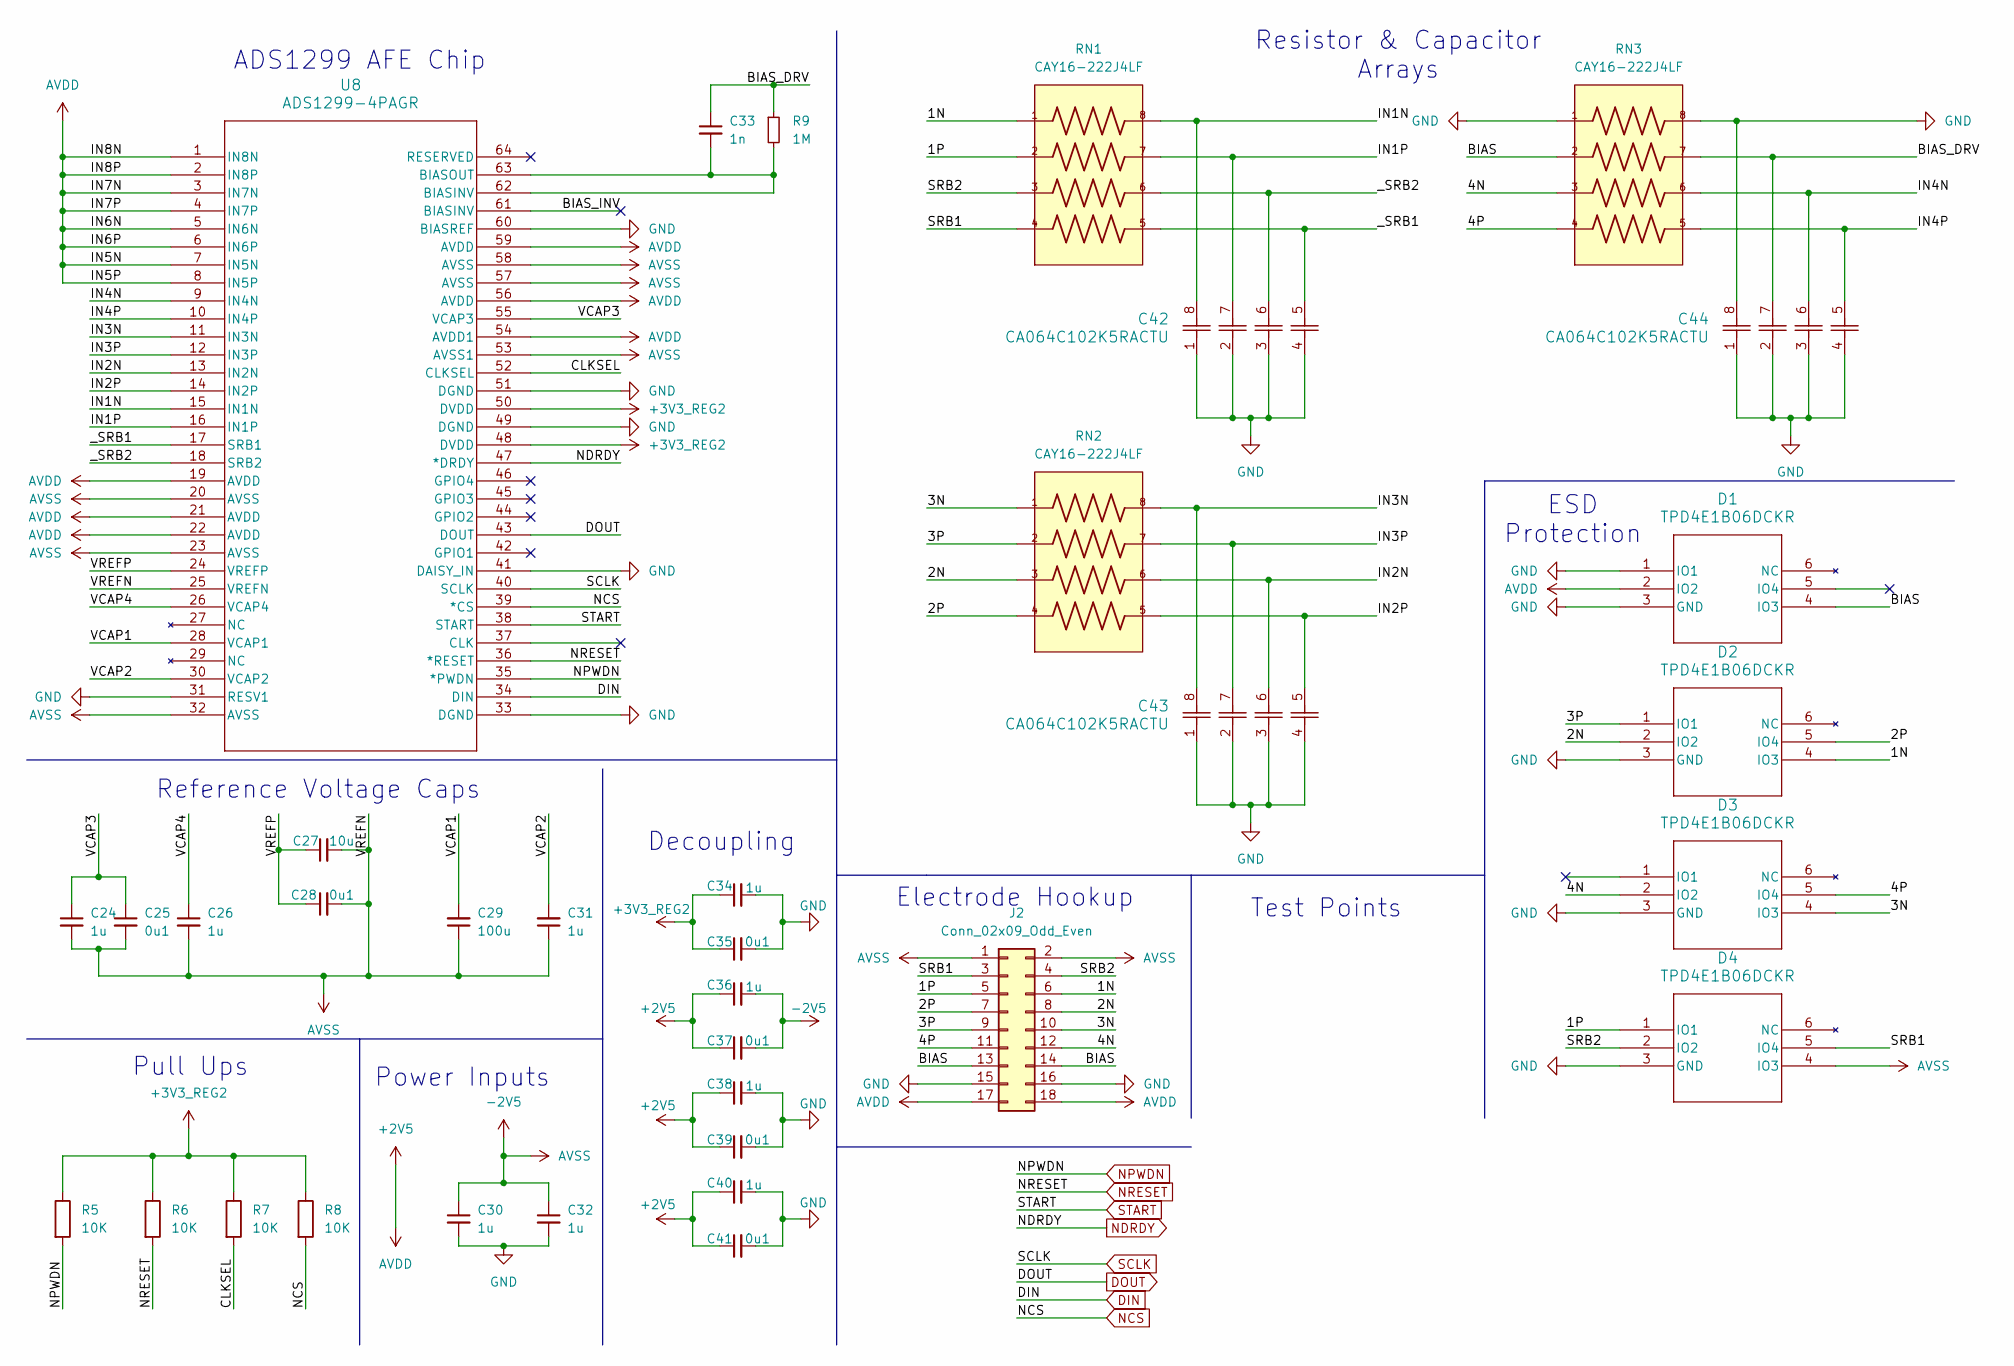
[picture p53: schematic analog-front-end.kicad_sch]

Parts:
C24, C26, C30, C31, C32, C34, C36, C38, C40: 1u; C_0402_1005Metric
C25, C28, C35, C37, C39, C41: 0u1; C_0402_1005Metric
C27: 10u; C_0603_1608Metric
C29: 100u; C_1206_3216Metric
C33: 1n; C_0402_1005Metric
C42, C43, C44: CA064C102K5RACTU; CA064C102K5RAC7800
D1, D2, D3, D4: TPD4E1B06DCKR
J2: Conn_02x09_Odd_Even; PinHeader_2x09_P2.54mm_Horizontal
R5, R6, R7, R8: 10K; R_0402_1005Metric
R9: 1M; R_0402_1005Metric
RN1, RN2, RN3: CAY16-222J4LF
U8: ADS1299-4PAGR

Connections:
+2V5: C36.1, C37.1, C38.1, C39.1, C40.1, C41.1, D1.2 (IO2), J2.17, J2.18, U8.1 (IN8N), U8.2 (IN8P), U8.3 (IN7N), U8.4 (IN7P), U8.5 (IN6N), U8.6 (IN6P), U8.7 (IN5N), U8.8 (IN5P), U8.19 (AVDD), U8.21 (AVDD), U8.22 (AVDD), U8.54 (AVDD1), U8.56 (AVDD), U8.59 (AVDD); also elsewhere on the board
+3V3_REG2: C34.1, C35.1, R5.1, R6.1, R7.1, R8.1, U8.48 (DVDD), U8.50 (DVDD); also elsewhere on the board
-2V5: C24.2, C25.2, C26.2, C27.2, C28.2, C29.1, C30.1, C31.1, C32.1, C36.2, C37.2, D4.4 (IO3), J2.1, J2.2, U8.20 (AVSS), U8.23 (AVSS), U8.25 (VREFN), U8.32 (AVSS), U8.53 (AVSS1), U8.57 (AVSS), U8.58 (AVSS); also elsewhere on the board
/Analog-Front-End/1N: D2.4 (IO3), J2.6, RN1.1
/Analog-Front-End/1P: D4.1 (IO1), J2.5, RN1.2
/Analog-Front-End/2N: D2.2 (IO2), J2.8, RN2.3
/Analog-Front-End/2P: D2.5 (IO4), J2.7, RN2.4
/Analog-Front-End/3N: D3.4 (IO3), J2.10, RN2.1
/Analog-Front-End/3P: D2.1 (IO1), J2.9, RN2.2
/Analog-Front-End/4N: D3.2 (IO2), J2.12, RN3.3
/Analog-Front-End/4P: D3.5 (IO4), J2.11, RN3.4
/Analog-Front-End/BIAS: D1.4 (IO3), J2.13, J2.14, RN3.2
/Analog-Front-End/BIAS_DRV: C33.1, C44.7, R9.1, RN3.7
/Analog-Front-End/BIAS_INV: U8.61 (BIASINV)
/Analog-Front-End/CLKSEL: R7.2, U8.52 (CLKSEL)
/Analog-Front-End/IN1N: C42.8, RN1.8, U8.15 (IN1N)
/Analog-Front-End/IN1P: C42.7, RN1.7, U8.16 (IN1P)
/Analog-Front-End/IN2N: C43.6, RN2.6, U8.13 (IN2N)
/Analog-Front-End/IN2P: C43.5, RN2.5, U8.14 (IN2P)
/Analog-Front-End/IN3N: C43.8, RN2.8, U8.11 (IN3N)
/Analog-Front-End/IN3P: C43.7, RN2.7, U8.12 (IN3P)
/Analog-Front-End/IN4N: C44.6, RN3.6, U8.9 (IN4N)
/Analog-Front-End/IN4P: C44.5, RN3.5, U8.10 (IN4P)
/Analog-Front-End/SRB1: D4.5 (IO4), J2.3, RN1.4
/Analog-Front-End/SRB2: D4.2 (IO2), J2.4, RN1.3
/Analog-Front-End/VCAP1: C29.2, U8.28 (VCAP1)
/Analog-Front-End/VCAP2: C31.2, U8.30 (VCAP2)
/Analog-Front-End/VCAP3: C24.1, C25.1, U8.55 (VCAP3)
/Analog-Front-End/VCAP4: C26.1, U8.26 (VCAP4)
/Analog-Front-End/VREFP: C27.1, C28.1, U8.24 (VREFP)
/Analog-Front-End/_SRB1: C42.5, RN1.5, U8.17 (SRB1)
/Analog-Front-End/_SRB2: C42.6, RN1.6, U8.18 (SRB2)
DIN: U8.34 (DIN); also elsewhere on the board
DOUT: U8.43 (DOUT); also elsewhere on the board
GND: C30.2, C32.2, C34.2, C35.2, C38.2, C39.2, C40.2, C41.2, C42.1, C42.2, C42.3, C42.4, C43.1, C43.2, C43.3, C43.4, C44.1, C44.2, C44.3, C44.4, C44.8, D1.1 (IO1), D1.3 (GND), D2.3 (GND), D3.3 (GND), D4.3 (GND), J2.15, J2.16, RN3.1, RN3.8, U8.31 (RESV1), U8.33 (DGND), U8.41 (DAISY_IN), U8.49 (DGND), U8.51 (DGND), U8.60 (BIASREF); also elsewhere on the board
NCS: R8.2, U8.39 (*CS); also elsewhere on the board
NDRDY: U8.47 (*DRDY); also elsewhere on the board
NPWDN: R5.2, U8.35 (*PWDN); also elsewhere on the board
NRESET: R6.2, U8.36 (*RESET); also elsewhere on the board
unnamed: C33.2, R9.2, U8.62 (BIASINV), U8.63 (BIASOUT)
SCLK: U8.40 (SCLK); also elsewhere on the board
START: U8.38 (START); also elsewhere on the board

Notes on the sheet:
Pull Ups
Decoupling
Reference Voltage Caps
Electrode Hookup
Resistor & Capacitor Arrays
Test Points
ESD Protection
ADS1299 AFE Chip
Power Inputs

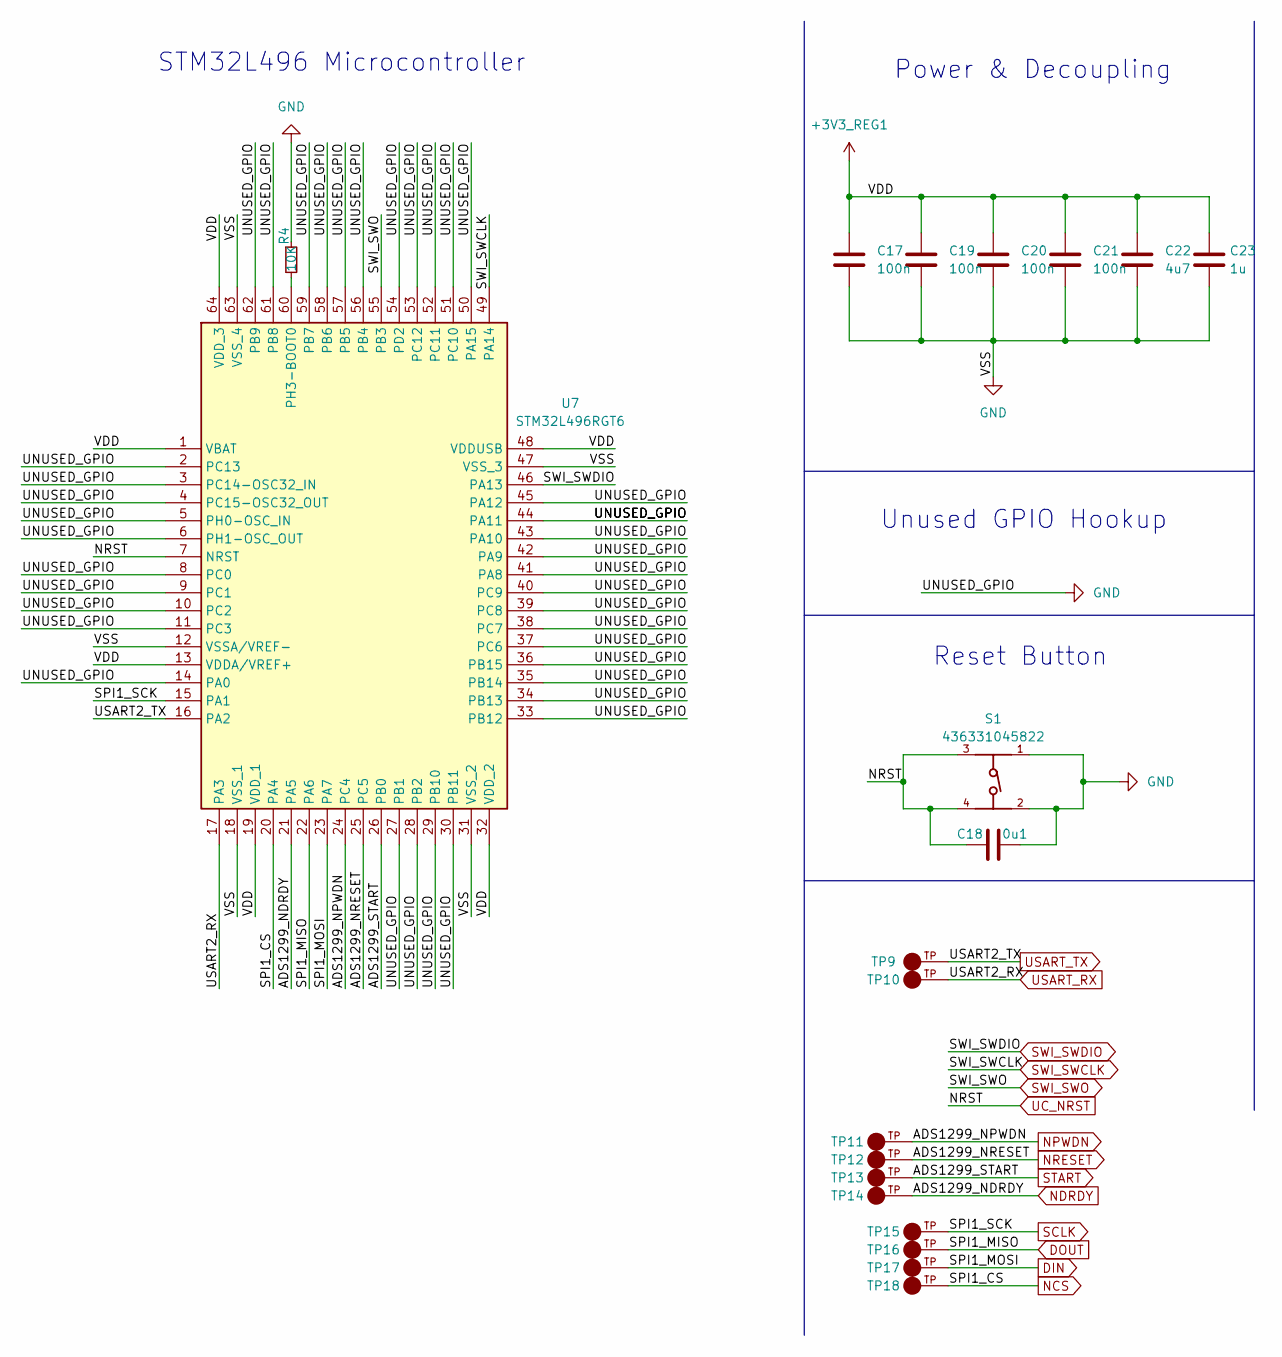
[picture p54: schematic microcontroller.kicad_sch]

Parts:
C17, C19, C20, C21: 100n; C_0603_1608Metric
C18: 0u1; C_0603_1608Metric
C22: 4u7; C_0603_1608Metric
C23: 1u; C_0603_1608Metric
R4: 10K; R_0402_1005Metric
S1: 436331045822
TP9, TP10, TP11, TP12, TP13, TP14, TP15, TP16, TP17, TP18: 5015; PARTREV F
U7: STM32L496RGT6; Manufacturer_Part_Number STM32L496RGT6; Mouser Part Number 511-STM32L496RGT6

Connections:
+3V3_REG1: C17.1, C19.1, C20.1, C21.1, C22.1, C23.1, U7.1 (VBAT), U7.13 (VDDA/VREF+), U7.19 (VDD_1), U7.32 (VDD_2), U7.48 (VDDUSB), U7.64 (VDD_3); also elsewhere on the board
DIN: TP17.TP, U7.23 (PA7); also elsewhere on the board
DOUT: TP16.TP, U7.22 (PA6); also elsewhere on the board
GND: C17.2, C18.1, C19.2, C20.2, C21.2, C22.2, C23.2, R4.1, S1.1, S1.2, U7.2 (PC13), U7.3 (PC14-OSC32_IN), U7.4 (PC15-OSC32_OUT), U7.5 (PH0-OSC_IN), U7.6 (PH1-OSC_OUT), U7.8 (PC0), U7.9 (PC1), U7.10 (PC2), U7.11 (PC3), U7.12 (VSSA/VREF-), U7.14 (PA0), U7.18 (VSS_1), U7.27 (PB1), U7.28 (PB2), U7.29 (PB10), U7.30 (PB11), U7.31 (VSS_2), U7.33 (PB12), U7.34 (PB13), U7.35 (PB14), U7.36 (PB15), U7.37 (PC6), U7.38 (PC7), U7.39 (PC8), U7.40 (PC9), U7.41 (PA8), U7.42 (PA9), U7.43 (PA10), U7.44 (PA11), U7.45 (PA12), U7.47 (VSS_3), U7.50 (PA15), U7.51 (PC10), U7.52 (PC11), U7.53 (PC12), U7.54 (PD2), U7.56 (PB4), U7.57 (PB5), U7.58 (PB6), U7.59 (PB7), U7.61 (PB8), U7.62 (PB9), U7.63 (VSS_4); also elsewhere on the board
NCS: TP18.TP, U7.20 (PA4); also elsewhere on the board
NDRDY: TP14.TP, U7.21 (PA5); also elsewhere on the board
NPWDN: TP11.TP, U7.24 (PC4); also elsewhere on the board
NRESET: TP12.TP, U7.25 (PC5); also elsewhere on the board
unnamed: R4.2, U7.60 (PH3-BOOT0)
SCLK: TP15.TP, U7.15 (PA1); also elsewhere on the board
START: TP13.TP, U7.26 (PB0); also elsewhere on the board
SWI_SWCLK: U7.49 (PA14); also elsewhere on the board
SWI_SWDIO: U7.46 (PA13); also elsewhere on the board
SWI_SWO: U7.55 (PB3); also elsewhere on the board
UC_NRST: C18.2, S1.3, S1.4, U7.7 (NRST); also elsewhere on the board
USART_RX: TP10.TP, U7.17 (PA3); also elsewhere on the board
USART_TX: TP9.TP, U7.16 (PA2); also elsewhere on the board

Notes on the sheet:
STM32L496 Microcontroller
Unused GPIO Hookup
Reset Button
Power & Decoupling

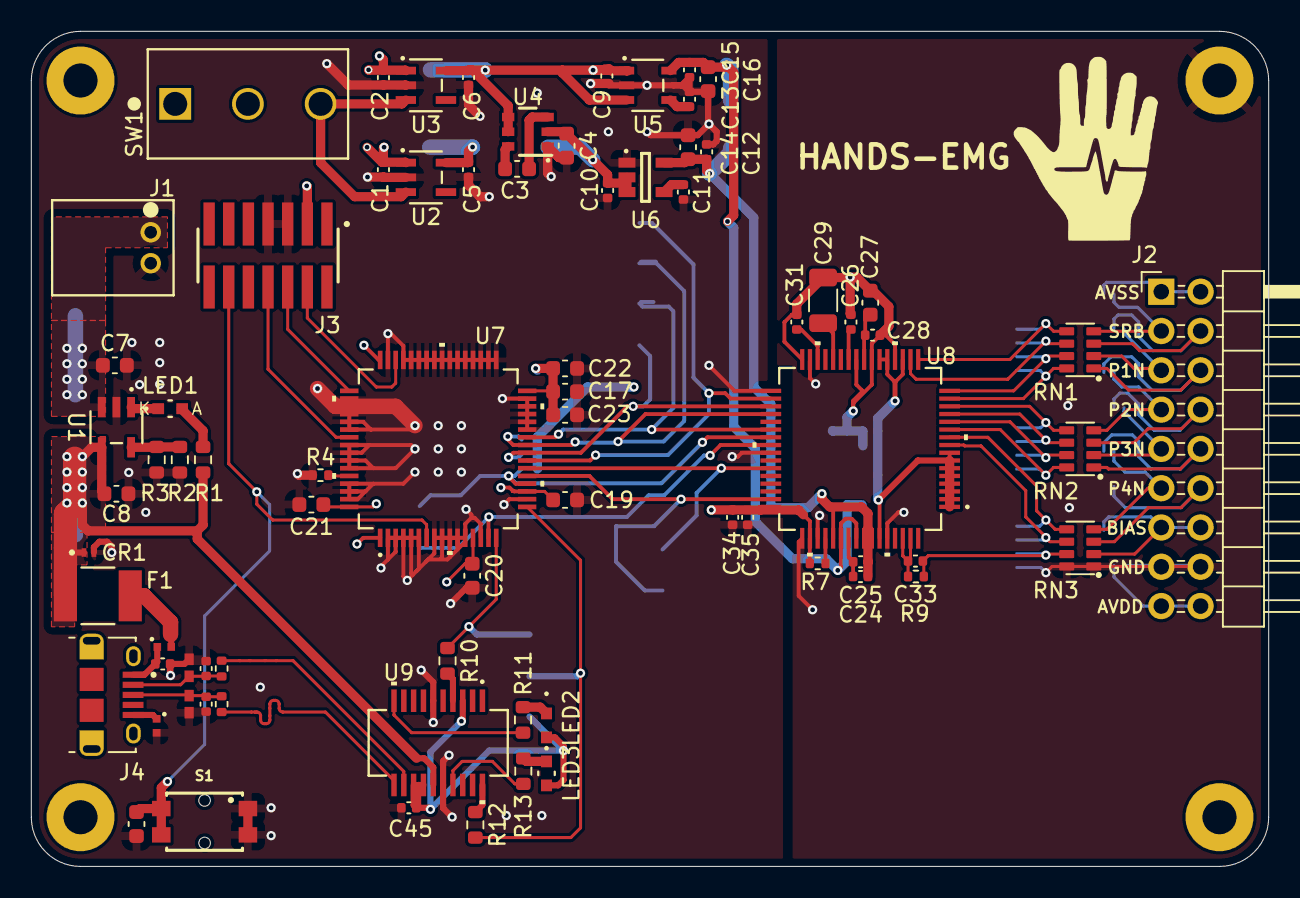
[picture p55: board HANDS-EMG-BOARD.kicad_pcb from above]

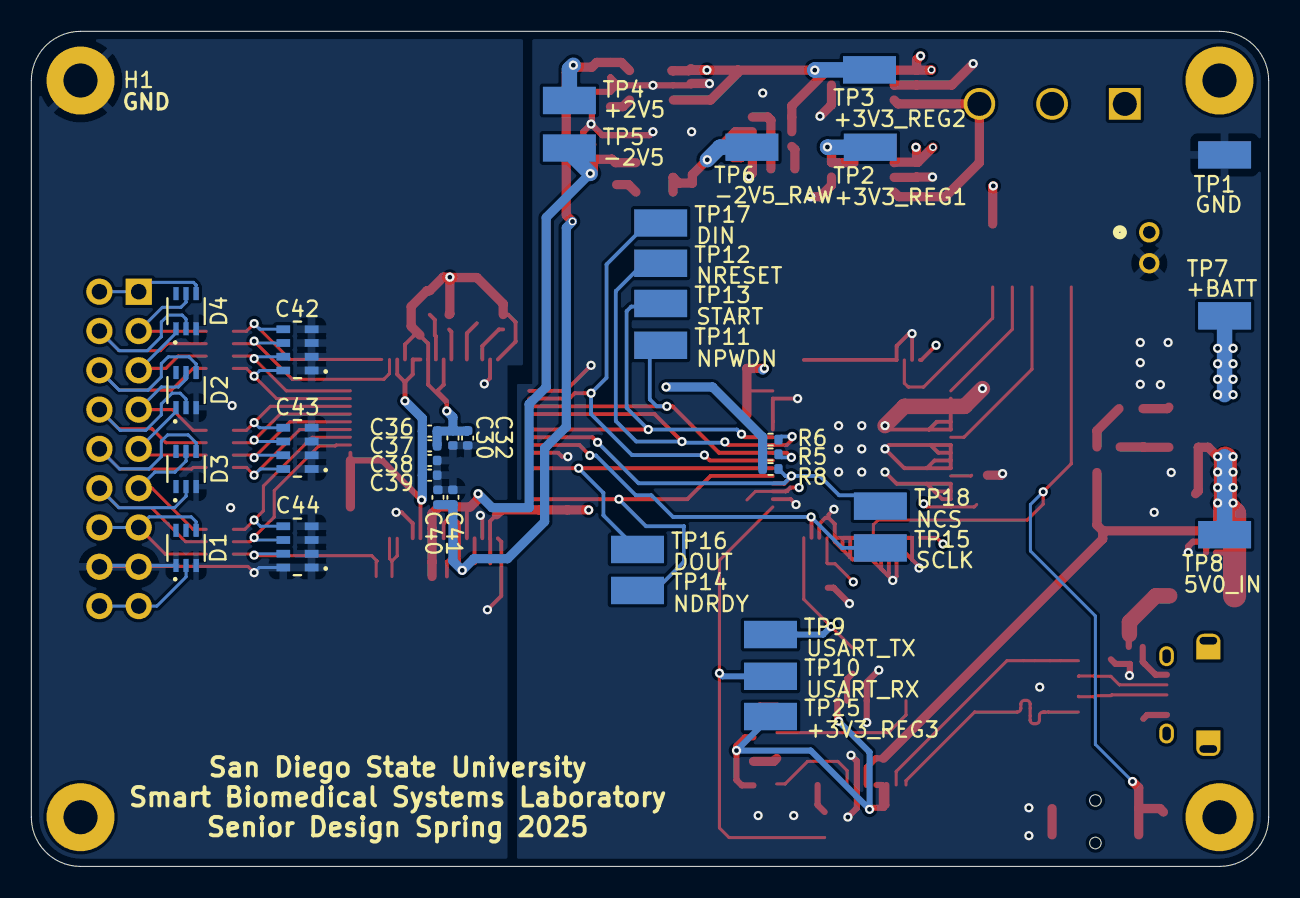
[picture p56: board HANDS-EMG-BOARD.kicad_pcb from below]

Board: 4 copper layers, 80.0 x 54.0 mm, 117 parts (37 on the bottom side), 74 nets.

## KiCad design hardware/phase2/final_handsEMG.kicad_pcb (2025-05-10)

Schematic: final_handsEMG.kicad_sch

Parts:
C1: 10uF; CAPC1608X90N
C2: 100uF; CAP_CC1206_YAG
C3, C9, C11, C26, C34: CKCL44X7R1H102M085AA; CAPCAF50P200X125X85-8; PARTREV Dec 2014
C5, C12, C13, C15, C24, C28: 0.1uF; YAG_CC0402_YAG
C6, C7, C14, C17, C18, C19, C21, C22, C27: 1uF; CAP_CC0402KRX7R5BB105_YAG
C16: 1nF; YAG_CC0402_YAG
C45, C46, C50, C51, C60, C61, C65, C66: 10uF; CAPC2012X95N
C47, C48, C49, C58, C62: 1uF; CAPC1608X90N
C57: 0.1uF; CAPC1608X90N
C59, C63, C64: 2.2uF; CAP_GRM18_MUR
C67: 0.01uF; CAPC1608X90N
D2, D3, D4, D5, D6, D7: TPD4E1B06DCKR; DCK6_TEX
J1: Conn_02x13_Odd_Even; AMPHENOL_68021-226HLF
L1, L2, L4, L5: 3.3uH; INDC2012X87N
R1, R2, R3, R4, R6: 2.2K; CAY16_BRN
R5: 1M; RC0402N_YAG
SWD1: FTSH-107-01-L-DV-K; CON14_2X7_DUK_FTSH_SAI
TP1: RAW; KEYSTONE_5000
TP2: LDO3V3; KEYSTONE_5000
TP4: +3V3; KEYSTONE_5000
TP5: -5V; KEYSTONE_5001
TP6: +5V; KEYSTONE_5001
TP7: +2V5; KEYSTONE_5001
TP8: -2V5; KEYSTONE_5001
U1: ADS1299CPAG; QFP64P50_1200X1200X120L60X22N
U2: STM32L496ZGT6; LQFP144-20x20mm_STM; PARTREV 10
U3: LTC3586EUFE-3-PBF; QFN-38_UFE_LIT
U4: FT231XQ-R; QFN20_FT231XQ_FTD
U6: TPS60403DBVT; SOT95P280X145-5N
U8: TPS72325DBVT; SOT95P280X145-5N
U9: TPS73225DBVT; SOT95P280X145-5N
dC1: 0.01uF; CC0402N_YAG
dC2, dC3: 47pF; G-033_MUR
dD3: D_Small; SOD882_STM
dD4: RED; LED_LTST-C191KRKT_LTO
dD5: GREEN; LED_LTST-C191KGKT_LTO
dF1: Fuse_Small; FUSE_F050-2
dL2: L_Small; IND_1005_TDK
dR1, dR2: 27; RC0402N_YAG
dR3, dR4: 330; RC0402N_YAG
dR6, dR7: 1K; RC0402N_YAG
pC1, pC4, pC5, pC8, pC9, pC11: 1uF; C1005X5R0J105M
pC2: 10uF; GRM21BR61A106KE19
pC3: 10uF; GRM21BR61A106KE19L
pC6, pC7, pC19: 22uF; JMK212BJ226MG-T
pC10: 2.2uF; C1608X5R0J225M
pC12, pC21, pC23: 10uF; C1608X5R0J106M
pC13: 100uF; GRM31CR60J107ME39L
pC14: 47uF; LMK316BJ476ML-T
pC15, pC20, pC22, pC24: 10pF; 04025A100KAT
pC16, pC28, pC29: 0.1uF; C1005X5R1C104K
pC17: 330pF; 04025A331KAT
pC18: 33pF; 04025A330KAT
pD2: GREEN (CHRG); LED-0603
pD3: RED (FAULT); LED-0603
pL1: 3.3uH; LPS4018-332MLC
pL2, pL3: 2.2uH; LPS4018-222MLC
pL4, pL5: 4.7uH; IND_LPS4018-472MRC
pQ1: PMOS; SI2333DS
pR2, pR29, pR30, pR31: 1; CRCW04021R00JNED
pR3, pR9: 100K; CRCW0402100KFKED
pR4, pR10, pR12: 0; CRCW04020000Z0EDC
pR5, pR7: 1K; CRCW04021K00JNED
pR6, pR8: 2.2K; CRCW04022K20FKED
pR13, pR18, pR23, pR26: 20; CRCW040220R0FKED
pR14: 88.7k; CRCW040288K7FKED
pR15: 16.9K; CRCW040216K9FKED
pR16: 3.01K; CRCW04023K01FKED
pR17: 2K; CRCW04022K00FKED
pR19: 15K; CRCW040215K0FKED
pR20: 324K; CRCW0402324KFKED
pR21: 121K; CRCW0402121KFKED
pR22: 105K; CRCW0402105KFKED
pR24: 806K; CRCW0402806KFKED
pR25: 649K; CRCW0402649KFKED
pR27: 232K; CRCW0402232KFKED
pR28: 464K; CRCW0402464KFKED
pR34, pR35, pR80, pR81, pR82, pR83: 10K; CRCW04021K00JNED
sB1: USER; PTS645S_SMTR92_CNK
sB2: RESET; PTS645S_SMTR92_CNK
sC28, sC29, sC30, sC31, sC32, sC33, sC34, sC49, sC50, sC51, sC53, sC57, sC58, sC61: 100nF; CAPC1608X90
sC40: [N/A]; YAG_CC0402_YAG
sC41: 100nF; YAG_CC0402_YAG
sC42: 4.7uF; CAPMP3216X166
sC52, sC54: 4.7uF_X54_0603; CAPC1608X90
sC56, sC59: 1uF; CAPMP3216X166
sC60: 1uF_X5R_0603; CAPC1608X90
sCN14: USB_B_Micro; MOLEX_47589-1001
sD6: ESDALC6V1_1U2; DIODE_ESDALC6V1-1U2
sD10: ESDALC6V1W5; SOT65P210X110-5N; MOUSER_PART_NUMBER 511-ESDALC6V1W5
sJ2: S2B-PH-K-SLFSN; CONN_S2B-PH-K-S_JST
sL3: FerriteBead_Small; FB0603
sLD7: Red; LED-0603
sLD8: Green; LED-0603
sR38, sR52: 10K; RESC1607X60N
sR41, sR43: 330; RESC1607X60N
sR42: 220K; RESC1607X60N
sR44: 100; RESC1607X60N
sR45: 620; RESC1608X55N
sR48: 22K; RESC1607X60N
sR49, sR51: 47K; RESC1608X55
sR54, sR55: 10K (DNP); RESC1607X60N
sT2: 9013; SOT-23
sU12: STMPS2151STR; SOT95P280X145-5N
sU13: USBLC6-2SC6; SOT-23-6

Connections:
1N: D3.4 (IO3), J1.21, R1.1
1P: D2.1 (IO1), J1.22, R1.2
2N: D3.2 (IO2), J1.19, R2.3
2P: D3.5 (IO4), J1.20, R2.4
3N: D4.4 (IO3), J1.17, R2.1
3P: D3.1 (IO1), J1.18, R2.2
3V3OUT: U4.10 (3V3OUT), U4.11 (RESET#), dD4.2 (A), dD5.2 (A)
4N: D4.2 (IO2), J1.15, R3.3
4P: D4.5 (IO4), J1.16, R3.4
5N: D5.4 (IO3), J1.13, R3.1
5P: D4.1 (IO1), J1.14, R3.2
5VCC: C45.1, C46.1, C47.1, C58.1, L1.1, L1.2, TP6.1, U3.6 (VOUT4), U3.7 (VOUT4), U6.2 (IN), U9.1 (IN), U9.3 (EN), pC14.1, pR13.2
6N: D5.2 (IO2), J1.11, R4.3
6P: D5.5 (IO4), J1.12, R4.4
7N: D6.4 (IO3), J1.9, R4.1
7P: D5.1 (IO1), J1.10, R4.2
8N: D6.2 (IO2), J1.7, R6.3
8P: D6.5 (IO4), J1.8, R6.4
*CHRG: U3.30 (*CHRG), pR5.2, pR6.2
*FAULT: U3.38 (*FAULT), pR7.2, pR8.2, pR80.2
-5VCC: C49.1, C50.1, C51.1, C63.1, L2.1, L2.2, TP5.1, U6.1 (OUT), U8.2 (IN), U8.3 (EN)
AVBUS: U3.35 (VBUS), U3.36 (VBUS), dD3.1 (K), dF1.2, pC2.1, pC3.1, pC8.1, pR3.1, sC42.+, sR49.2, sR54.2, sU12.1 (OUT), sU13.5 (VBUS)
AVDD: C13.1, C17.1, C22.1, C24.1, C27.1, C28.1, C57.1, C61.1, D7.2 (IO2), J1.1, J1.2, L5.2, TP7.1, U1.19 (AVDD@1), U1.21 (AVDD@1), U1.22 (AVDD@1), U1.54 (AVDD1), U1.56 (AVDD@1), U1.59 (AVDD@2), U2.32 (VREF+), U2.33 (VDDA), sC56.+, sC57.1, sC58.1, sC59.+, sL3.2
AVIN3: U3.14 (VIN3), pC11.1, pR4.1
AVOUT3: C12.1, C14.1, SWD1.3, TP4.1, U1.48 (DVDD), U1.50 (DVDD), U2.6 (VBAT), U2.17 (VDD), U2.39 (VDD__1), U2.52 (VDD__2), U2.62 (VDD__3), U2.72 (VDD__4), U2.84 (VDD__5), U2.95 (VDDIO2), U2.106 (VDDUSB), U2.108 (VDD__6), U2.121 (VDD__7), U2.131 (VDDIO2__1), U2.144 (VDD__8), U3.16 (VOUT3), U3.17 (VOUT3), U4.12 (VCC), U4.20 (VCCIO), pC19.1, pR18.1, sB1.2, sB1.3, sC28.1, sC29.1, sC30.1, sC31.1, sC32.1, sC33.1, sC34.1, sC49.1, sC50.1, sC51.1, sC52.1, sC53.1, sC54.1, sC60.1, sC61.1, sL3.1, sR41.2, sR44.1, sR45.2, sR51.2, sU12.5 (IN)
AVSS: C1.2, C2.2, C5.2, C6.2, C7.2, C13.2, C15.2, C17.2, C18.1, C19.2, C21.1, C57.2, C66.1, D2.4 (IO3), J1.25, J1.26, L4.2, TP8.1, U1.20 (AVSS@1), U1.23 (AVSS@1), U1.25 (VREFN), U1.32 (AVSS@1), U1.53 (AVSS1), U1.57 (AVSS@1), U1.58 (AVSS@2)
BAT: TP1.1, U3.32 (BAT), pC13.1, pQ1.1 (D), sJ2.1; also elsewhere on the board
BIAS: D7.4 (IO3), J1.5, J1.6, R6.1
BIASIN: C16.2, R5.2, U1.62 (BIASIN), U1.63 (BIASOUT)
BIASINV: U1.61 (BIASINV)
BIASREF: U1.60 (BIASREF)
BIAS_DRV: C16.1, C34.5, R5.1, R6.8
CBUS1: U4.14 (CBUS1), dR4.2
CBUS2: U4.7 (CBUS2), dR3.1
CLK: U1.37 (CLK)
CLKSEL: U1.52 (CLKSEL)
CLPROG: U3.4 (CLPROG), pC16.1, pR16.1
DAISY_IN: U1.41 (DAISY_IN)
DGND: C45.2, C46.2, C47.2, C49.2, C50.2, C51.2, C58.2, C59.2, C60.2, C61.2, C62.2, C63.2, C64.2, C65.2, C66.2, C67.2, SWD1.5, SWD1.7, U1.33 (DGND), U1.49 (DGND), U1.51 (DGND), U2.16 (VSS), U2.30 (VSSA/VREF-), U2.31 (VREF-), U2.38 (VSS__1), U2.51 (VSS__2), U2.61 (VSS__3), U2.71 (VSS__4), U2.83 (VSS__5), U2.94 (VSS__6), U2.107 (VSS__7), U2.120 (VSS__8), U2.130 (VSS__9), U2.143 (VSS__10), U3.39 (EPAD), U4.3 (GND), U4.13 (GND), U4.21 (GND), U6.4 (GND), U8.1 (GND), U9.2 (GND), dC1.2, dC2.2, dC3.2, dD3.2 (A), pC1.2, pC3.2, pC4.2, pC5.2, pC6.2, pC7.2, pC8.2, pC9.2, pC10.2, pC11.2, pC12.2, pC14.2, pC16.2, pC19.2, pC21.1, pC23.1, pC28.2, pC29.2, pR2.2, pR9.1, pR15.1, pR16.2, pR17.2, pR22.2, pR25.2, pR28.2, pR29.1, pR30.1, pR31.1, sB2.2, sB2.3, sC28.2, sC29.2, sC30.2, sC31.2, sC32.2, sC33.2, sC34.2, sC41.2, sC42.-, sC49.2, sC50.2, sC51.2, sC52.2, sC53.2, sC54.2, sC56.-, sC57.2, sC58.2, sC59.-, sC60.2, sC61.2, sCN14.5 (GND), sD6.2 (A), sD10.2 (GND), sJ2.2, sR38.2, sR42.1, sR48.1, sR52.2, sT2.2 (E), sU12.2 (GND), sU13.2 (GND); also elsewhere on the board
DIN: U1.34 (DIN), U2.43 (PA7)
DOUT: U1.43 (DOUT), U2.42 (PA6)
EN1: U2.115 (PD1), U3.21 (EN1)
EN2: U2.116 (PD2), U3.20 (EN2)
EN3: U2.117 (PD3), U3.18 (EN3), pC28.1, pR34.1
EN4: U2.118 (PD4), U3.33 (EN4), pC29.1, pR35.1
FB1: U3.28 (FB1), pC24.1, pR27.2, pR28.1
FB2: U3.23 (FB2), pC22.1, pR24.2, pR25.1
FB3: U3.11 (FB3), pC20.2, pR19.2, pR20.2, pR21.2, pR22.1
FB4: U3.10 (FB4), pC15.2, pR14.1, pR15.2
GATE: U3.31 (GATE), pQ1.2 (G)
GNDA: C3.1, C3.2, C3.3, C3.4, C9.1, C9.2, C9.3, C9.4, C11.1, C11.2, C11.3, C11.4, C12.2, C14.2, C18.2, C21.2, C22.2, C24.2, C26.1, C26.2, C26.3, C26.4, C27.2, C28.2, C34.1, C34.2, C34.3, C34.4, C34.6, D2.3 (GND), D3.3 (GND), D4.3 (GND), D5.3 (GND), D6.3 (GND), D7.1 (IO1), D7.3 (GND), J1.3, J1.4, R6.2, R6.7
GPIO1: U1.42 (GPIO1)
GPIO2: U1.44 (GPIO2)
GPIO3: U1.45 (GPIO3)
GPIO4: U1.46 (GPIO4)
ILIM0: U3.1 (ILIM0), pR81.2
ILIM1: U3.2 (ILIM1), pR82.2
IN1N: C3.5, R1.8, U1.15 (IN1N)
IN1P: C3.6, R1.7, U1.16 (IN1P)
IN2N: C9.7, R2.6, U1.13 (IN2N)
IN2P: C9.8, R2.5, U1.14 (IN2P)
IN3N: C9.5, R2.8, U1.11 (IN3N)
IN3P: C9.6, R2.7, U1.12 (IN3P)
IN4N: C11.7, R3.6, U1.9 (IN4N)
IN4P: C11.8, R3.5, U1.10 (IN4P)
IN5N: C11.5, R3.8, U1.7 (IN5N)
IN5P: C11.6, R3.7, U1.8 (IN5P)
IN6N: C26.7, R4.6, U1.5 (IN6N)
IN6P: C26.8, R4.5, U1.6 (IN6P)
IN7N: C26.5, R4.8, U1.3 (IN7N)
IN7P: C26.6, R4.7, U1.4 (IN7P)
IN8N: C34.7, R6.6, U1.1 (IN8N)
IN8P: C34.8, R6.5, U1.2 (IN8P)
LDO3V3: TP2.1, U3.3 (LDO3V3), pC1.1, pD2.+ (A), pD3.+ (A), pR6.1, pR8.1, pR12.2, pR34.2, pR35.2
MODE: U3.9 (MODE), pR83.2
NRST: SWD1.12, U2.25 (~NRST), sB2.1, sB2.4, sC41.1, sD10.3 (I/02)
NTC: U3.5 (NTC), pR3.2, pR10.2
unnamed: U2.138 (PH3-BOOT0), sR38.1
unnamed: U4.1 (RXD), dR6.2
unnamed: U4.17 (TXD), dR7.2
unnamed: C48.1, U6.5 (CFLY+)
unnamed: C48.2, U6.3 (CFLY-)
unnamed: C67.1, U8.4 (NR)
unnamed: C64.1, C65.1, L4.1, U8.5 (OUT)
unnamed: C62.1, U9.4 (NR/FB)
unnamed: C59.1, C60.1, L5.1, U9.5 (OUT)
unnamed: dD4.1 (K), dR3.2
unnamed: dD5.1 (K), dR4.1
unnamed: dF1.1, dL2.2
unnamed: pC2.2, pR2.1
unnamed: pC13.2, pR29.2, pR30.2, pR31.2
unnamed: pC15.1, pR13.1, pR14.2
unnamed: pC17.2, pR19.1
unnamed: pC18.1, pR18.2, pR20.1
unnamed: pC18.2, pR21.1
unnamed: pC22.2, pR23.2, pR24.1
unnamed: pC24.2, pR26.2, pR27.1
unnamed: pD2.- (K), pR5.1
unnamed: pD3.- (K), pR7.1
unnamed: pR9.2, pR10.1
unnamed: sB1.1, sB1.4, sC40.1, sR42.2, sR43.2
unnamed: sC40.2, sR44.2
unnamed: dC3.1, dR1.1, sCN14.3 (D+)
unnamed: dC2.1, dR2.1, sCN14.2 (D-)
unnamed: dC1.1, dL2.1, sCN14.1 (VBUS)
unnamed: sLD7.+ (A), sR45.1
unnamed: sLD7.- (K), sR51.1, sU12.3 (FAULT)
unnamed: sLD8.+ (A), sR41.1
unnamed: sLD8.- (K), sT2.3 (C)
unnamed: sR48.2, sR49.1, sT2.1 (B)
unnamed: sR52.1, sU12.4 (EN)
PA1: U1.40 (SCLK), U2.35 (PA1)
PA4: U1.39 (~CS), U2.40 (PA4)
PA5: U1.47 (~DRDY), U2.41 (PA5)
PA8: U2.100 (PA8)
PA9: U2.101 (PA9), sR54.1
PA10: U2.102 (PA10), sR55.1
PA11: U2.103 (PA11)
PA12: U2.104 (PA12)
PA13: SWD1.4, U2.105 (PA13(JTMS/SWDIO)), sD10.4 (I/03)
PA14: SWD1.6, U2.109 (PA14(JTCK/SWCLK)), sD10.5 (I/04)
PB0: U1.38 (START), U2.46 (PB0)
PB3: SWD1.8, U2.133 (PB3(JTDO/TRACESWO)), sD10.1 (I/01)
PB7: U2.137 (PB7)
PB12: U2.73 (PB12)
PB13: U2.74 (PB13)
PB14: U2.75 (PB14)
PB15: U2.76 (PB15)
PC4: U1.35 (~PWDN), U2.44 (PC4)
PC5: U1.36 (~RESET), U2.45 (PC5)
PC7: U2.97 (PC7)
PC10: U2.111 (PC10), pR83.1
PC11: U2.112 (PC11), pR82.1
PC12: U2.113 (PC12), pR81.1
PC13: U2.7 (PC13), sR43.1
PD0: U2.114 (PD0), pR80.1
PD5: U2.119 (PD5), dR6.1
PD6: U2.122 (PD6), dR7.1
PD8: U2.77 (PD8)
PD9: U2.78 (PD9)
PD10: U2.79 (PD10)
PD11: U2.80 (PD11)
PD12: U2.81 (PD12)
PD13: U2.82 (PD13)
PG13: U2.128 (PG13)
PG14: U2.129 (PG14)
PROG: U3.29 (PROG), pR17.1
PVIN3: U3.15 (VIN3), U3.22 (VIN4), U3.24 (VIN2), U3.27 (VIN1), U3.34 (VOUT), pC4.1, pC5.1, pC6.1, pC7.1, pC9.1, pC10.1, pC12.1, pL1.2, pL2.2, pQ1.3 (S), pR4.2, pR12.1
RESERVED: U1.64 (RESERVED)
RESV1: U1.31 (RESV1)
SRB1: D2.5 (IO4), J1.24, R1.4
SRB2: D2.2 (IO2), J1.23, R1.3
SW: U3.37 (SW), pL1.1
SW1: U3.26 (SW1), pL5.1
SW2: U3.25 (SW2), pL4.1
SW4: U3.8 (SW4), pL2.1
SWAB3: U3.13 (SWAB3), pL3.2
SWCD3: U3.19 (SWCD3), pL3.1
USB_DN: U4.9 (USBDM), dR2.2, sU13.1 (I/O1), sU13.6 (I/O1)
USB_DP: U4.8 (USBDP), dR1.2, sU13.3 (I/O2), sU13.4 (I/O2)
USB_ID: sCN14.4 (ID), sD6.1 (K), sR55.2
VC3: U3.12 (VC3), pC17.1, pC20.1
VCAP1: C2.1, U1.28 (VCAP1)
VCAP2: C7.1, U1.30 (VCAP2)
VCAP3: C15.1, C19.1, U1.55 (VCAP3)
VCAP4: C6.1, U1.26 (VCAP4)
VOUT1: pC23.2, pL5.2, pR26.1
VOUT2: pC21.2, pL4.2, pR23.1
VREFP: C1.1, C5.1, U1.24 (VREFP)
_SRB1: C3.8, R1.5, U1.17 (SRB1)
_SRB2: C3.7, R1.6, U1.18 (SRB2)

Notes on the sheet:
ADS1299
FT231XQ-R
LTC3586
STM32L496ZGT6

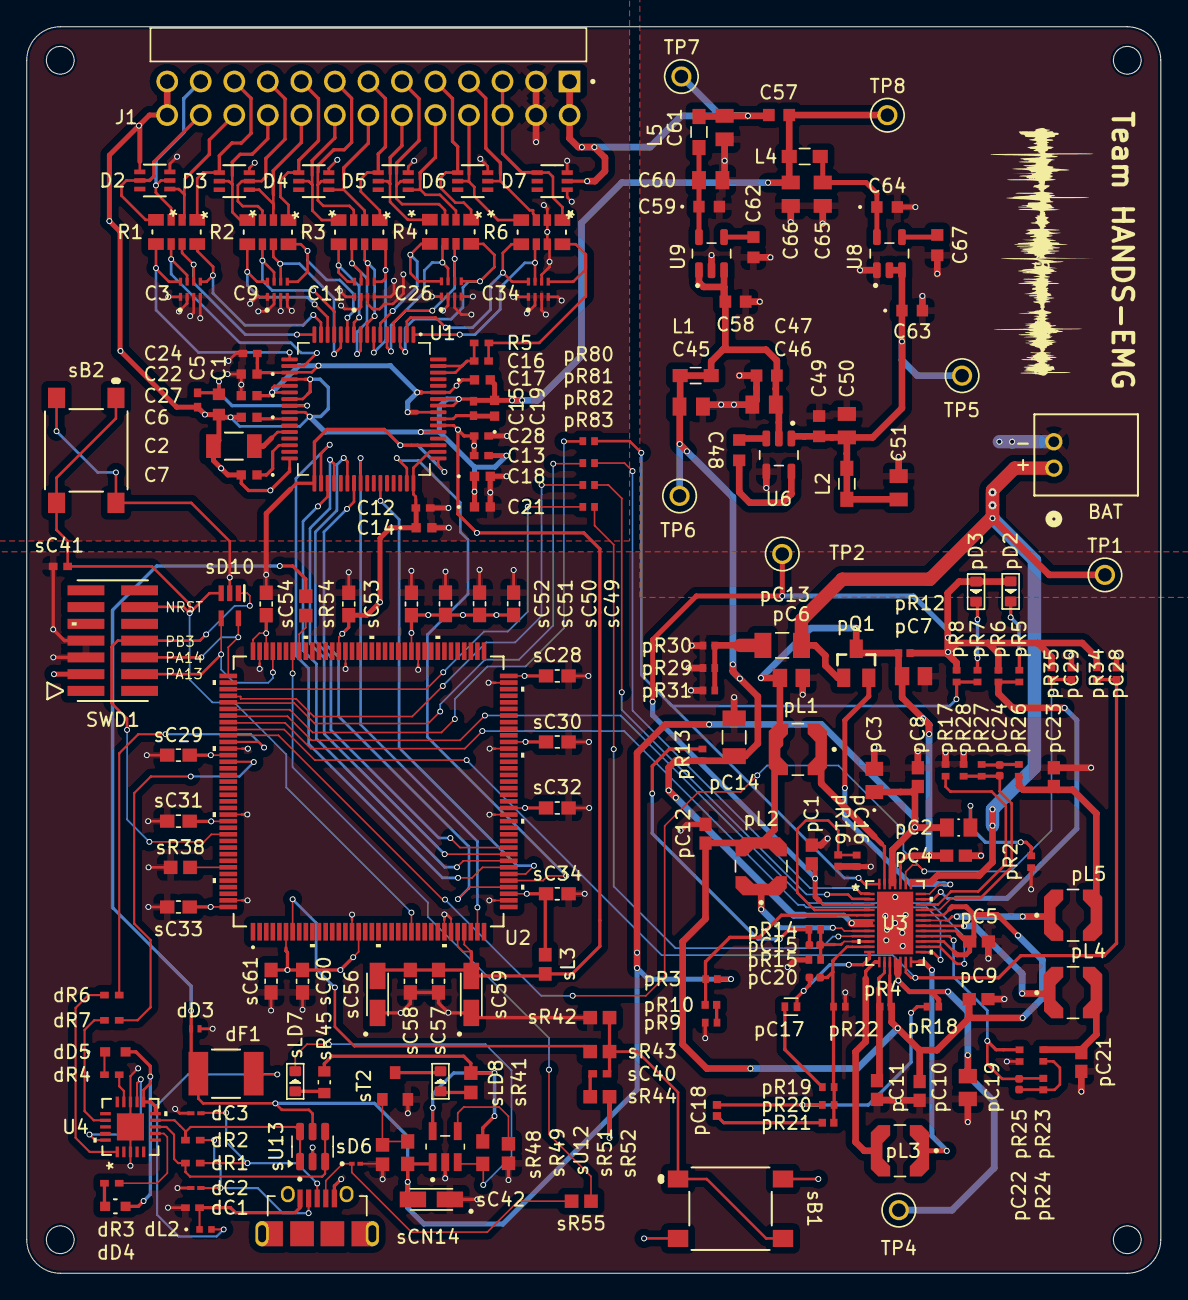
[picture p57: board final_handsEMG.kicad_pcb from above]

Board: 4 copper layers, 85.9 x 94.4 mm, 202 parts (0 on the bottom side), 143 nets.

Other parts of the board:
BAT: S2B-PH-K-SLFSN; CONN_S2B-PH-K-S_JST

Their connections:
BAT: BAT.1; also elsewhere on the board
DGND: BAT.2; also elsewhere on the board

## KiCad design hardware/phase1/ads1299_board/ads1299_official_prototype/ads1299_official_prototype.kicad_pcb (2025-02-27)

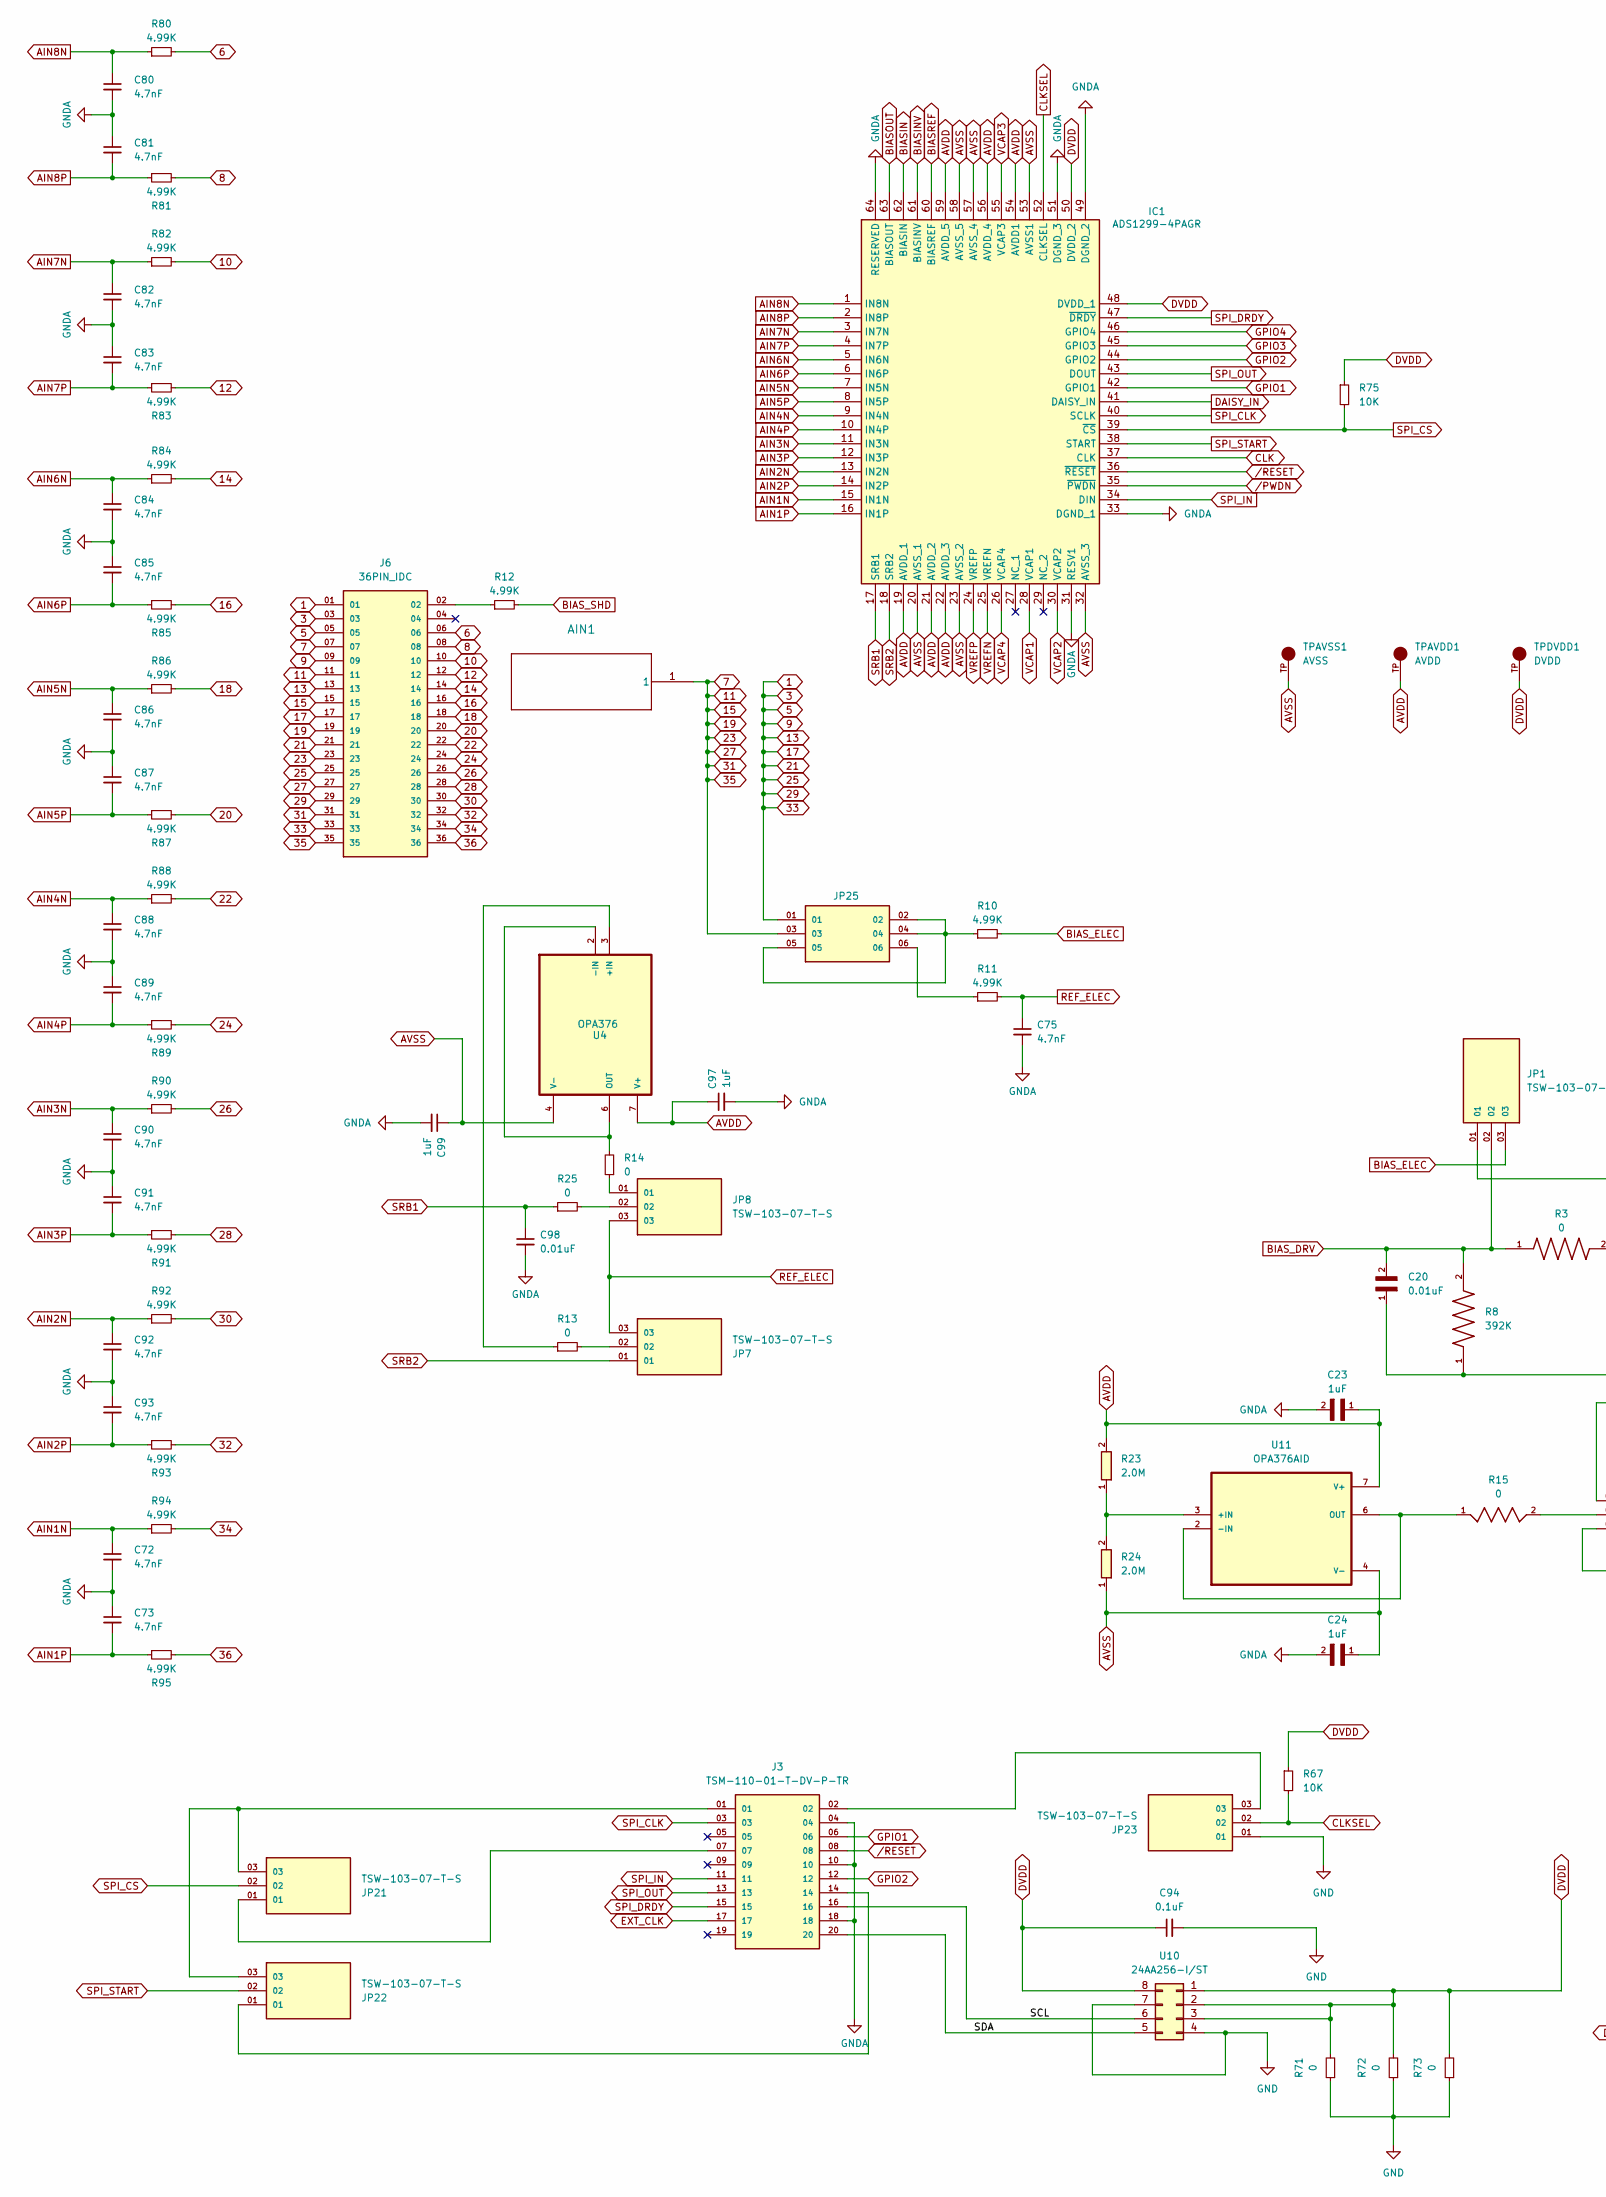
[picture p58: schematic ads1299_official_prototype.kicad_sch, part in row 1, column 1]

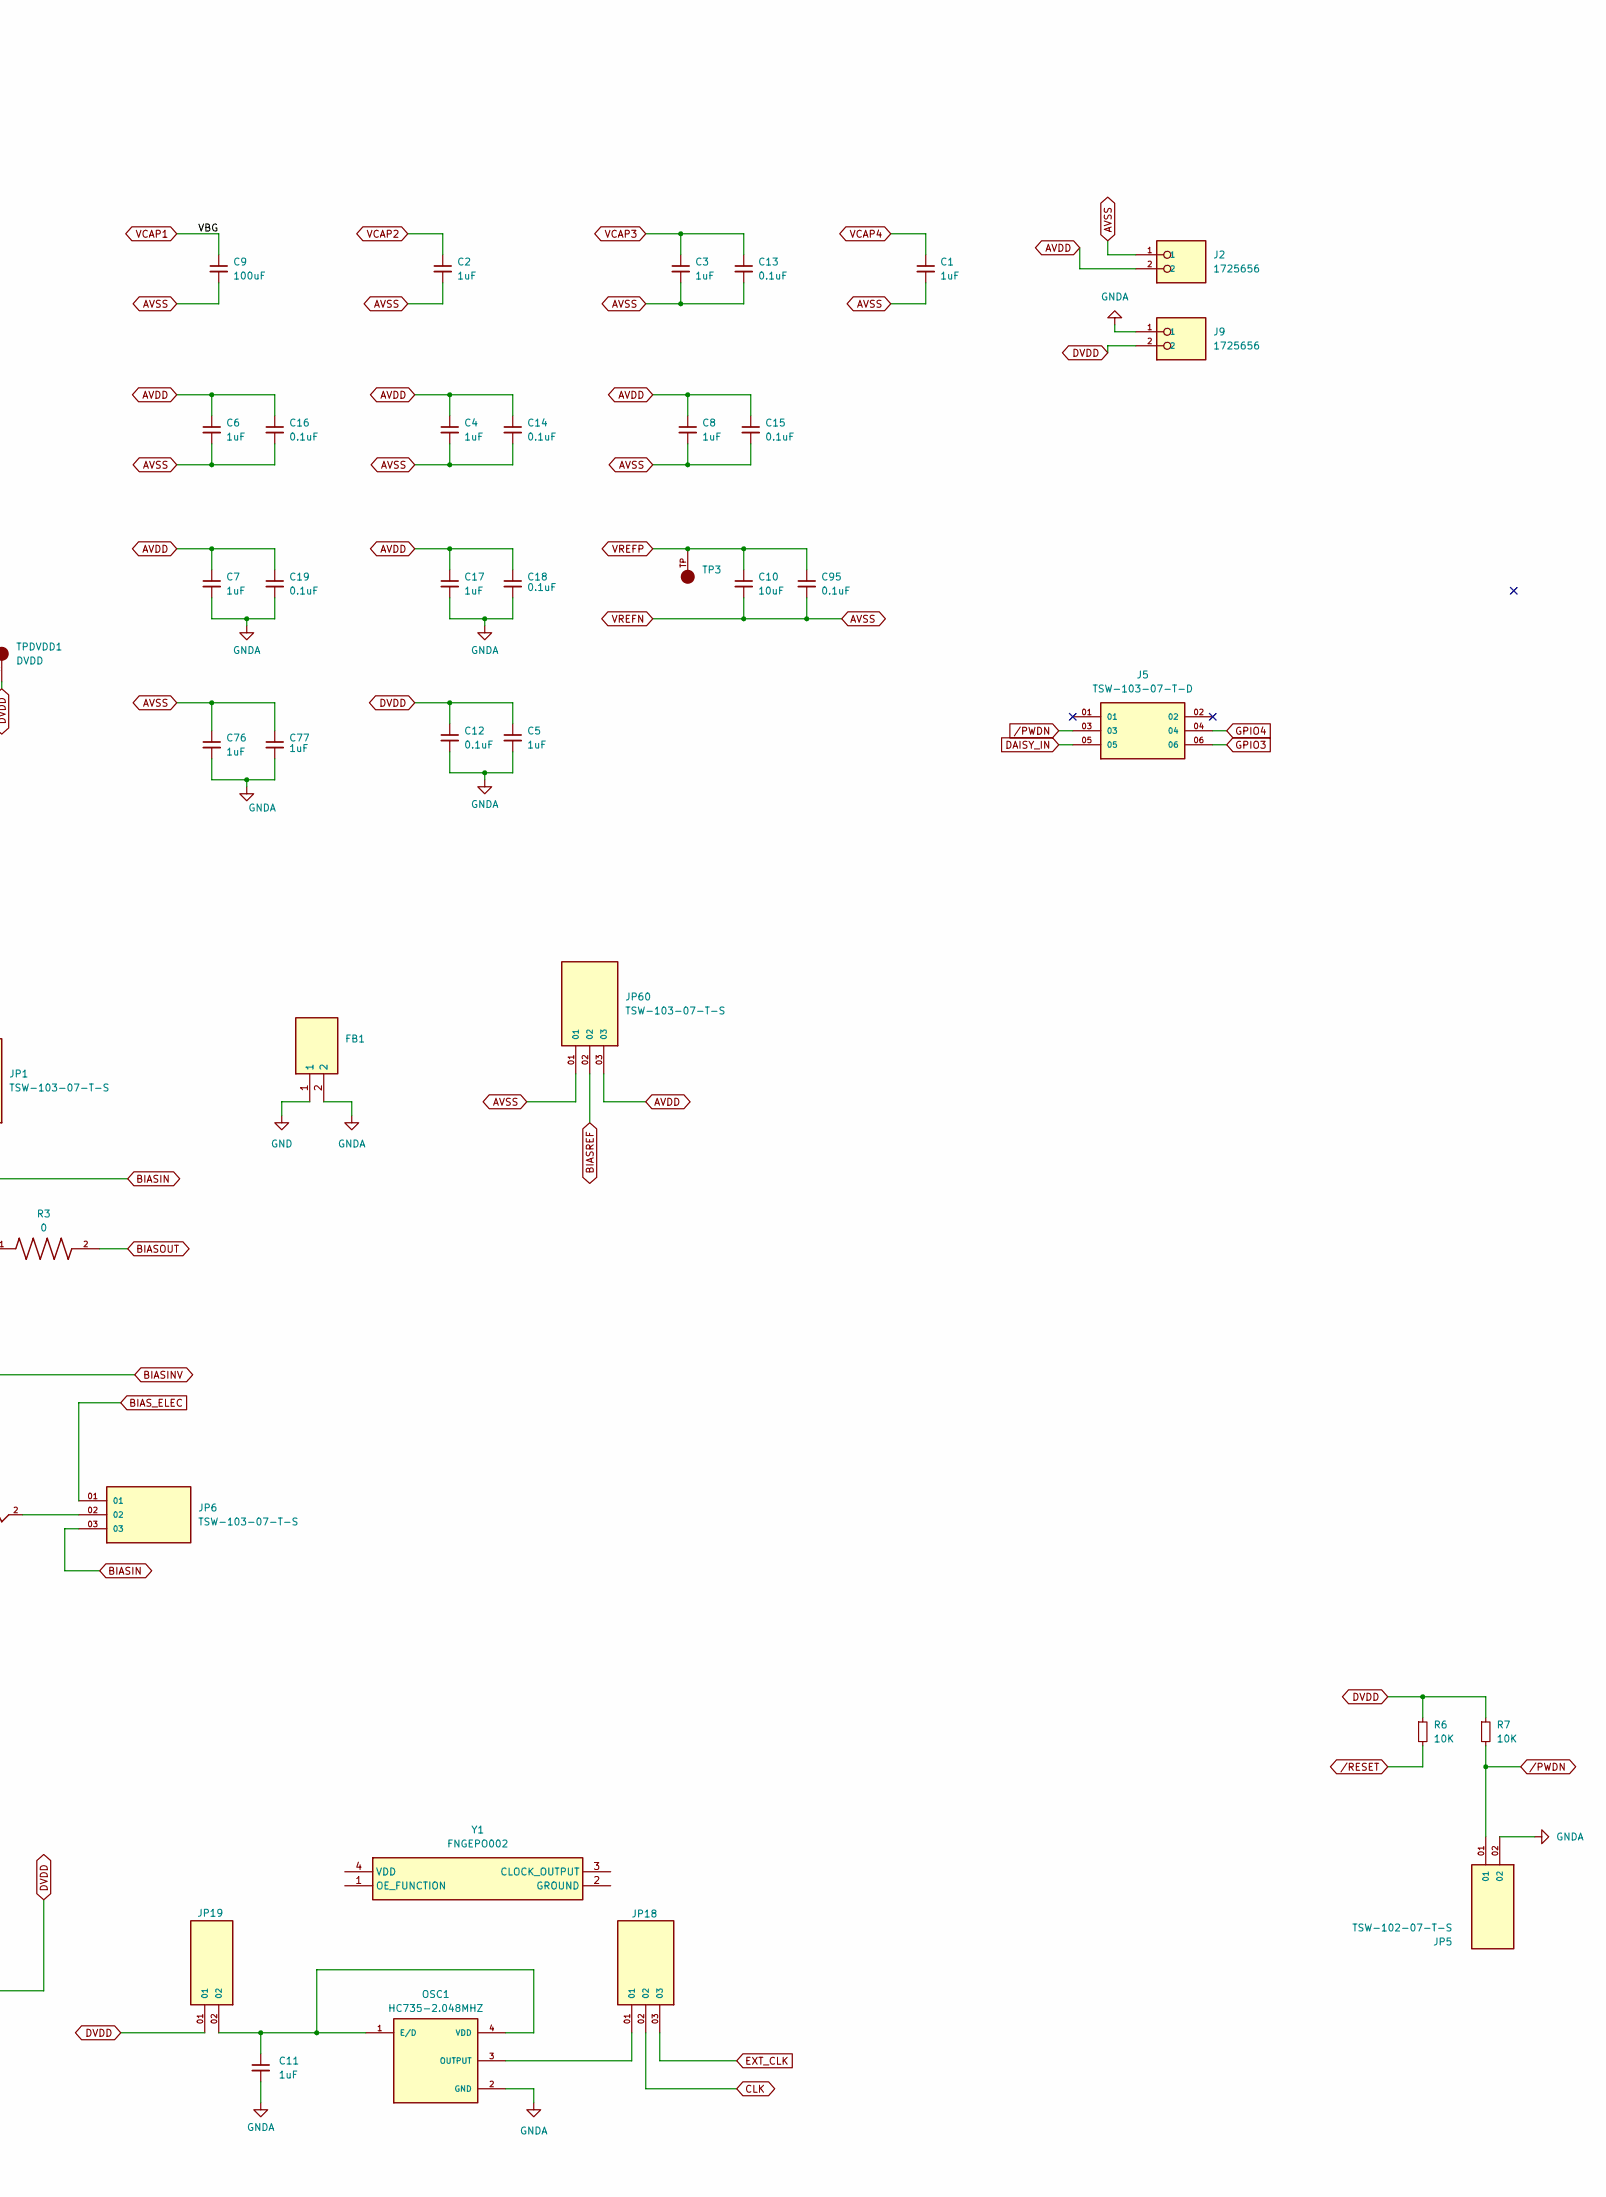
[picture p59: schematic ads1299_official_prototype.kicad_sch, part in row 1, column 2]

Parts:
AIN1: AIN1; 132134_AMP
C1, C2, C3, C4, C5, C6, C7, C8, C11, C17, C23, C24, C76, C77, C97, C99: 1uF; CAPC1608X90N
C9: 100uF; CAPC3225X280N
C10: 10uF; CAPC2012X95N
C12, C13, C14, C15, C16, C18, C19, C94, C95: 0.1uF; CAPC1608X90N
C20, C98: 0.01uF; CAPC1608X90N
C72, C73, C75, C80, C81, C82, C83, C84, C85, C86, C87, C88, C89, C90, C91, C92, C93: 4.7nF; CAPC1608X90N
FB1: FCM_1608KF-601T03; BEADC1608X95N; Manufacturer_Part_Number FCM 1608KF-601T03
IC1: ADS1299-4PAGR; QFP50P1200X1200X120-64N; Manufacturer_Part_Number ADS1299-4PAGR; Mouser Part Number 595-ADS1299-4PAGR
J2, J9: 1725656; PHOENIX_1725656; PARTREV 03.03.2021
J3: TSM-110-01-T-DV-P-TR; SAMTEC_TSM-110-01-T-DV-P-TR
J5: TSW-103-07-T-D; SAMTEC_TSW-103-07-T-D; PARTREV R
J6: 36PIN_IDC; SAMTEC_SSW-118-21-F-D; PARTREV R
JP1, JP6, JP7, JP8, JP18, JP21, JP22, JP23, JP60: TSW-103-07-T-S; SAMTEC_TSW-103-07-T-S; PARTREV R
JP5, JP19: TSW-102-07-T-S; SAMTEC_TSW-102-07-T-S; PARTREV R
JP25: TSW-103-07-T-D; SAMTEC_TSW-103-07-T-D; PARTREV R
OSC1: HC735-2.048MHZ; XTAL_FXO-HC735-8; PARTREV 11/28/2007
R3, R25: 0; RESC1607X60N
R6, R7, R67, R75: 10K; RESC1607X60N
R8: 392K; RESC1608X55N
R10, R11, R12, R80, R81, R82, R83, R84, R85, R86, R87, R88, R89, R90, R91, R92, R93, R94, R95: 4.99K; RESC1608X60N
R13, R14, R15, R71, R72, R73: 0; RESC1005X40
R23, R24: 2.0M; 0603
TP3: 5000; KEYSTONE_5000; PARTREV H
TPAVDD1: AVDD; KEYSTONE_5000; PARTREV H
TPAVSS1: AVSS; KEYSTONE_5000; PARTREV H
TPDVDD1: DVDD; KEYSTONE_5000; PARTREV H
U4: OPA376; SOIC127P599X175-8N
U10: 24AA256-I/ST; SOP8P65_300X640X120L60X24N
U11: OPA376AID; SOIC127P599X175-8N
Y1: FNGEPO002; Manufacturer_Part_Number FNGEPO002; Mouser Part Number 729-FNGEPO002

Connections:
1: J6.01, J6.03, J6.05, J6.09, J6.13, J6.17, J6.21, J6.25, J6.29, J6.33, JP25.01
6: J6.06, R80.2
8: J6.08, R81.2
10: J6.10, R82.2
11: AIN1.1, J6.07, J6.11, J6.15, J6.19, J6.23, J6.27, J6.31, J6.35, JP25.03
12: J6.12, R83.2
14: J6.14, R84.2
16: J6.16, R85.2
18: J6.18, R86.2
20: J6.20, R87.2
22: J6.22, R88.2
24: J6.24, R89.2
26: J6.26, R90.2
28: J6.28, R91.2
30: J6.30, R92.2
32: J6.32, R93.2
34: J6.34, R94.2
36: J6.36, R95.2
/SCL: J3.16, U10.6
/SDA: J3.20, U10.5
AIN1N: C72.1, IC1.15 (IN1N), R94.1
AIN1P: C73.2, IC1.16 (IN1P), R95.1
AIN2N: C92.1, IC1.13 (IN2N), R92.1
AIN2P: C93.2, IC1.14 (IN2P), R93.1
AIN3N: C90.1, IC1.11 (IN3N), R90.1
AIN3P: C91.2, IC1.12 (IN3P), R91.1
AIN4N: C88.1, IC1.9 (IN4N), R88.1
AIN4P: C89.2, IC1.10 (IN4P), R89.1
AIN5N: C86.1, IC1.7 (IN5N), R86.1
AIN5P: C87.2, IC1.8 (IN5P), R87.1
AIN6N: C84.1, IC1.5 (IN6N), R84.1
AIN6P: C85.2, IC1.6 (IN6P), R85.1
AIN7N: C82.1, IC1.3 (IN7N), R82.1
AIN7P: C83.2, IC1.4 (IN7P), R83.1
AIN8N: C80.1, IC1.1 (IN8N), R80.1
AIN8P: C81.2, IC1.2 (IN8P), R81.1
AVDD: C4.1, C6.1, C7.1, C8.1, C14.1, C15.1, C16.1, C17.1, C18.1, C19.1, C23.1, C97.1, IC1.19 (AVDD_1), IC1.21 (AVDD_2), IC1.22 (AVDD_3), IC1.54 (AVDD1), IC1.56 (AVDD_4), IC1.59 (AVDD_5), J2.2, JP60.03, R23.2, TPAVDD1.TP, U4.7 (V+), U11.7 (V+)
AVSS: C1.2, C2.2, C3.2, C4.2, C6.2, C8.2, C9.2, C10.2, C13.2, C14.2, C15.2, C16.2, C24.1, C76.1, C77.1, C95.2, C99.1, IC1.20 (AVSS_1), IC1.23 (AVSS_2), IC1.25 (VREFN), IC1.32 (AVSS_3), IC1.53 (AVSS1), IC1.57 (AVSS_4), IC1.58 (AVSS_5), J2.1, JP60.01, R24.1, TPAVSS1.TP, U4.4 (V-), U11.4 (V-)
BIASIN: IC1.62 (BIASIN), JP1.01, JP6.03
BIASINV: C20.1, IC1.61 (BIASINV), R8.1
BIASOUT: IC1.63 (BIASOUT), R3.2
BIASREF: IC1.60 (BIASREF), JP60.02
BIAS_DRV: C20.2, JP1.02, R3.1, R8.2
BIAS_ELEC: JP1.03, JP6.01, R10.2
BIAS_SHD: R12.2
CLK: IC1.37 (CLK), JP18.02
CLKSEL: IC1.52 (CLKSEL), JP23.02, R67.2
DAISY_IN: IC1.41 (DAISY_IN), J5.05
DVDD: C5.1, C12.1, C94.1, IC1.48 (DVDD_1), IC1.50 (DVDD_2), J9.2, JP19.01, R6.1, R7.1, R67.1, R71.2, R72.2, R73.2, R75.1, TPDVDD1.TP, U10.1, U10.2, U10.3, U10.8
EXT_CLK: J3.17, JP18.03
GND: C94.2, FB1.1, JP23.01, R71.1, R72.1, R73.1, U10.4, U10.7
GNDA: C5.2, C7.2, C11.2, C12.2, C17.2, C18.2, C19.2, C23.2, C24.2, C72.2, C73.1, C75.2, C76.2, C77.2, C80.2, C81.1, C82.2, C83.1, C84.2, C85.1, C86.2, C87.1, C88.2, C89.1, C90.2, C91.1, C92.2, C93.1, C97.2, C98.2, C99.2, FB1.2, IC1.31 (RESV1), IC1.33 (DGND_1), IC1.49 (DGND_2), IC1.51 (DGND_3), IC1.64 (RESERVED), J3.04, J3.10, J3.18, J9.1, JP5.02, OSC1.2 (GND); also elsewhere on the board
GPIO1: IC1.42 (GPIO1), J3.06
GPIO2: IC1.44 (GPIO2), J3.12
GPIO3: IC1.45 (GPIO3), J5.06
GPIO4: IC1.46 (GPIO4), J5.04
unnamed: J3.01, JP21.03, JP22.03
unnamed: J3.02, JP23.03
unnamed: J3.07, JP21.01
unnamed: J3.14, JP22.01
unnamed: J6.02, R12.1
unnamed: JP6.02, R15.2
unnamed: JP7.02, R13.2
unnamed: JP8.01, R14.1
unnamed: JP8.02, R25.2
unnamed: JP25.02, JP25.04, JP25.05, R10.1
unnamed: JP25.06, R11.1
unnamed: C11.1, JP19.02, OSC1.1 (E/D), OSC1.4 (VDD)
unnamed: JP18.01, OSC1.3 (OUTPUT)
unnamed: R13.1, U4.3 (+IN)
unnamed: R14.2, U4.2 (-IN), U4.6 (OUT)
unnamed: R23.1, R24.2, U11.3 (+IN)
unnamed: R15.1, U11.2 (-IN), U11.6 (OUT)
REF_ELEC: C75.1, JP7.03, JP8.03, R11.2
SPI_CLK: IC1.40 (SCLK), J3.03
SPI_CS: IC1.39 (~CS), JP21.02, R75.2
SPI_DRDY: IC1.47 (~DRDY), J3.15
SPI_IN: IC1.34 (DIN), J3.11
SPI_OUT: IC1.43 (DOUT), J3.13
SPI_START: IC1.38 (START), JP22.02
SRB1: C98.1, IC1.17 (SRB1), R25.1
SRB2: IC1.18 (SRB2), JP7.01
VCAP1: C9.1, IC1.28 (VCAP1)
VCAP2: C2.1, IC1.30 (VCAP2)
VCAP3: C3.1, C13.1, IC1.55 (VCAP3)
VCAP4: C1.1, IC1.26 (VCAP4)
VREFP: C10.1, C95.1, IC1.24 (VREFP), TP3.TP
/PWDN: IC1.35 (~PWDN), J5.03, JP5.01, R7.2
/RESET: IC1.36 (~RESET), J3.08, R6.2

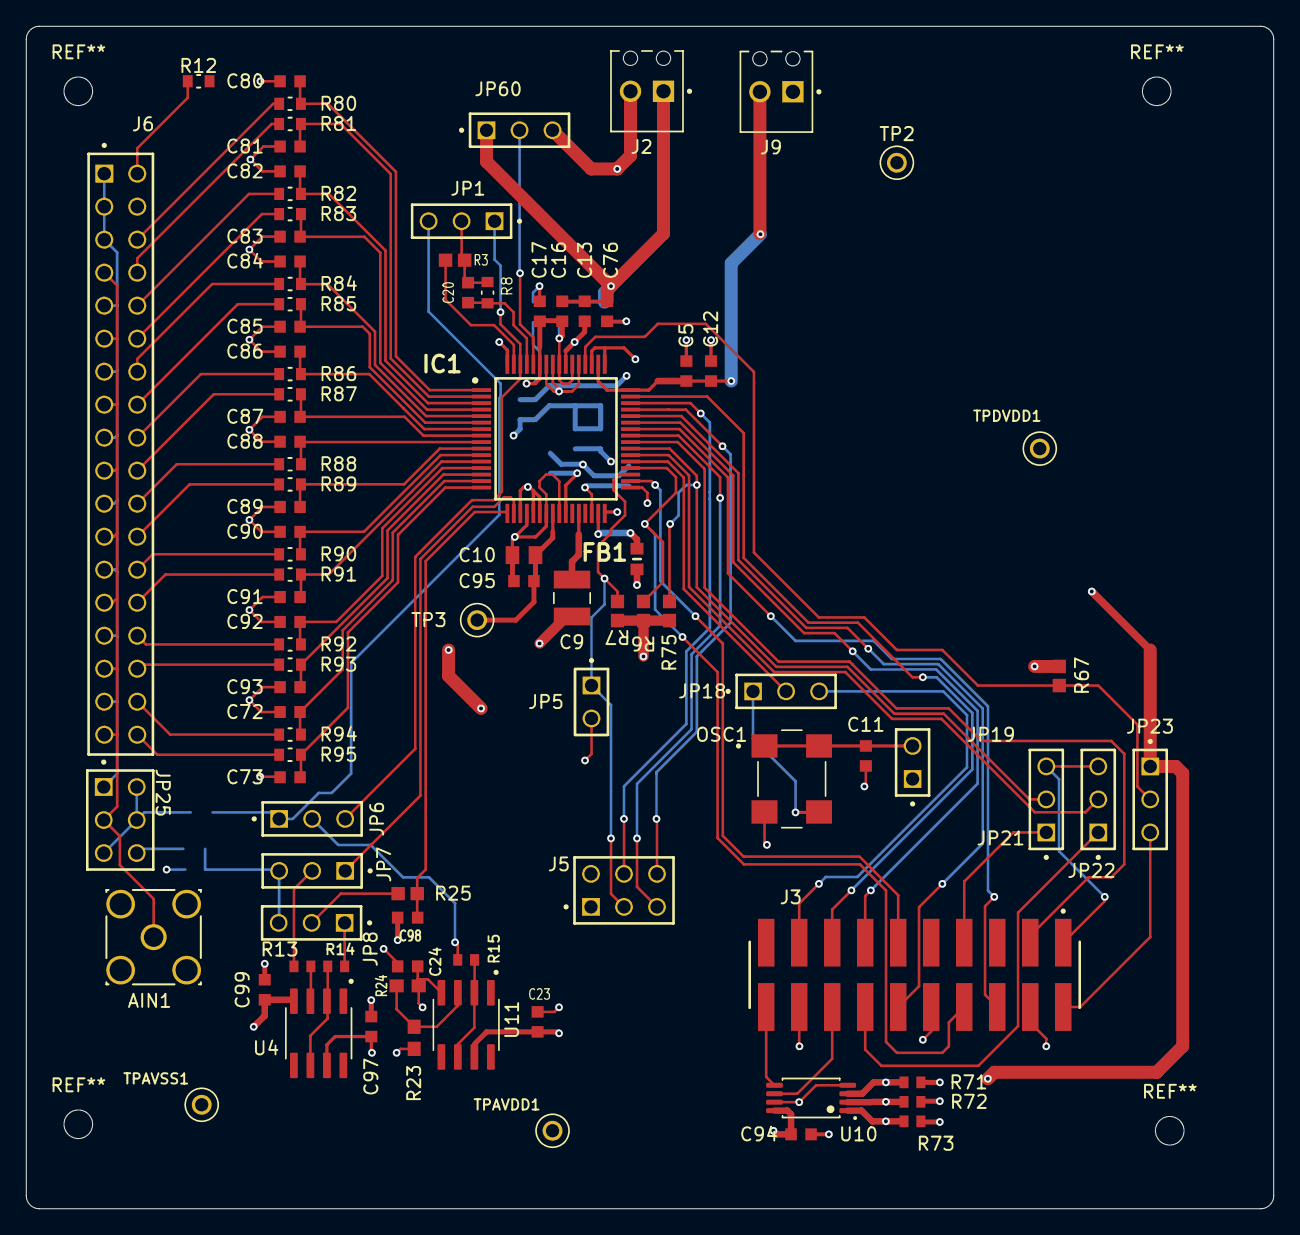
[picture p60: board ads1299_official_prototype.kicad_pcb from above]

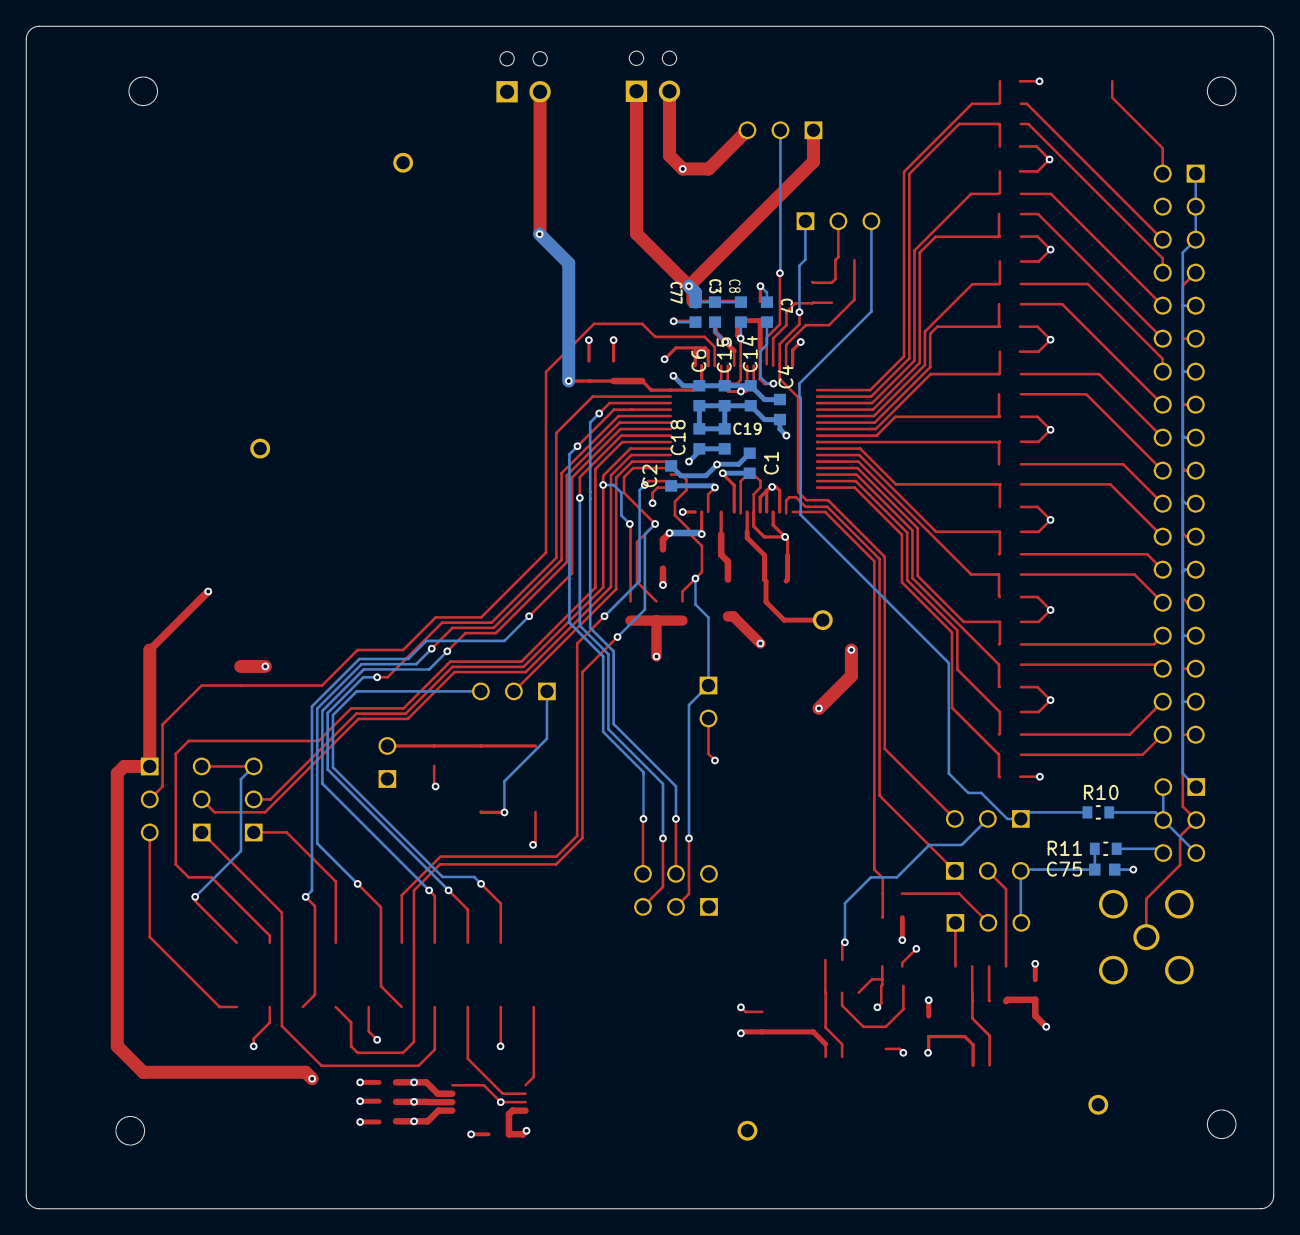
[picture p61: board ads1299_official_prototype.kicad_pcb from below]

Board: 4 copper layers, 96.0 x 91.0 mm, 109 parts (15 on the bottom side), 88 nets.

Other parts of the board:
TP2: 5001; KEYSTONE_5001

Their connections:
GNDA: TP2.TP; also elsewhere on the board

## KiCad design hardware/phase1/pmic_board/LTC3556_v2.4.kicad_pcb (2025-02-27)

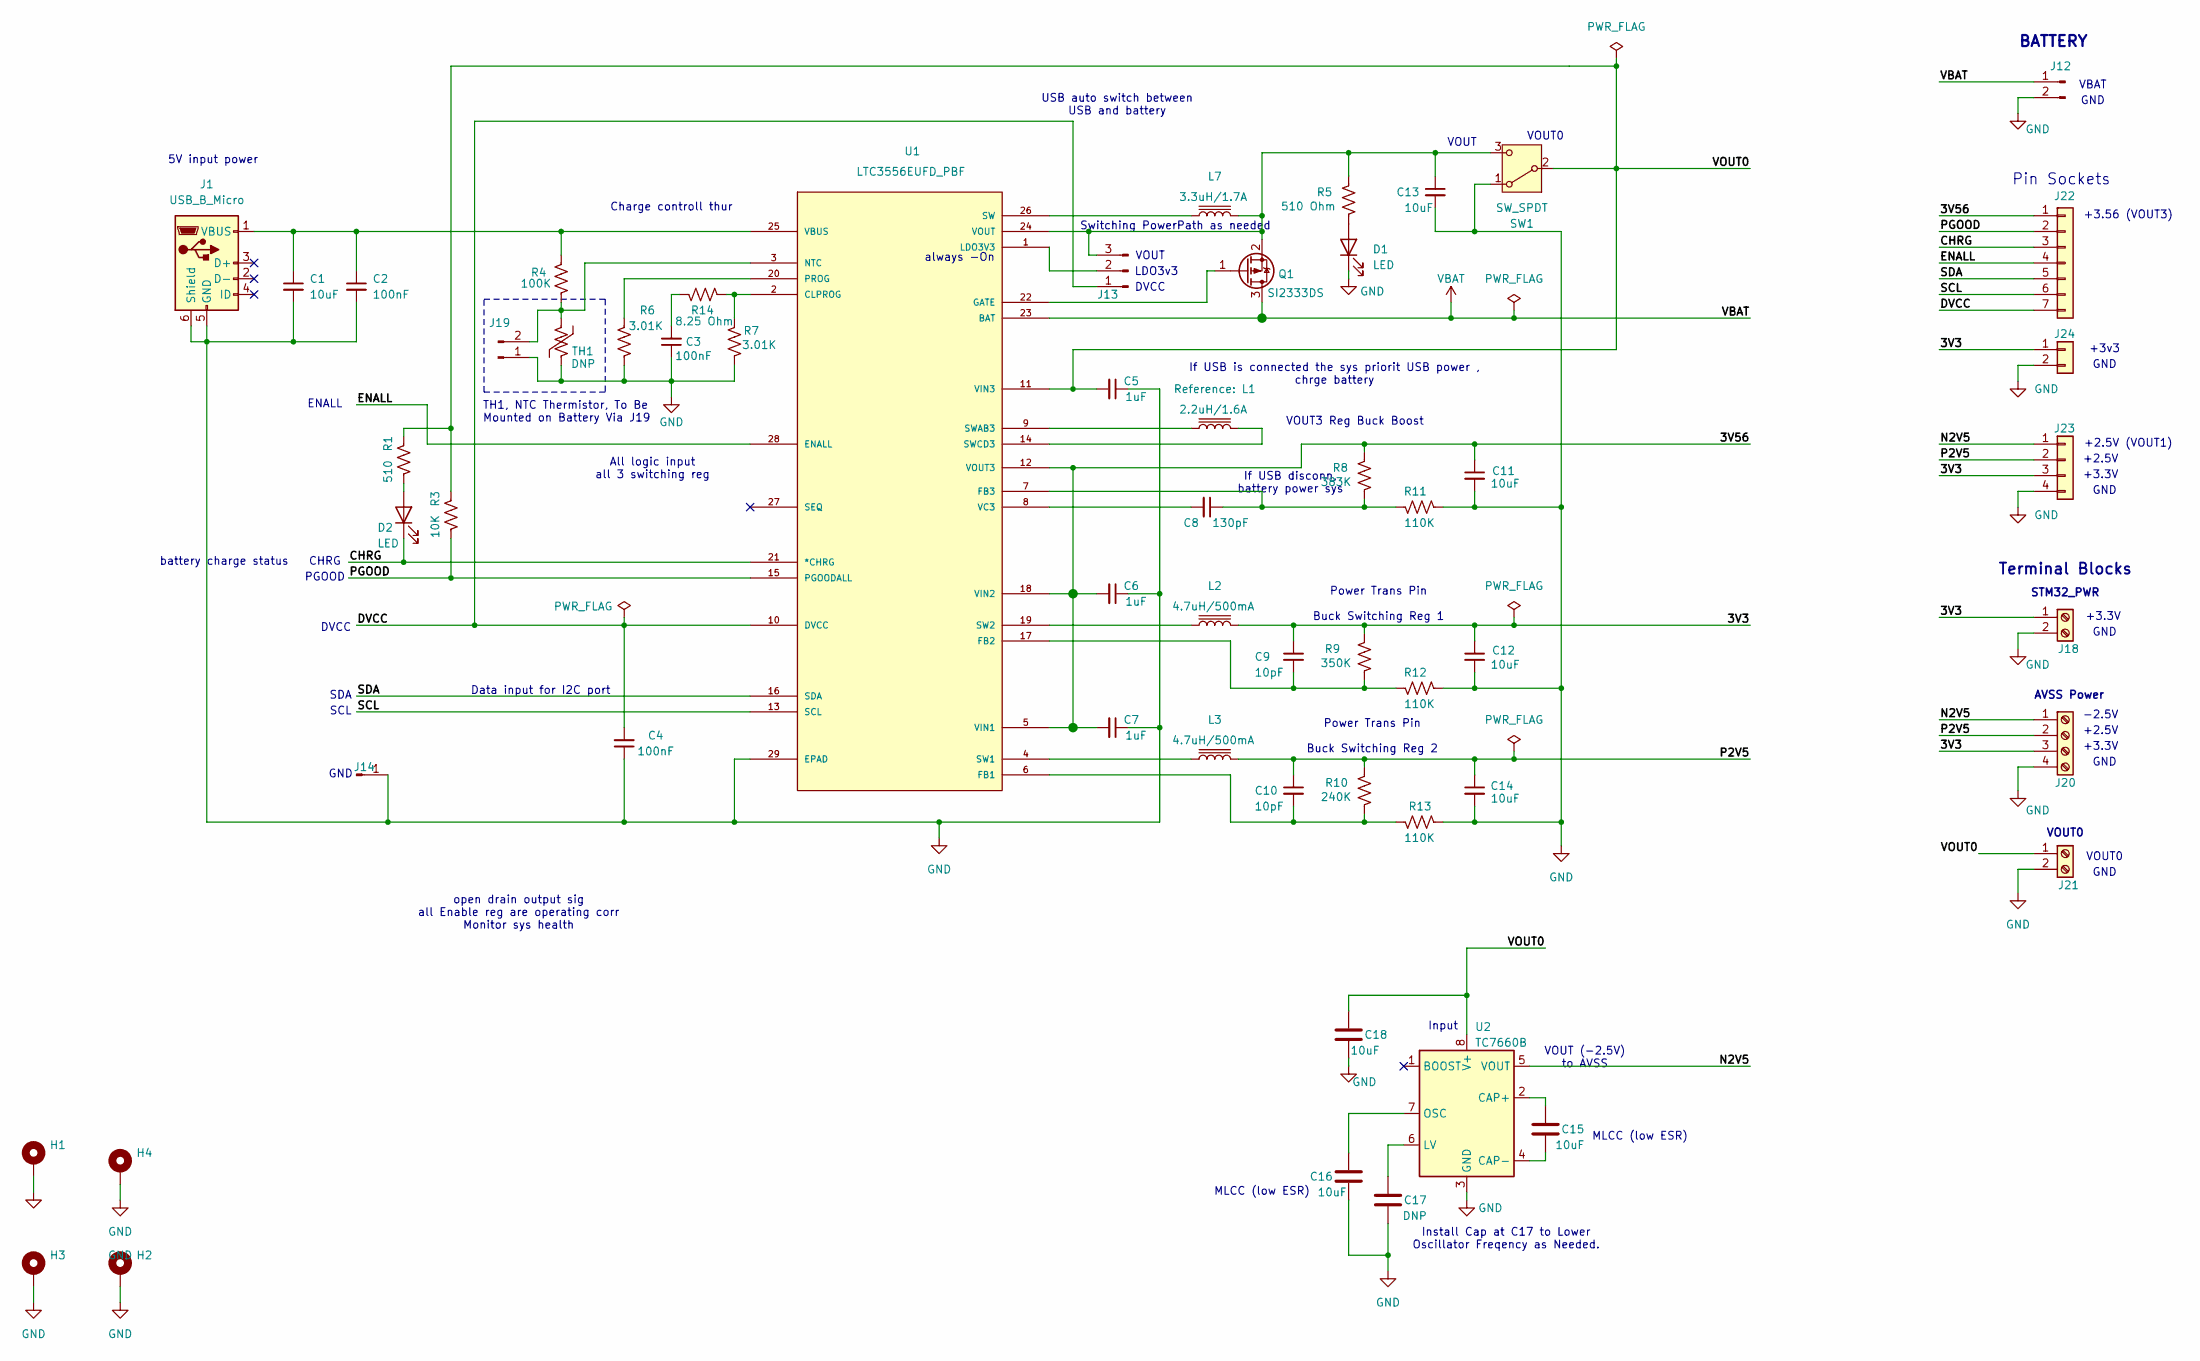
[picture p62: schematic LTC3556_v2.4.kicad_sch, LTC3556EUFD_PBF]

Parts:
C1: 10uF; C_1206_3216Metric
C2: 100nF; C_1206_3216Metric
C3, C4: 100nF; C_0402_1005Metric
C5, C6, C7: 1uF; C_0402_1005Metric
C8: 130pF; C_0402_1005Metric
C9, C10: 10pF; C_0402_1005Metric
C11, C12, C13, C14: 10uF; C_0402_1005Metric
C15, C16, C18: 10uF; C_0805_2012Metric_Pad1.18x1.45mm_HandSolder
C17: DNP; C_0805_2012Metric_Pad1.18x1.45mm_HandSolder
D1, D2: LED; LED_0805_2012Metric_Pad1.15x1.40mm_HandSolder
H1, H2, H3, H4: MountingHole_Pad; MountingHole_3.5mm_Pad_TopBottom
J1: USB_B_Micro; USB_Micro-B_Amphenol_10118194-0001LF_Horizontal; MPN C10418
J12: Conn_01x02_Pin; JST_PH_S2B-PH-K_1x02_P2.00mm_Horizontal; MPN C173752
J13: Conn_01x03_Pin; PinHeader_1x03_P2.54mm_Vertical; MPN C49257
J14: Conn_01x01_Pin; PinHeader_1x01_P2.54mm_Vertical; MPN C492400
J18, J21: Screw_Terminal_01x02; TerminalBlock_Phoenix_MPT-0,5-2-2.54_1x02_P2.54mm_Horizontal; MPN C474920
J19: Conn_01x02_Pin; PinHeader_1x02_P2.54mm_Vertical; MPN C225477
J20: Screw_Terminal_01x04; TerminalBlock_Phoenix_MPT-0,5-4-2.54_1x04_P2.54mm_Horizontal; MPN C474922
J22: Conn_01x07; PinSocket_1x07_P2.54mm_Vertical; MPN C2832270
J23: Conn_01x04; PinSocket_1x04_P2.54mm_Vertical; MPN C2685089
J24: Conn_01x02; PinSocket_1x02_P2.54mm_Vertical; MPN C49661
L1: 2.2uH/1.6A; L_Coilcraft_LPS4018
L2, L3: 4.7uH/500mA; L_Coilcraft_LPS3010
L7: 3.3uH/1.7A; L_Coilcraft_LPS4018
Q1: SI2333DS; SOT-23
R1: 510; R_0402_1005Metric_Pad0.72x0.64mm_HandSolder
R3: 10K; R_0402_1005Metric_Pad0.72x0.64mm_HandSolder
R4: 100K; R_0402_1005Metric_Pad0.72x0.64mm_HandSolder
R5: 510 Ohm; R_0402_1005Metric_Pad0.72x0.64mm_HandSolder
R6, R7: 3.01K; R_0402_1005Metric_Pad0.72x0.64mm_HandSolder
R8: 383K; R_0402_1005Metric_Pad0.72x0.64mm_HandSolder
R9: 350K; R_0603_1608Metric
R10: 240K; R_0402_1005Metric_Pad0.72x0.64mm_HandSolder
R11, R12, R13: 110K; R_0402_1005Metric_Pad0.72x0.64mm_HandSolder
R14: 8.25 Ohm; R_0402_1005Metric_Pad0.72x0.64mm_HandSolder
SW1: SW_SPDT; SW_Slide_SPDT_Straight_CK_OS102011MS2Q; MPN C480342
TH1: DNP; C_Disc_D3.0mm_W1.6mm_P2.50mm
U1: LTC3556EUFD_PBF; QFN-28-1EP_4x5mm_P0.5mm_EP2.65x3.65mm_ThermalVias; MANUFACTURER_PART_NUMBER ltc3556eufd#pbf; DigiKey_Part_Number 505-LTC3556EUFD#PBF-ND
U2: TC7660B; SOIC-8_3.9x4.9mm_P1.27mm; MPN C512761

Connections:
/3V3: C9.1, C12.1, J18.1, J20.3, J23.3, J24.1, L2.1, R9.1
/3V56: C6.2, C7.2, C11.1, J22.1, R8.1, U1.5 (VIN1), U1.12 (VOUT3), U1.18 (VIN2)
/CHRG: D2.1 (K), J22.3, U1.21 (*CHRG)
/DVCC: C4.2, J13.1, J22.7, U1.10 (DVCC)
/ENALL: J22.4, U1.28 (ENALL)
/N2V5: J20.1, J23.1, U2.5 (VOUT)
/P2V5: C10.1, C14.1, J20.2, J23.2, L3.1, R10.1
/PGOOD: J22.2, R3.2, U1.15 (PGOODALL)
/SCL: J22.6, U1.13 (SCL)
/SDA: J22.5, U1.16 (SDA)
/VOUT0: C5.2, C18.1, J21.1, R1.1, R3.1, SW1.2 (B), U1.11 (VIN3), U2.8 (V+)
GND: C1.2, C2.2, C3.1, C4.1, C5.1, C6.1, C7.1, C11.2, C12.2, C13.2, C14.2, C16.1, C17.2, C18.2, D1.1 (K), H1.1, H2.1, H3.1, H4.1, J1.5 (GND), J1.6 (Shield), J12.2, J14.1, J18.2, J19.1, J20.4, J21.2, J23.4, J24.2, R6.2, R7.2, R11.2, R12.2, R13.2, SW1.1 (A), TH1.1, U1.29 (EPAD), U2.3 (GND)
unnamed: C3.2, R14.2
unnamed: D1.2 (A), R5.2
unnamed: D2.2 (A), R1.2
unnamed: C1.1, C2.1, J1.1 (VBUS), R4.1, U1.25 (VBUS)
unnamed: J13.2, U1.1 (LDO3V3)
unnamed: C13.1, J13.3, L7.1, Q1.2 (S), R5.1, SW1.3 (C), U1.24 (VOUT)
unnamed: J19.2, R4.2, TH1.2, U1.3 (NTC)
unnamed: Q1.1 (G), U1.22 (GATE)
unnamed: R7.1, R14.1, U1.2 (CLPROG)
unnamed: C10.2, R10.2, R13.1, U1.6 (FB1)
unnamed: C9.2, R9.2, R12.1, U1.17 (FB2)
unnamed: C8.1, R8.2, R11.1, U1.7 (FB3)
unnamed: R6.1, U1.20 (PROG)
unnamed: L3.2, U1.4 (SW1)
unnamed: L2.2, U1.19 (SW2)
unnamed: L7.2, U1.26 (SW)
unnamed: L1.2, U1.9 (SWAB3)
unnamed: L1.1, U1.14 (SWCD3)
unnamed: C8.2, U1.8 (VC3)
unnamed: C15.1, U2.2 (CAP+)
unnamed: C15.2, U2.4 (CAP-)
unnamed: C17.1, U2.6 (LV)
unnamed: C16.2, U2.7 (OSC)
VBAT: J12.1, Q1.3 (D), U1.23 (BAT)

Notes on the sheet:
Power Trans Pin Buck Switching Reg 2
GND
+3.3V
Charge controll thur
Data input for I2C port
VOUT
AVSS Power
+2.5V
LDO3v3
BATTERY
VOUT
SDA
If USB is connected the sys priorit USB power , chrge battery
Input
MLCC (low ESR)
VOUT0
+3v3
always -On
DVCC
-2.5V
All logic input all 3 switching reg
SCL
TH1, NTC Thermistor, To Be Mounted on Battery Via J19
Terminal Blocks
5V input power
VBAT
USB auto switch between USB and battery
Switching PowerPath as needed
Power Trans Pin Buck Switching Reg 1
VOUT (-2.5V) to AVSS
If USB disconn, battery power sys
Pin Sockets
Install Cap at C17 to Lower Oscillator Freqency as Needed.
open drain output sig all Enable reg are operating corr Monitor sys health
+3.56 (VOUT3)
ENALL
STM32_PWR
battery charge status
PGOOD
+2.5V (VOUT1)


Board: 4 copper layers, 63.5 x 44.5 mm, 57 parts (0 on the bottom side), 36 nets.

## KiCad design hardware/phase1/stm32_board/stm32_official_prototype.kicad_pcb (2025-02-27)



Board: 4 copper layers, 103.6 x 114.0 mm, 73 parts (22 on the bottom side), 136 nets.

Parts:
B1, B2: TS02-66-60-BK-160-LCR-D; SW_TS04-66-43-BK-260-SMT
C19, C27: 1uF; CAPC1608X90
C20, C26, C28, C29, C30, C31, C32, C33, C34, C41, C49, C50, C51, C53, C57, C58, C61: 100nF; CAPC1608X90
C40: [N/A]; CAPC1608X90
C42: 4.7uF; CAPMP3216X166
C52, C54: 4.7uF_X54_0603; CAPC1608X90
C56, C59: 1uF; CAPMP3216X166
C60: 1uF_X5R_0603; CAPC1608X90
CN5: Conn_ARM_JTAG_SWD_10; PinSocket_2x05_P2.54mm_Vertical
CN11, CN12: Conn_02x36_Odd_Even; PinSocket_2x36_P2.54mm_Vertical
CN14: USB_B_Micro; MOLEX_47589-1001
D2: SMLVT3V3; DIOM4336X265N
D6: ESDALC6V1-1U2; DIODE_ESDALC6V1-1U2
J1: Screw_Terminal_01x02; PHOENIX_1725656
L3: BEAD; FB0603
LD1, LD6, LD8: Green; LED-0603
LD2: Blue; LED-0603
LD3, LD7: Red; LED-0603
R28, R29: 1K; RESC1607X60N
R30: 680; R0603
R31: 510; RESC1608X60N
R36: 200K; RESC1608X60N
R37, R38, R52, R54: 10K; RESC1607X60N
R41, R43: 330; RESC1607X60N
R42: 220K; RESC1607X60N
R44: 100; RESC1607X60N
R45: 620; RC0603N_YAG
R48: 22K; RESC1607X60N
R49, R51: 47K; RESC1608X55
SB124, SB132, SB135, SB142, SB143, SB172, SB197: Closed; RESC1607X60N
T2: 9013; SOT-23
U6: LD39050PU33R; SON95P300X300X100-7N
U8: TSV631AILT; SOT23-5_STM
U9: ESDALC6V1W5; SOT65P210X110-5N
U11: STM32L496ZGTx; LQFP144-20x20mm_STM
U12: STMPS2151STR; SOT95P280X145-5N
U13: USBLC6-2SC6; SOT95P280X145-6N

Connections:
+3V3: C27.1, CN11.16, J1.2, R28.1, U6.6 (VIN)
AVDD: C56.1, C57.1, C58.1, C59.1, CN12.7, L3.2, U11.32 (VREF+), U11.33 (VDDA)
GND: B2.1, B2.4, C19.2, C20.2, C26.2, C27.2, C28.2, C29.2, C30.2, C31.2, C32.2, C33.2, C34.2, C41.2, C49.2, C50.2, C51.2, C52.2, C53.2, C54.2, C56.2, C57.2, C58.2, C59.2, C60.2, C61.2, CN5.3 (GND), CN5.5 (GND), CN5.9 (GNDDetect), CN11.8, CN11.19, CN11.20, CN11.22, CN11.49, CN11.60, CN11.71, CN11.72, CN12.9, CN12.20, CN12.32, CN12.39, CN12.54, CN12.63, CN12.71, CN12.72, CN14.5 (GND), D2.2 (A), D6.2 (A), J1.1, R36.1, R38.2, R42.1, R48.2, R52.1, T2.2, U6.2 (GND), U6.7 (GND), U8.2 (VCC-), U11.16 (VSS), U11.30 (VSSA), U11.31 (VREF-), U11.38 (VSS), U11.51 (VSS), U11.61 (VSS), U11.71 (VSS), U11.83 (VSS), U11.94 (VSS), U11.107 (VSS), U11.120 (VSS), U11.130 (VSS), U11.143 (VSS), U12.2 (GND), U13.2 (GND)
NRST: B2.2, B2.3, C41.1, CN5.10 (~RESET), CN11.14, U9.3, U11.25 (NRST)
unnamed: B1.1, B1.4, C40.1, R42.2, R43.2
unnamed: C40.2, R44.2
unnamed: R51.1, U12.3 (~FAULT)
unnamed: R29.1, SB132.2
unnamed: R37.1, SB124.2
unnamed: R43.1, SB197.2
unnamed: R48.1, R49.2, T2.1
unnamed: R54.1, SB135.2
unnamed: C26.1, U6.1 (EN)
unnamed: R36.2, R37.2, U8.1 (IN+)
unnamed: R31.1, U8.3 (IN-), U8.4 (OUT)
unnamed: SB172.1, U11.137 (PB7)
unnamed: R52.2, U12.4 (EN)
PA0: CN11.28, U11.34 (PA0)
PA1: CN11.30, U11.35 (PA1)
PA2: CN12.35, U11.36 (PA2)
PA3: CN12.37, U11.37 (PA3)
PA4: CN11.32, U11.40 (PA4)
PA5: CN12.11, U11.41 (PA5)
PA6: CN12.13, U11.42 (PA6)
PA7: CN12.15, U11.43 (PA7)
PA8: CN12.23, U11.100 (PA8)
PA9: CN12.21, SB135.1, U11.101 (PA9)
PA10: CN12.33, CN14.4 (ID), D6.1 (K), U11.102 (PA10)
PA11: CN12.14, SB142.1, U11.103 (PA11)
PA12: CN12.12, SB143.1, U11.104 (PA12)
PA13: CN5.2 (SWDIO/TMS), CN11.13, U9.4, U11.105 (PA13)
PA14: CN5.4 (SWCLK/TCK), CN11.15, U9.2, U11.109 (PA14)
PA15: CN11.17, U11.110 (PA15)
PB0: CN11.34, U11.46 (PB0)
PB1: CN12.24, U11.47 (PB1)
PB2: CN12.22, U11.48 (PB2)
PB3: CN5.6 (SWO/TDO), CN12.31, U9.1, U11.133 (PB3)
PB4: CN12.27, U11.134 (PB4)
PB5: CN12.29, U11.135 (PB5)
PB6: CN12.17, U11.136 (PB6)
PB7: CN11.21, R30.1, SB172.2
PB8: CN12.3, U11.139 (PB8)
PB9: CN12.5, U11.140 (PB9)
PB10: CN12.25, U11.69 (PB10)
PB11: CN12.18, U11.70 (PB11)
PB12: CN12.16, U11.73 (PB12)
PB13: CN12.30, U11.74 (PB13)
PB14: CN12.28, SB132.1, U11.75 (PB14)
PB15: CN12.26, U11.76 (PB15)
PC0: CN11.38, U11.26 (PC0)
PC1: CN11.36, U11.27 (PC1)
PC2: CN11.35, U11.28 (PC2)
PC3: CN11.37, U11.29 (PC3)
PC4: CN12.34, U11.44 (PC4)
PC5: CN12.6, U11.45 (PC5)
PC6: CN12.4, U11.96 (PC6)
PC7: CN12.19, SB124.1, U11.97 (PC7)
PC8: CN12.2, U11.98 (PC8)
PC9: CN12.1, U11.99 (PC9)
PC10: CN11.1, U11.111 (PC10)
PC11: CN11.2, U11.112 (PC11)
PC12: CN11.3, U11.113 (PC12)
PC13: CN11.23, SB197.1, U11.7 (PC13)
PC14: CN11.25, U11.8 (PC14)
PC15: CN11.27, U11.9 (PC15)
PD0: CN11.57, U11.114 (PD0)
PD1: CN11.55, U11.115 (PD1)
PD2: CN11.4, U11.116 (PD2)
PD3: CN11.40, U11.117 (PD3)
PD4: CN11.39, U11.118 (PD4)
PD5: CN11.41, U11.119 (PD5)
PD6: CN11.43, U11.122 (PD6)
PD7: CN11.45, U11.123 (PD7)
PD8: CN12.10, U11.77 (PD8)
PD9: CN11.69, U11.78 (PD9)
PD10: CN12.65, U11.79 (PD10)
PD11: CN12.45, U11.80 (PD11)
PD12: CN12.43, U11.81 (PD12)
PD13: CN12.41, U11.82 (PD13)
PD14: CN12.46, U11.85 (PD14)
PD15: CN12.48, U11.86 (PD15)
PE0: CN12.64, U11.141 (PE0)
PE1: CN11.61, U11.142 (PE1)
PE2: CN11.46, U11.1 (PE2)
PE3: CN11.47, U11.2 (PE3)
PE4: CN11.48, U11.3 (PE4)
PE5: CN11.50, U11.4 (PE5)
PE6: CN11.62, U11.5 (PE6)
PE7: CN12.44, U11.58 (PE7)
PE8: CN12.40, U11.59 (PE8)
PE9: CN12.52, U11.60 (PE9)
PE10: CN12.47, U11.63 (PE10)
PE11: CN12.56, U11.64 (PE11)
PE12: CN12.49, U11.65 (PE12)
PE13: CN12.55, U11.66 (PE13)
PE14: CN12.51, U11.67 (PE14)
PE15: CN12.53, U11.68 (PE15)
PF0: CN11.53, U11.10 (PF0)
PF1: CN11.51, U11.11 (PF1)
PF2: CN11.52, U11.12 (PF2)
PF3: CN12.58, U11.13 (PF3)
PF4: CN12.38, U11.14 (PF4)
PF5: CN12.36, U11.15 (PF5)
PF6: CN11.9, U11.18 (PF6)
PF7: CN11.11, U11.19 (PF7)
PF8: CN11.54, U11.20 (PF8)
PF9: CN11.56, U11.21 (PF9)
PF10: CN12.42, U11.22 (PF10)
PF11: CN12.62, U11.49 (PF11)
PF12: CN12.59, U11.50 (PF12)
PF13: CN12.57, U11.53 (PF13)
PF14: CN12.50, U11.54 (PF14)
PF15: CN12.60, U11.55 (PF15)
PG0: CN11.59, U11.56 (PG0)
PG1: CN11.58, U11.57 (PG1)
PG2: CN11.42, U11.87 (PG2)
PG3: CN11.44, U11.88 (PG3)
PG4: CN12.69, U11.89 (PG4)
PG5: CN12.68, U11.90 (PG5)
PG6: CN12.70, U11.91 (PG6)
PG7: CN12.67, U11.92 (PG7)
PG8: CN12.66, U11.93 (PG8)
PG9: CN11.63, U11.124 (PG9)
PG10: CN11.66, U11.125 (PG10)
PG11: CN11.70, U11.126 (PG11)
PG12: CN11.65, U11.127 (PG12)
PG13: CN11.68, U11.128 (PG13)
PG14: CN12.61, U11.129 (PG14)
PG15: CN11.64, U11.132 (PG15)
PH0: CN11.29, U11.23 (PH0)
PH1: CN11.31, U11.24 (PH1)
PH3-BOOT0: CN11.7, R38.1, U11.138 (PH3)
USB_DN: CN14.2 (D-), SB142.2, U13.1 (I/O1), U13.6 (I/O1)
USB_DP: CN14.3 (D+), SB143.2, U13.3 (I/O2), U13.4 (I/O2)
USB_VBUS: CN14.1 (VBUS), R49.1, R54.2, U12.1 (OUT), U13.5 (VBUS)
VDD: B1.2, B1.3, C19.1, C20.1, C28.1, C29.1, C30.1, C31.1, C32.1, C33.1, C34.1, C49.1, C50.1, C51.1, C52.1, C53.1, C54.1, C60.1, C61.1, CN5.1 (VTref), CN11.5, CN11.33, D2.1 (K), L3.1, R41.2, R44.1, R45.2, R51.2, U6.4 (VOUT), U8.5 (VCC+), U11.6 (VBAT), U11.17 (VDD), U11.39 (VDD), U11.52 (VDD), U11.62 (VDD), U11.72 (VDD), U11.84 (VDD), U11.95 (VDDIO2), U11.106 (VDDUSB), U11.108 (VDD), U11.121 (VDD), U11.131 (VDDIO2), U11.144 (VDD), U12.5 (IN)

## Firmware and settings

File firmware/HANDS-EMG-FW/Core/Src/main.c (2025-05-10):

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
/* Includes ------------------------------------------------------------------*/
#include "main.h"

/* USER CODE BEGIN Includes */
#include <stdlib.h>		// For exit()
#include <math.h>		// For fabsf(float);
#include <stdbool.h>	// For bool activation_trigger, bool ml_collecting
#include <stdint.h>		// For uints etc.

#include "ads1299.h"
#include "NanoEdgeAI.h"
#include "knowledge.h"
/* USER CODE END Includes */

SPI_HandleTypeDef hspi1;

UART_HandleTypeDef huart2;

/* USER CODE BEGIN PV */


// =======================
//        Defines
// =======================
#define ML_SAMPLE_COUNT         1024       // Number of samples for ML input
#define INTENSITY_BUFFER_SIZE   10	        // Short buffer window for intensity comparison

#define USE_THRESHOLDING		1
#define INTENSITY_THRESHOLD     1.15f       // 80% increase threshold

#define ML_TRAINING_MODE		0


#if ML_TRAINING_MODE
#define GRAPH_MODE_ENABLED 0
#define CHUNK_MODE_ENABLED 1
#else
#define GRAPH_MODE_ENABLED 1
#define CHUNK_MODE_ENABLED 0
#endif


// =======================
//     Global Variables
// =======================

// --- ML buffer ---
volatile float ml_buffer[ML_SAMPLE_COUNT * 4];  // Interleaved EMG: CH1_0, CH2_0, ..., CH4_1023
volatile float output_class_buffer[CLASS_NUMBER];
volatile uint16_t ml_index = 0;
volatile bool ml_collecting = false;
volatile uint32_t ml_class = 0;                 // Last ML classification result (0 = none)

// --- Intensity detection ---

static bool intensity_initialized = false;
#define TRIGG_WAIT 251
volatile uint32_t just_triggered = 0;

volatile float ch1_buffer[INTENSITY_BUFFER_SIZE] = {0};
volatile float ch2_buffer[INTENSITY_BUFFER_SIZE] = {0};
volatile float ch3_buffer[INTENSITY_BUFFER_SIZE] = {0};
volatile float ch4_buffer[INTENSITY_BUFFER_SIZE] = {0};

volatile float ch1_I1 = 0, ch1_I2 = 0;
volatile float ch2_I1 = 0, ch2_I2 = 0;
volatile float ch3_I1 = 0, ch3_I2 = 0;
volatile float ch4_I1 = 0, ch4_I2 = 0;

volatile uint16_t intensity_counter = 0;


/* USER CODE END PV */

void SystemClock_Config(void);
static void MX_GPIO_Init(void);
static void MX_SPI1_Init(void);
static void MX_USART2_UART_Init(void);
/**
  * @brief  The application entry point.
  * @retval int
  */
int main(void)
{

  /* MCU Configuration--------------------------------------------------------*/

  /* Reset of all peripherals, Initializes the Flash interface and the Systick. */
  HAL_Init();

  /* Configure the system clock */
  SystemClock_Config();

  /* Initialize all configured peripherals */
  MX_GPIO_Init();
  MX_SPI1_Init();
  MX_USART2_UART_Init();
  /* USER CODE BEGIN 2 */
  // Enable digital I/O to default state ADS1299
    HAL_GPIO_WritePin(SPI1_CS_GPIO_Port, SPI1_CS_Pin, GPIO_PIN_SET);
    HAL_GPIO_WritePin(ADS1299_NRESET_GPIO_Port, ADS1299_NRESET_Pin, GPIO_PIN_SET);
    HAL_GPIO_WritePin(ADS1299_NPWDN_GPIO_Port, ADS1299_NPWDN_Pin, GPIO_PIN_SET);

    // Initialize ADS1299
    ads1299_device_init(&hspi1, 1);
    HAL_Delay(1000);
    HAL_GPIO_WritePin(ADS1299_START_GPIO_Port, ADS1299_START_Pin, GPIO_PIN_SET);

    // Initialize ML
    enum neai_state error_code = neai_classification_init(knowledge);
    if (error_code != NEAI_OK) {
  	  exit(1);
    }

  /* USER CODE END 2 */

  /* Infinite loop */
  /* USER CODE BEGIN WHILE */
  while (1)
  {
    /* USER CODE END WHILE */

    /* USER CODE BEGIN 3 */

  }
  /* USER CODE END 3 */
}

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
/* USER CODE BEGIN 4 */
/**
 * @brief When DRDY falling edge, transmit to read data
 * @param GPIO Pin that interrupt happened
 * @return None
 */
void HAL_GPIO_EXTI_Callback(uint16_t GPIO_Pin)
{
  // If we see NDRDY, we begin reading data
  if(GPIO_Pin == ADS1299_NDRDY_Pin) {
    ads1299_read_data_IT(&hspi1);
  } else {
      __NOP();
  }
}

/**
 * @brief Call back that occurs when ADS is fully read from
 */
void HAL_SPI_TxRxCpltCallback(SPI_HandleTypeDef *hspi)
{
	// 1. De-assert chip select
    HAL_GPIO_WritePin(SPI1_CS_GPIO_Port, SPI1_CS_Pin, GPIO_PIN_SET);

    // 2. Extract and check ADS1299 status bits
    uint32_t status = (RX_BUFF[0] << 16) | (RX_BUFF[1] << 8) | RX_BUFF[2];
    if (status != 0b110000000000000000000000) {
        uint8_t fail_msg[] = {'F', 'A', 'I', 'L'};
        HAL_UART_Transmit(&huart2, fail_msg, sizeof(fail_msg), HAL_MAX_DELAY);
        return;
    }

    // 3. Parse 4 EMG channels from ADS1299 (3 bytes per channel)
    float ch[4];
    for (int i = 0; i < 4; i++) {
        uint32_t raw = (RX_BUFF[3 + i * 3] << 16) |
                       (RX_BUFF[4 + i * 3] << 8) |
                       (RX_BUFF[5 + i * 3]);
        ch[i] = ads1299_data_to_float(raw);
    }

#if USE_THRESHOLDING
    // 4. Update intensity buffers (absolute value)
    ch1_buffer[intensity_counter] = fabsf(ch[0]);
    ch2_buffer[intensity_counter] = fabsf(ch[1]);
    ch3_buffer[intensity_counter] = fabsf(ch[2]);
    ch4_buffer[intensity_counter] = fabsf(ch[3]);
    intensity_counter++;

    bool activation_triggered = false;

    if (intensity_counter >= INTENSITY_BUFFER_SIZE) {
    	if (!intensity_initialized) {
			ch1_I1 = ch2_I1 = ch3_I1 = ch4_I1 = 1e-6f;  // Avoid divide-by-zero
			intensity_initialized = true;
			return;
		}
        // Shift intensities: I1 <- I2, I2 <- new average
        ch1_I1 = ch1_I2; ch2_I1 = ch2_I2; ch3_I1 = ch3_I2; ch4_I1 = ch4_I2;
        ch1_I2 = ch2_I2 = ch3_I2 = ch4_I2 = 0.0f;

        for (int i = 0; i < INTENSITY_BUFFER_SIZE; i++) {
            ch1_I2 += ch1_buffer[i];
            ch2_I2 += ch2_buffer[i];
            ch3_I2 += ch3_buffer[i];
            ch4_I2 += ch4_buffer[i];
        }

        ch1_I2 /= INTENSITY_BUFFER_SIZE;
        ch2_I2 /= INTENSITY_BUFFER_SIZE;
        ch3_I2 /= INTENSITY_BUFFER_SIZE;
        ch4_I2 /= INTENSITY_BUFFER_SIZE;

        // Compare for significant intensity increase
        if (((ch1_I2 >= INTENSITY_THRESHOLD * ch1_I1) ||
            (ch2_I2 >= INTENSITY_THRESHOLD * ch2_I1) ||
            (ch3_I2 >= INTENSITY_THRESHOLD * ch3_I1) ||
            (ch4_I2 >= INTENSITY_THRESHOLD * ch4_I1))&& just_triggered >= TRIGG_WAIT) {
            activation_triggered = true;
            just_triggered = 0;
        } else {
        	if (just_triggered < TRIGG_WAIT+2) {
        		just_triggered++;
        	}
        }

        intensity_counter = 0;
    }

    // 5. Handle ML buffer activation
    if (activation_triggered && !ml_collecting) {
        ml_collecting = true;
        ml_index = 0;
    }
#else
    ml_collecting = true;
#endif

    // 6. Collect into ML buffer
    if (ml_collecting) {
        ml_buffer[ml_index++] = ch[0];
        ml_buffer[ml_index++] = ch[1];
        ml_buffer[ml_index++] = ch[2];
        ml_buffer[ml_index++] = ch[3];

        if (ml_index >= ML_SAMPLE_COUNT * 4) {
//             Run classification
        	__disable_irq();
            uint16_t class_id = 0;
            neai_classification((float *)ml_buffer, (float *)output_class_buffer, &class_id);
            ml_class = (uint32_t)class_id;
            __enable_irq();

#if CHUNK_MODE_ENABLED
            // Transmit full buffer + classification result
            uint32_t header = 0x53594E43;  // "SYNC"
            HAL_UART_Transmit(&huart2, (uint8_t*)&header, sizeof(header), HAL_MAX_DELAY);
            HAL_UART_Transmit(&huart2, (uint8_t*)ml_buffer, sizeof(float) * ML_SAMPLE_COUNT * 4, HAL_MAX_DELAY);
            HAL_UART_Transmit(&huart2, (uint8_t*)&ml_class, sizeof(ml_class), HAL_MAX_DELAY);
#endif

            ml_index = 0;
            ml_collecting = false;
        }
    }

#if GRAPH_MODE_ENABLED
    // 7. Transmit single sample for live plotting
    float tx_buffer[6];
    tx_buffer[0] = *(float*)&(uint32_t){0x53594E43};  // "SYNC" as float
    tx_buffer[1] = ch[0];
    tx_buffer[2] = ch[1];
    tx_buffer[3] = ch[2];
    tx_buffer[4] = ch[3];
    tx_buffer[5] = *(float*)&ml_class;

    HAL_UART_Transmit(&huart2, (uint8_t*)tx_buffer, sizeof(tx_buffer), HAL_MAX_DELAY);

    // Reset classification until next result
    ml_class = 0;
#endif
}


/* USER CODE END 4 */
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


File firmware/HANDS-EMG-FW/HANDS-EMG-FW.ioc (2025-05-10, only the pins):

Mcu.UserName=STM32L496RGTx
PA0.Signal=GPIO_Analog
PA1.Signal=SPI1_SCK
PA10.Signal=GPIO_Analog
PA11.Signal=GPIO_Analog
PA12.Signal=GPIO_Analog
PA2.Signal=USART2_TX
PA3.Signal=USART2_RX
PA4.GPIO_Label=SPI1_CS
PA4.Signal=GPIO_Output
PA5.GPIO_Label=ADS1299_NDRDY
PA5.Signal=GPXTI5
PA6.Signal=SPI1_MISO
PA7.Signal=SPI1_MOSI
PA8.Signal=GPIO_Analog
PA9.Signal=GPIO_Analog
PB0.GPIO_Label=ADS1299_START
PB0.Signal=GPIO_Output
PB1.Signal=GPIO_Analog
PB10.Signal=GPIO_Analog
PB11.Signal=GPIO_Analog
PB12.Signal=GPIO_Analog
PB13.Signal=GPIO_Analog
PB14.Signal=GPIO_Analog
PB15.Signal=GPIO_Analog
PB2.Signal=GPIO_Analog
PB5.Signal=GPIO_Analog
PB6.Signal=GPIO_Analog
PB7.Signal=GPIO_Analog
PB8.Signal=GPIO_Analog
PB9.Signal=GPIO_Analog
PC0.Signal=GPIO_Analog
PC1.Signal=GPIO_Analog
PC10.Signal=GPIO_Analog
PC11.Signal=GPIO_Analog
PC12.Signal=GPIO_Analog
PC13.Signal=GPIO_Analog
PC2.Signal=GPIO_Analog
PC3.Signal=GPIO_Analog
PC4.GPIO_Label=ADS1299_NPWDN
PC4.Signal=GPIO_Output
PC5.GPIO_Label=ADS1299_NRESET
PC5.Signal=GPIO_Output
PC6.Signal=GPIO_Analog
PC7.Signal=GPIO_Analog
PC8.Signal=GPIO_Analog
PC9.Signal=GPIO_Analog
PD2.Signal=GPIO_Analog
PH3-BOOT0.Signal=GPIO_Analog

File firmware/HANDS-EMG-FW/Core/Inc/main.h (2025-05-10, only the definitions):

#define SPI1_CS_Pin GPIO_PIN_4
#define SPI1_CS_GPIO_Port GPIOA
#define ADS1299_NDRDY_Pin GPIO_PIN_5
#define ADS1299_NDRDY_GPIO_Port GPIOA
#define ADS1299_NDRDY_EXTI_IRQn EXTI9_5_IRQn
#define ADS1299_NPWDN_Pin GPIO_PIN_4
#define ADS1299_NPWDN_GPIO_Port GPIOC
#define ADS1299_NRESET_Pin GPIO_PIN_5
#define ADS1299_NRESET_GPIO_Port GPIOC
#define ADS1299_START_Pin GPIO_PIN_0
#define ADS1299_START_GPIO_Port GPIOB

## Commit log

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2024-10-21 added QFN to DIP schem
    currently unfinished, needs compensator along boost rail, and also pin alignments for right side of pinout
    [QFNtoDIP.kicad_pcb, QFNtoDIP.kicad_sch]
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2024-12-21 In the process of correcting Power flags at main power sources such as Vin/Vout
    [LTC3556_pcb_5off_datasht (2).kicad_sch]
2025-01-07 Add files via upload
    I corrections for the ERC errors from 25 to 14 power flags. I will continue to correct PMIC layout this week. i will work on footprint also.
    [LTC3556_pcb_4off_datasht.kicad_Ver_1.0_sch.kicad_sch]
2025-01-08 Add files via upload
    I redrew PMIC schematic but there are still two errors. I do not believe I can tie Pins 1 and 24 together for the one error. The other error relates to Pin-10, which i will correct
    [LTC3556_pcb_4off_datasht.kicad_sch-1.kicad_sch]
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2025-01-09 Update stm32_official_prototype.kicad_sch
    working on adding circuit breakers (0 ohm resistors) to each exposed pin
    [stm32_official_prototype.kicad_sch]
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2025-01-11 stm32 board update (1.11.25)
    - correcting footprints (IP)
    - left off on USB circuitry
    - note: net labels must be corrected for differential pair
    [stm32_official_prototype.kicad_pcb, stm32_official_prototype.kicad_sch]
2025-01-14 stm32 PCB board ~50% finished
    - left off on verifying button footprint
    (im trying to follow the original manufacturer BOM as much as possible, but some parts aren't downloadable.
    - best solution is to use the notes column in the BOM, describes what the footprint is (SMT, 6x6mm, tactile switch, etc.)
    [stm32_official_prototype.kicad_pcb, stm32_official_prototype.kicad_sch]
2025-01-14 stm32 pcb update for (1.13.25)
    - most components are now connected
    - need to verify a few more footprints
    - board is ~65% finished
    [stm32_official_prototype.kicad_pcb, stm32_official_prototype.kicad_sch]
2025-01-15 ADS1299 progress (1.14.25)
    - finalizing ads1299 schematic
    - left off on power supply circuitry
    [ads1299_official_prototype.kicad_pcb, ads1299_official_prototype.kicad_sch]
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2025-01-23 ads1299 PCB update (1.22.25)
    - left off on figuring out all the "Not Installed" footprints
    - some components may have the wrong designator
    - some components are missing footprints
    [ads1299_official_prototype.kicad_pcb, ads1299_official_prototype.kicad_sch]
2025-01-24 stm32 PCB update - 70% finished (1.23.25)
    - this board will definitely be ordered by next friday
    - left off on completing routing within the signal layer (3)
    - before i finalize i may need clarification on USB/power setup
    [stm32_official_prototype.kicad_pcb]
2025-01-26 STM32 board update (1.25.25)
    - vastly improved the layout
    - verified ALL footprints
    - implemented correct JLCPCB design rules
    - left off on labeling
    [stm32_official_prototype.kicad_pcb, stm32_official_prototype.kicad_sch]
2025-01-27 Add files via upload
    - 98% completed
    - Need to fix minor touch on silkscreen layer
    -Started searching manufacture parts on data sheet
    0 finalizing Gerber file last
    [BOM_LTC3556_v1.2a_.xlsx, LTC3556__v1.2a.kicad_sch, LTC3556_v1.2a.kicad_pcb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]
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2025-01-29 toreyin meeting stm32 board update (1.29.25)
    - I MUST NOT FORGET DIFFERENTIAL ROUTING FOR USB
    - i need like 10 pins to wire, difficult at this point to get through the entire spider web of traces
    - buttons, USB, LEDs, and power network need to be connected to main circuit
    - we for sure ordering this week
    [stm32_official_prototype.kicad_pcb, stm32_official_prototype.kicad_sch]
2025-01-31 original gerber files provided by TI
    original gerber files provided by TI
    - open all these files at once in KiCad Gerber Viewer
    - shows the entire eval.kit layout that you can deconstruct layer by layer (not component by component)
    [ads1299_a.GBL, ads1299_a.GBO, ads1299_a.GBS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]
2025-01-31 ads1299 update (1.30.25)
    - omit all NI components
    - i still think it is a good idea to expose all pins for now, so i left off on implementing "Figure 62. ECG MDK Board Interface Adapter"
    [ads1299_official_prototype.kicad_pcb, ads1299_official_prototype.kicad_sch]
2025-02-03 stm32 board update (2.2.25)
    all...144 pins...are wired.
    - still need to connect power circuitry to chip
    - still need to connect USB circuitry to chip
    - run by Mark Bruno tmrw --> order right away after
    [stm32_official_prototype.kicad_pcb]
2025-02-05 first update of the day (2.5.25)
    - footprints need to be verified
    - layout needs to be optimized
    [ads1299_official_prototype.kicad_pcb, ads1299_official_prototype.kicad_sch]
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2025-02-05 Add files via upload
    -Added TC7660EOA charge pump for AFE -2.5V AVSS
    - Ppdated integration of both U1 and U2 IC's, V_Out I/O connections.
    [BOM_LTC3556_v1.2a_.xlsx, LTC3556_v1.2a.kicad_pcb, LTC3556_v1.2a.kicad_sch]
2025-02-06 ads1299 board 3rd update of today (2.5.25)
    - still need to finish implementing barreljack and ECG power supply circuitry (both schematic/layout)
    [ads1299_official_prototype.kicad_pcb, ads1299_official_prototype.kicad_sch]
2025-02-07 Add files via upload
    - PMIC, LTC3556 and charge Pump, TC7660EOA 98% completed
    - Made corrections to 4-layer board, copper traces, via's grounds VOUT's vias corrections and ERC errors and warning corrections completed
    - Added -2.5V AFE output for AVSS via (charge pump)
    - will completed Gerber @ final step for JLCPCB
    - We have the option for JLCPCB to assemble board for us
    [BOM_LTC3556_v1.2a_ (1).xlsx, LTC3556_v1.2a.kicad_pcb]
2025-02-09 barrel jack update ads1299 (2.8.25)
    - schematic seems to be done
    - might have some power flag issues
    - many components require footprint assignments still, base those footprints off the ADS1299 BOM
    [ads1299_official_prototype.kicad_sch]
2025-02-09 legit stm32 schematic (2.8.25)
    - removed most if not all redundant short breakers
    - implemented extra safeguard for temporary power supply
    - BOARD IS SUPPLIED THROUGH +3V3 pin 16 on connector CN11
    [stm32_official_prototype.kicad_sch]
2025-02-09 Add files via upload
    - updated STM32_3V3 with screw terminal on schematic
    - increased Power Vout1, Vout2, Vout3 and, Inductors traces thickness
    - clean up organize component placement--
    - close to having design board completed
    [BOM_LTC3556_v1.2a_ (1).xlsx]
2025-02-10 layout finish, clearing all DRC errors stm32 update (2.9.25)
    [stm32_official_prototype.kicad_pcb, stm32_official_prototype.kicad_sch]
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2025-02-11 Add files via upload
    Please see the latest LTC3556v2.0 updated project file
    [BOM_LTC3556_v1.2a_ (1).xlsx, LTC3556__v1.2a.kicad_sch, LTC3556_v2.0.kicad_pcb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]
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2025-02-14 Revert "Add firmware project to git."
    This reverts commit e69bf5e09d36e8360c9e7194ebd920edb41fe854.
    [stm32_official_prototype.kicad_pcb, stm32_official_prototype.kicad_sch]
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2025-02-14 fixing duplicate folders
    [BOM.xlsx, BOM_LTC3556_v1.2a_ (1).xlsx, BOM_LTC3556_v1.2a_.xlsx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]
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2025-02-14 fix duplicate directories
    [BOM.xlsx, BOM_LTC3556_v1.2a_ (1).xlsx, BOM_LTC3556_v1.2a_.xlsx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]
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2025-02-14 Add footprints zip that was lost during fixing
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2025-02-17 Add files via upload
    - Team still is the final PMIC: PCB layout, footprint
    - Schematic drawing
    -3D model-errors: zero
    -Read to create Gerber file
    [LTC3556_v2.2.kicad_pcb, LTC3556_v2.2.kicad_sch]
2025-02-19 Add files via upload
    Team: here is the final version files of PMIC: LTC3556 and TC7760EOA
    - Schematic diagram
    -PCB layout and 3D model
    - 4Layer PCB
    - Production Gerber files
    - cleaned up the placement for ADS1299, AFE and STM32 connection female pins
    [Bill Of Materials, LTC3556_v2.3.xlsx]
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2025-02-20 Update LTC to add JLC MPNs and fix JST plug
    [LTC3556_v2.3.kicad_pcb, LTC3556_v2.3.kicad_sch]
2025-02-20 Update PMIC board: edit resistor values, added MPN numbers, fixed headers
    [LTC3556_v2.3.kicad_pcb, LTC3556_v2.3.kicad_sch, bom.csv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]
2025-02-22 Add files via upload
    -Team here is the final version of LTC3556,_v2.4, BOM. and Gerbers files
    - RDC error are zero, zero warnings
    [Bill Of Materials, LTC3556_v2.4.xlsx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]
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2025-02-22 Schematic changes, no more power stuff from external board. Layout work, added power stuff, lots to do
    [ads1299_official_prototype.kicad_pcb, ads1299_official_prototype.kicad_sch]
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2025-02-23 Fix PMIC files
    [Bill Of Materials, LTC3556_v2.4.xlsx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]
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2025-02-23 Fix STM floating gnd
    [stm32_official_prototype.kicad_pcb]
2025-02-23 Schematic and PCB Update, new folder for updates in working prototype
    ads1299 working prototype has folder for updated schematic and PCB now. Schematic update with J3 proper symbol, layout removing the unipolar power portions.
    [24AA256-I_ST.step, ads1299_official_prototype.kicad_pcb, ads1299_official_prototype.kicad_sch]
2025-02-24 Schematic and Layout updates
    Added Bias stuff, routing now and updates from Schematic to Layout working beautifully now. trying to figure out if the capacitors are currently hooked up correctly for AVSS and AVDD or if we need more, not sure if the eval is following a unipolar or bipolar setup
    [ads1299_official_prototype.kicad_pcb, ads1299_official_prototype.kicad_sch]
2025-02-25 Only thing left is the AVDD power routing, not sure if we can just connect that to power plane or not. Also ground plane, then done
    [ads1299_official_prototype.kicad_pcb, ads1299_official_prototype.kicad_sch]
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2025-03-11 Add new PMIC board version for phase 2 after bugs found in integration testing
    [power_manager.kicad_pcb, power_manager.kicad_sch]
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2025-04-02 Added ECG portions to the final, corrected -5 points
    [final_handsEMG.kicad_pcb, final_handsEMG.kicad_sch, power_manager.kicad_pcb]
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2025-04-06 fixed and organized schematic (4.6.25)
    [final_handsEMG.kicad_sch]
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

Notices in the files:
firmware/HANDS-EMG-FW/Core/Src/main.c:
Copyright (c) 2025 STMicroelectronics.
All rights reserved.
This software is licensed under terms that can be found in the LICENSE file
